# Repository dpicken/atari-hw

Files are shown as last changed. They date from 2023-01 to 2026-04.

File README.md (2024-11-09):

# atari-hw

Atari 8-bit hardware projects.

- [Small Form Factor (SFF) Atari 8-bit compatible system](/doc/sbc.md)
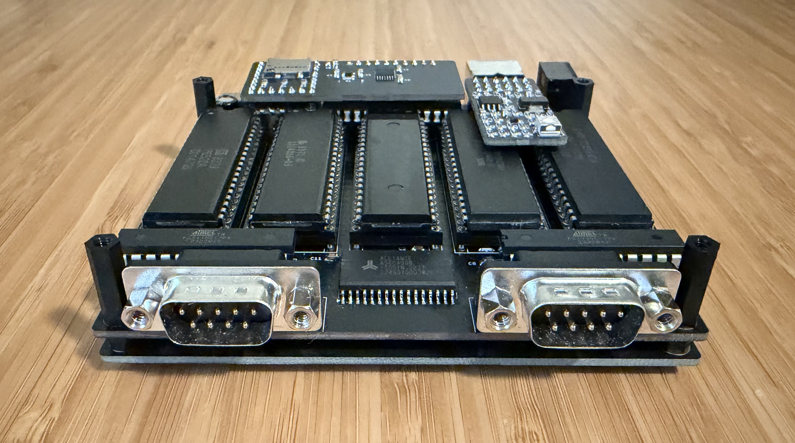
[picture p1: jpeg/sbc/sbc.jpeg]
  

- [USB Keyboard Controller for Atari XL/XE computers](/doc/keyboard-usb-qtpy.md)
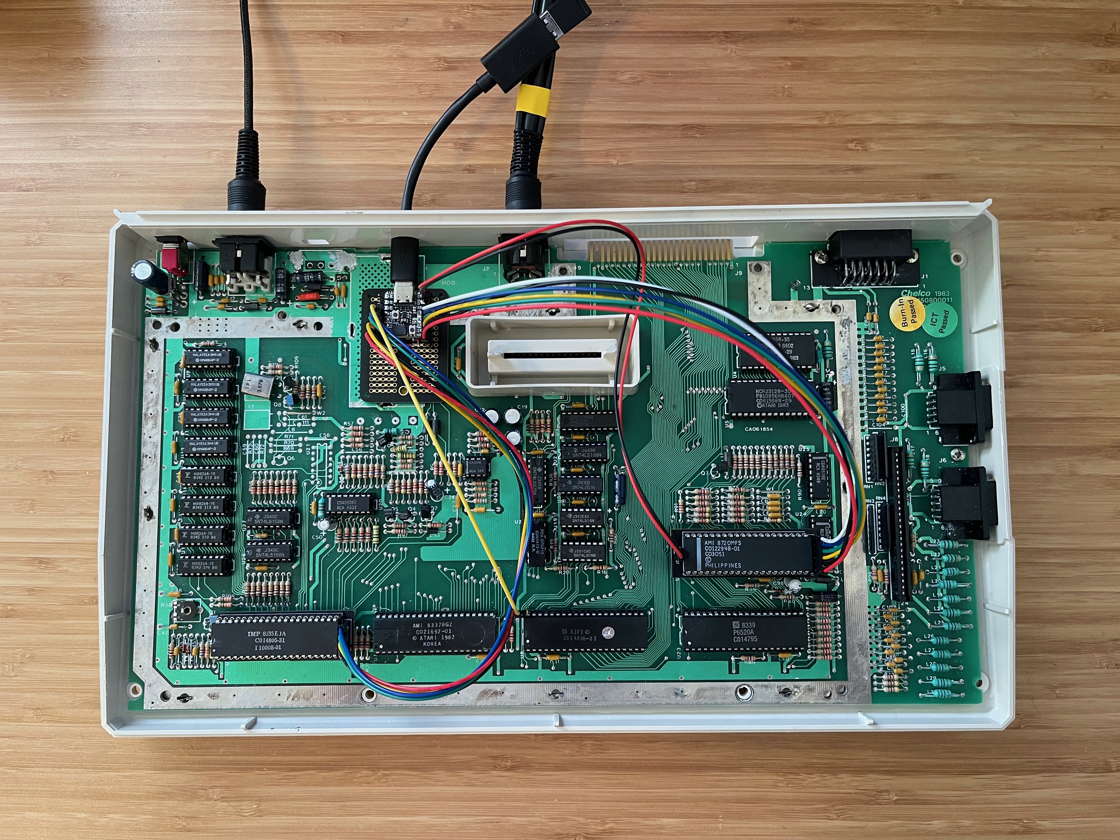
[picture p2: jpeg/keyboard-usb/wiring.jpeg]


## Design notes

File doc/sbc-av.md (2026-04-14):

# SFF Audio/Video adapter

Audio/video adapter for the [SFF system](https://github.com/dpicken/atari-hw/blob/master/doc/sbc.md).

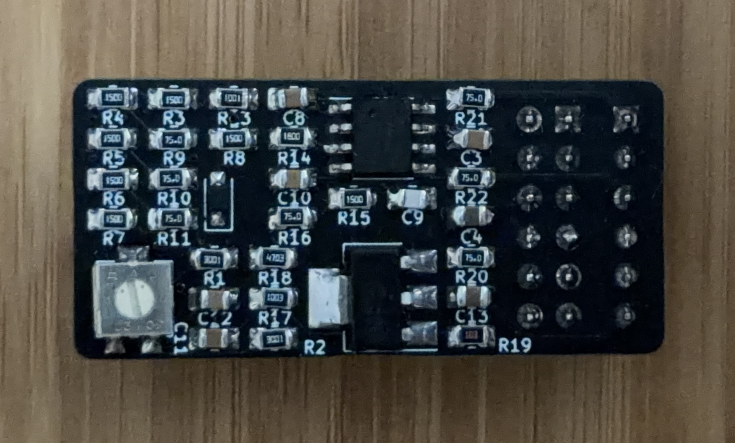
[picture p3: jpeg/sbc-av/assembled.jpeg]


- [Schematic](/pdf/sbc-av-schematic.pdf)
- [Layout](/pdf/sbc-av-layout.pdf)
- [Gerber](https://github.com/dpicken/atari-hw/raw/master/gerber/sbc-av.zip)
- [BOM](/pdf/sbc-av-bom.pdf)

# Assembly notes

Solder the FMS6400 first, then the remaining SMT components.  Ensure the pin headers are installed on the rear of the board.

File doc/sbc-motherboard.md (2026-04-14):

# SFF Motherboard

Motherboard for the [SFF system](https://github.com/dpicken/atari-hw/blob/master/doc/sbc.md).

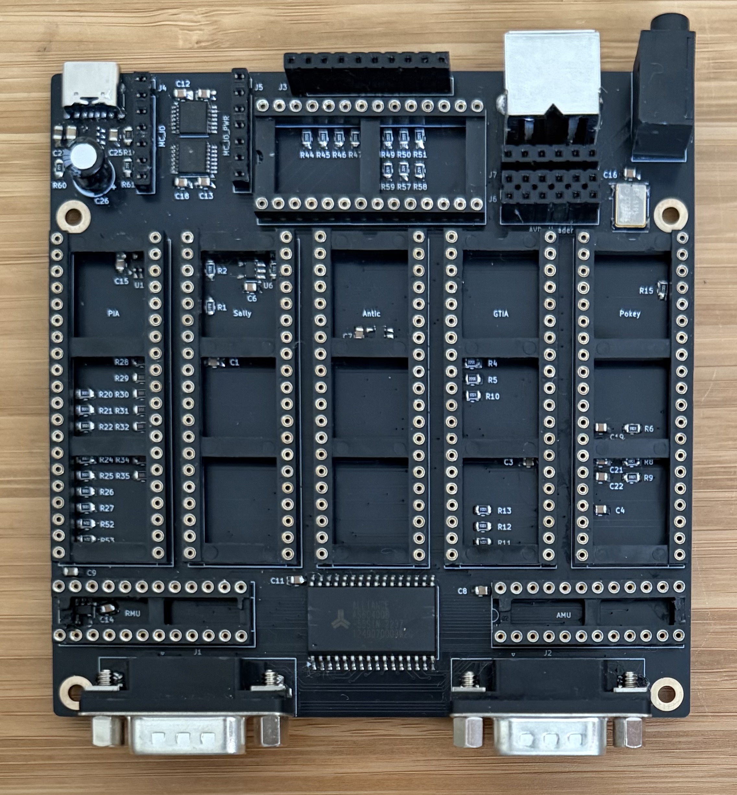
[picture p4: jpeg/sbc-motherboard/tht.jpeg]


- [Schematic](/pdf/sbc-schematic.pdf)
- [Layout](/pdf/sbc-layout.pdf)
- [Gerber](https://github.com/dpicken/atari-hw/raw/master/gerber/sbc.zip)
- [BOM](/pdf/sbc-bom.pdf)

# Assembly notes

Solder the SMT components first, starting with the power section, then the voltage level translators, then the oscillator and finally the remaining components:

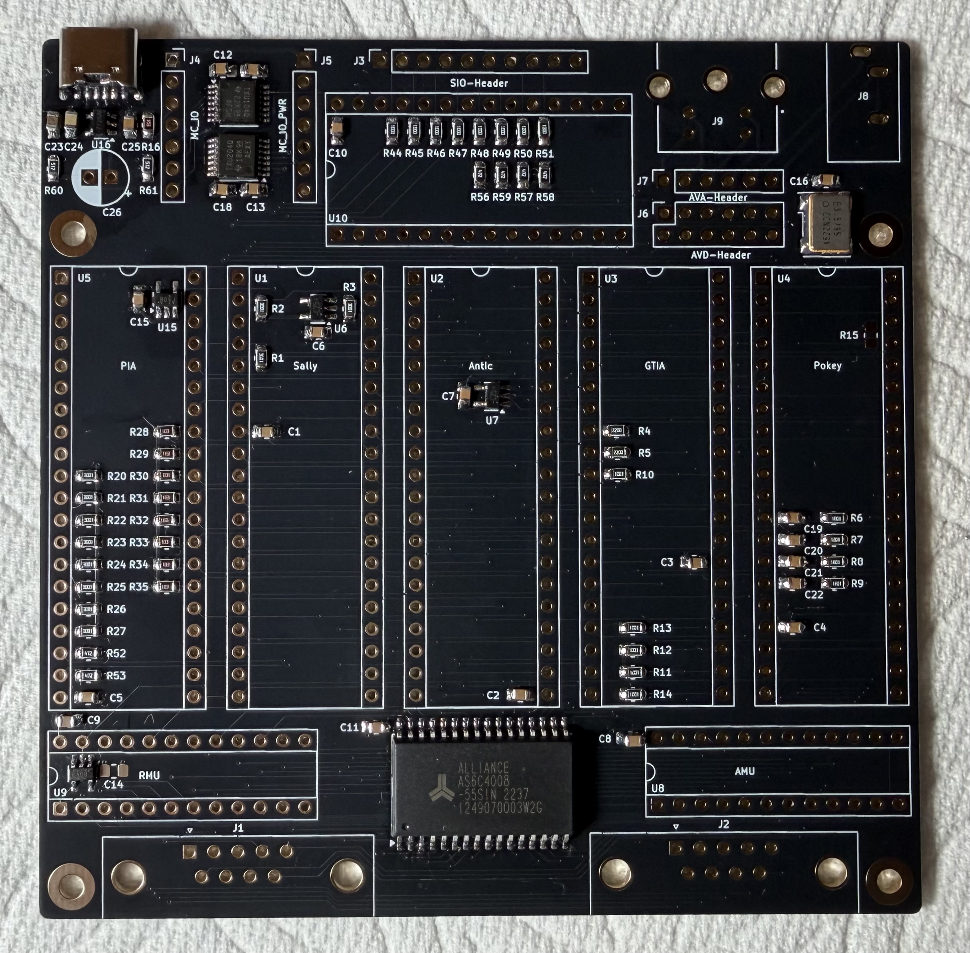
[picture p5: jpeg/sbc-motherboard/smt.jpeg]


Solder the THT components, then install the ICs (flash the ROM, AMU and RMU first):

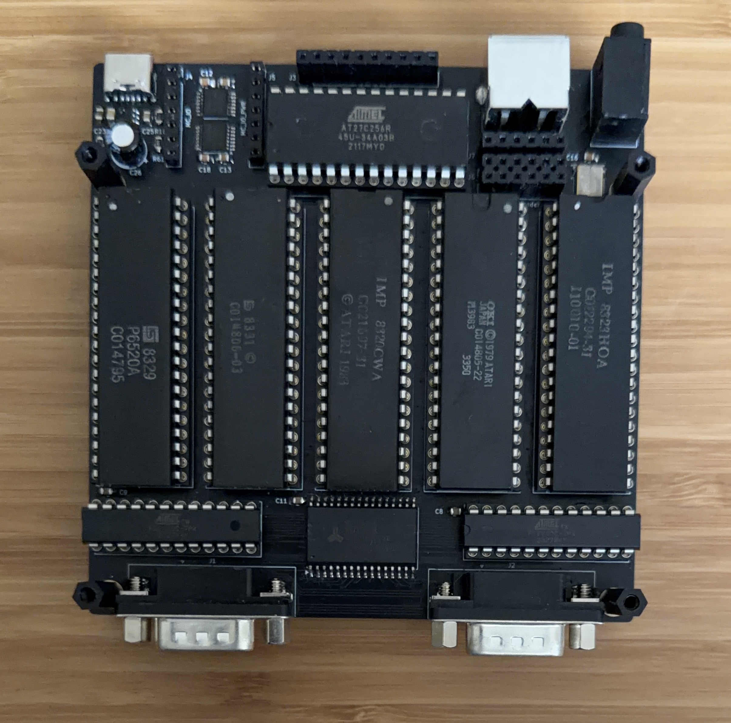
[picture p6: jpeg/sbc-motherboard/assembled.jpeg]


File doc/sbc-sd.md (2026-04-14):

# SFF SD card adapter

An SD card adapter / SIO peripheral emulator for the [SFF system](https://github.com/dpicken/atari-hw/blob/master/doc/sbc.md).

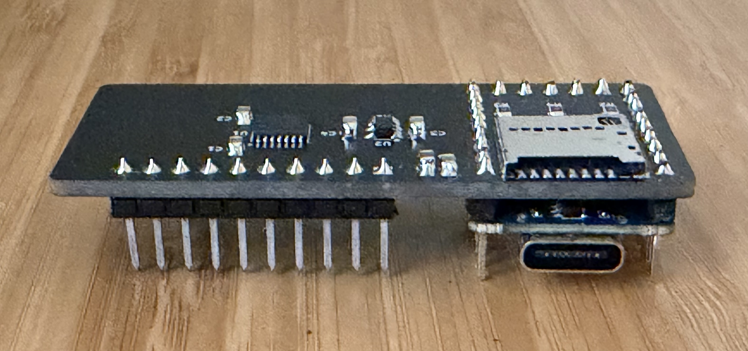
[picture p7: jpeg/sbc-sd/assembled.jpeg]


- [Schematic](/pdf/sbc-sd-schematic.pdf)
- [Layout](/pdf/sbc-sd-layout.pdf)
- [Gerber](https://github.com/dpicken/atari-hw/raw/master/gerber/sbc-sd.zip)
- [BOM](/pdf/sbc-sd-bom.pdf)

The firmware supports:

- Emulating an Atari disk drive (D1)
- Loading ATR and XEX images from the microcontroller's flash
- Loading ATR and XEX images from an exFat formatted SD card

# Assembly notes

Solder the SD card socket first, then the remaining SMT components:

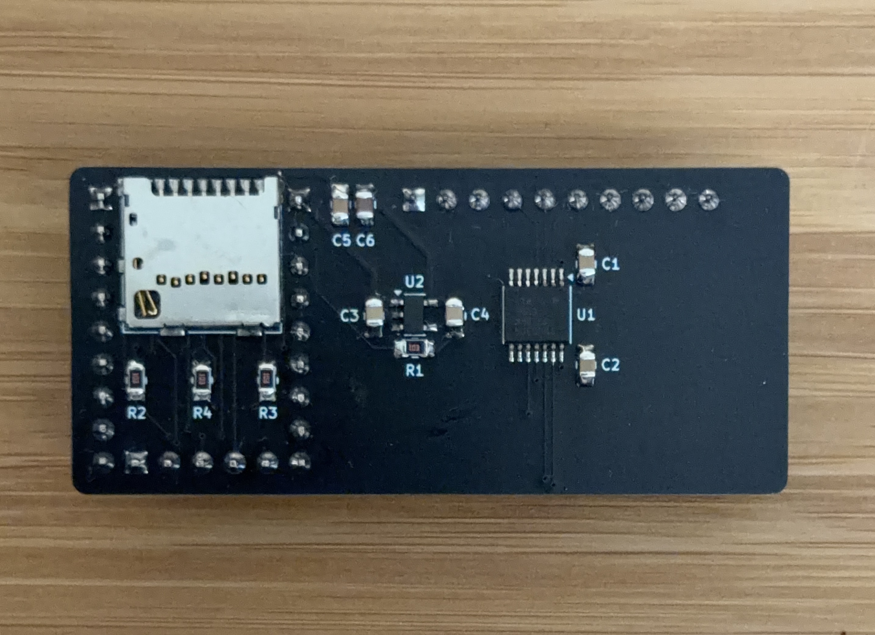
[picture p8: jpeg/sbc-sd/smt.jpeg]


Solder pin headers to the rear of the board and finally the waveshare RP2040:

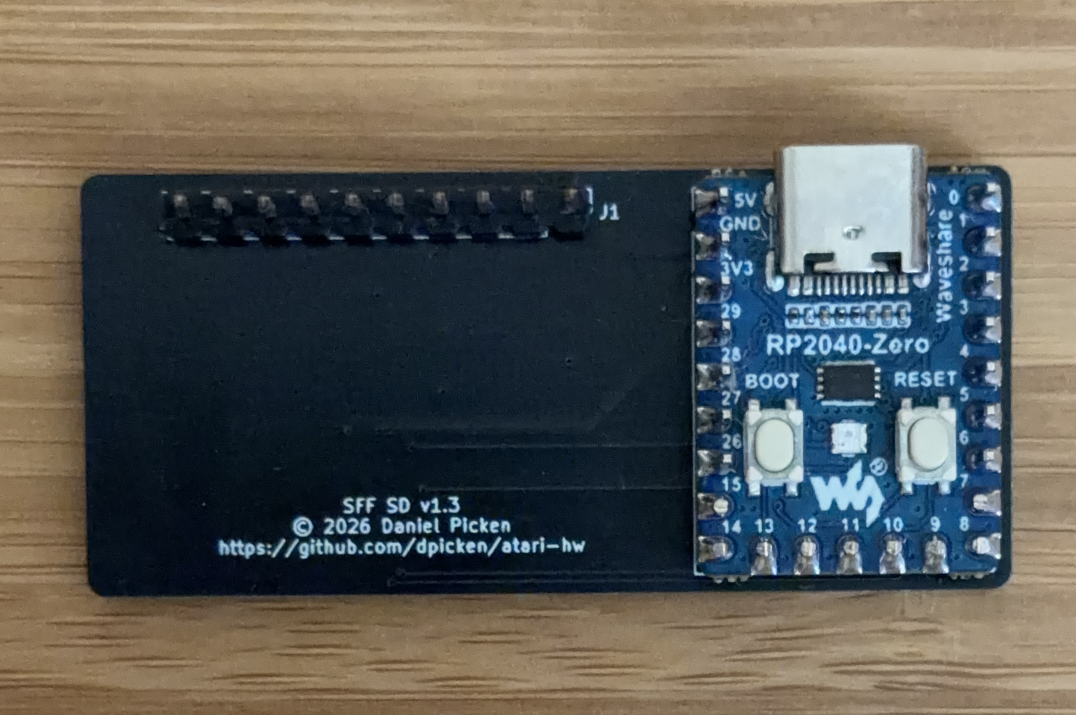
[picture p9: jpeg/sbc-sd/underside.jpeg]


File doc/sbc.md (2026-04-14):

# Small Form Factor (SFF) Atari 8-bit compatible system

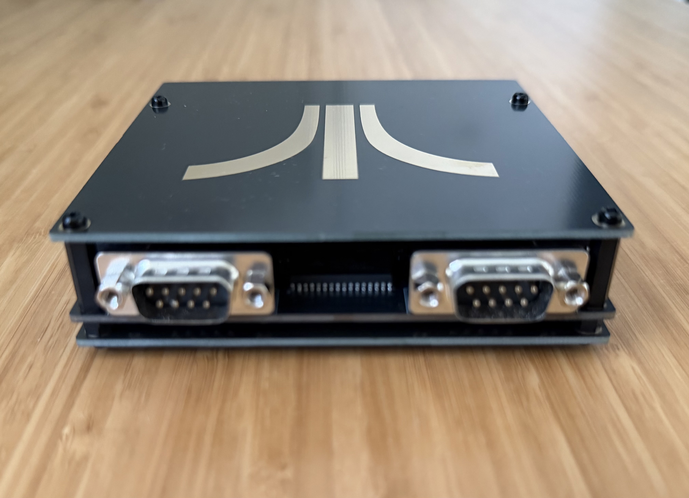
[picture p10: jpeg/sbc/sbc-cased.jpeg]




Specs:

- Original Atari chipset (Sally, Antic, GTIA, Pokey, PIA)
- Two simple programmable logic devices (ATF22V10C) implement address-space decoding and extended RAM:
  - AMU ("Address Management Unit") decodes the 16 bit address space
  - RMU ("Ram Management Unit") supports 320 KiB (compy or rambo) or 128 KiB (130XE) or 64 KiB (65XE) RAM
- 32 KiB ROM (OS, BASIC)
- Audio/Video header
- S-Video connector
- 3.5mm audio socket
- SIO header
- USB-C power socket
- Raspberry Pi RP-series microcontroller provides:
  - USB keyboard interface
  - SIO disk drive (D1)
  - SIO file system device (ATR and XEX image selection)
  - microSD card support (SD, SDHC, SDXC, exFAT)

Hardware:

- [SFF Motherboard](/doc/sbc-motherboard.md)
- [SFF Audio/Video adapter](/doc/sbc-av.md)
- [SFF SD card adapter](/doc/sbc-sd.md)
- [SFF Case](/doc/sbc-case.md)

Key map:

| USB Key  | Atari Key or Action |
|---|---|
| F1 | Help |
| F2 | Start |
| F3 | Select |
| F4 | Option |
| F10 | D1: insert !sbc-filer.xex (file system UI) |
| F11 | D1: eject |
| F12 | Reset |
| Ctrl-F12 | Toggle power on/off |

Atari self-test:

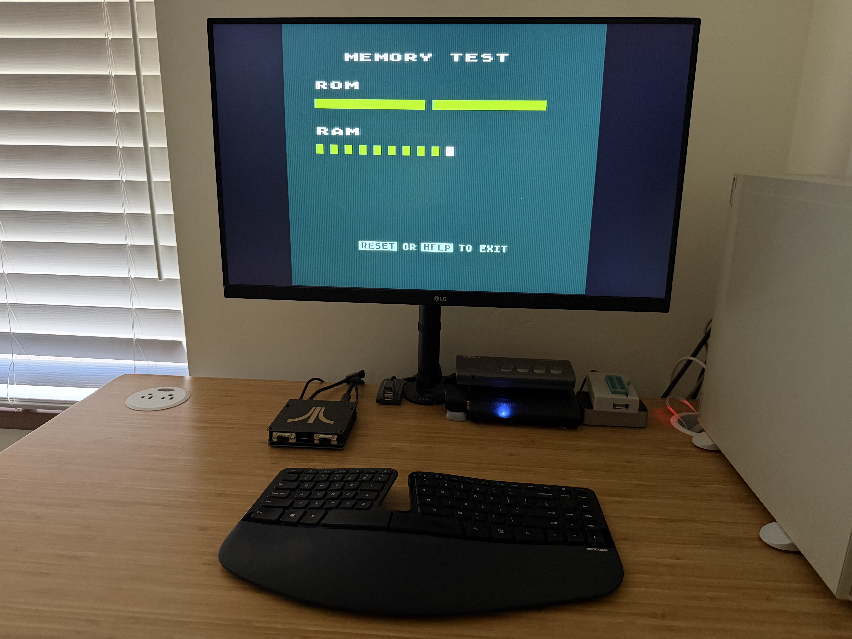
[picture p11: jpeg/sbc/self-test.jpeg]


File System UI:



Load a game:

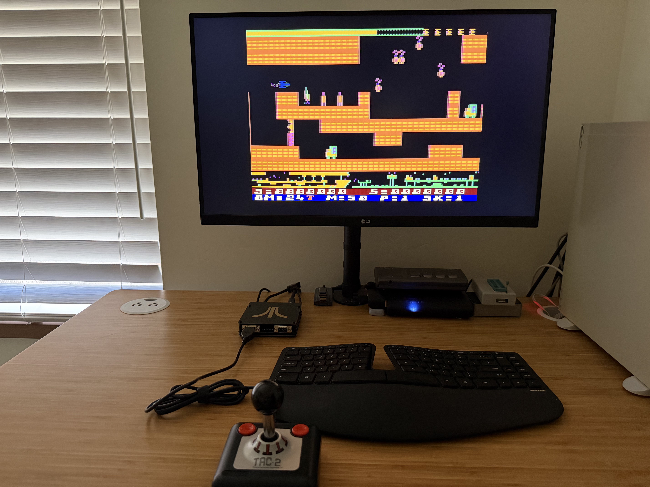
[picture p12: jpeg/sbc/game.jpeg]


## Build ROM, AMU, RMU and RP-series microcontroller images

Clone the following repos:

    git clone https://github.com/dpicken/atari-hw.git
    git clone https://github.com/dpicken/atari-fw.git
    git clone https://github.com/dpicken/fab.git

Acquire Atari's XL/XE OS and BASIC ROM images and copy them to `./atari-hw/third-party/rom`, e.g.

    cp ~/Downloads/OS_REV3_XE.rom ./atari-hw/third-party/rom/os.rom
    cp ~/Downloads/BASIC_C.rom    ./atari-hw/third-party/rom/basic.rom
    make -C ./atari-hw roms

Optional: To (re)build the (pre-built) AMU and RMU images, install [rust](https://www.rust-lang.org/tools/install), then install [galette](https://github.com/simon-frankau/galette), e.g.

    git clone https://github.com/simon-frankau/galette
    bash -c "cd galette; cargo build --release"
    cp galette/target/release/galette ~/bin/
    PATH=$PATH:~/bin
    make -C ./atari-hw distribute

Optional: To (re)build the (pre-built) RP-series microcontroller firmware:

    make -C ./atari-fw distribute

## Install images

The ROM, AMU and RMU can be programmed with a `TL866 II Plus` and the `minipro` software.  Install the minipro, e.g.

    brew install minipro

Change into the atari-hw repo:

    cd ./atari-hw

### AMU

To program the AMU with support for 320 KiB RAM (compy, separate Sally/Antic banking):

    make install-prebuilt-jed-amu320compy

To program the AMU for all other RAM configurations:

    make install-prebuilt-jed-amu

### RMU

To program the RMU with support for 320 KiB RAM (compy, separate Sally/Antic banking):

    make install-prebuilt-jed-rmu320compy

To program the RMU with support for 320 KiB RAM (rambo, combined Sally/Antic banking):

    make install-prebuilt-jed-rmu320rambo

To program the RMU with support for 128 KiB RAM (130XE, separate Sally/Antic banking):

    make install-prebuilt-jed-rmu130xe

To program the RMU with support for 64 KiB RAM (65XE / 800XL):

    make install-prebuilt-jed-rmu65xe

### ROM

A 27C256 compatible ROM/EPROM/EEPROM provides the OS and BASIC.

To program a AT27C256 OTP ROM:

    make install-sbc-rom-256

To program a W27C512 EEPROM:

    make install-sbc-rom-512

### RP-series microcontroller

The following RP2040/RP2350 boards are supported:

  - [waveshare rp2040 zero](https://www.waveshare.com/rp2040-zero.htm) (supports a USB keyboard, builtin ATR/XEX library and [SFF SD card adapter](https://github.com/dpicken/atari-hw/blob/master/doc/sbc-sd.md))
  - [pimoroni tiny2350](https://shop.pimoroni.com/products/tiny-2350?variant=42092638699603) (supports a USB keyboard and builtin ATR/XEX library)
  - [adafruit qtpy rp2040](https://www.adafruit.com/product/4900) (supports a USB keyboard and builtin ATR/XEX library)

Connect a supported board to the build host, then boot it into it's bootloader (hold the boot button then press and release the reset button).  Next, copy the appropriate firmware to the `RPI-RP2` drive/mount (adjust the `RP_MOUNT` option as necessary)...

To program a waveshare rp2040 zero:

    RP_MOUNT=/Volumes/RPI-RP2 make install-prebuilt-rp-fw-waveshare_rp2040_zero

To program a pimoroni tiny2350:

    RP_MOUNT=/Volumes/RP2350 make install-prebuilt-rp-fw-pimoroni_tiny2350

To program an adafruit qtpy rp2040:

    RP_MOUNT=/Volumes/RPI-RP2 make install-prebuilt-rp-fw-adafruit_qtpy_rp2040

(See [atari-fw](https://github.com/dpicken/atari-fw) for the firmware source and for instructions for building firmware with a custom builtin ATR/XEX library).

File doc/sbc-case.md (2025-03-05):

# SFF Case

A skeletal "case" - lid and base - for the [SFF system](https://github.com/dpicken/atari-hw/blob/master/doc/sbc.md).

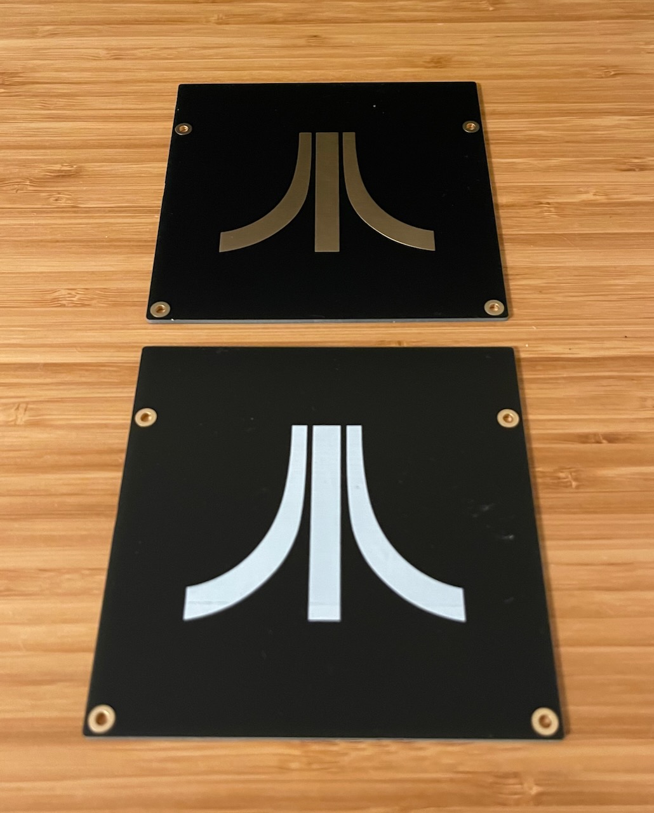
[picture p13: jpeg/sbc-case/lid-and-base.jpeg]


- [Layout](/pdf/sbc-case-layout.pdf)
- [Gerber (lid)](https://github.com/dpicken/atari-hw/raw/master/gerber/sbc-case-cu.zip)
- [Gerber (base)](https://github.com/dpicken/atari-hw/raw/master/gerber/sbc-case-silk.zip)
- M2.5 standoffs (e.g. [brass](https://www.amazon.com/dp/B075K3QBMX?_encoding=UTF8&psc=1&ref_=cm_sw_r_cp_ud_dp_07SERFYACEF07RKSJ5DF) or [nylon](https://www.amazon.com/dp/B07DCM1LGF?_encoding=UTF8&psc=1&ref_=cm_sw_r_cp_ud_dp_D1Y9YNHXQJMQRCN7T3VB))

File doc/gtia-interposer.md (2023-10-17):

# GTIA Interposer

Breaks out the start, select and option signals and performs 5V <-> 3.3V level conversion:

- [Schematic](/pdf/gtia-interposer-schematic.pdf)
- [Layout](/pdf/gtia-interposer-layout.pdf)
- [BOM](/pdf/gtia-interposer-bom.md)

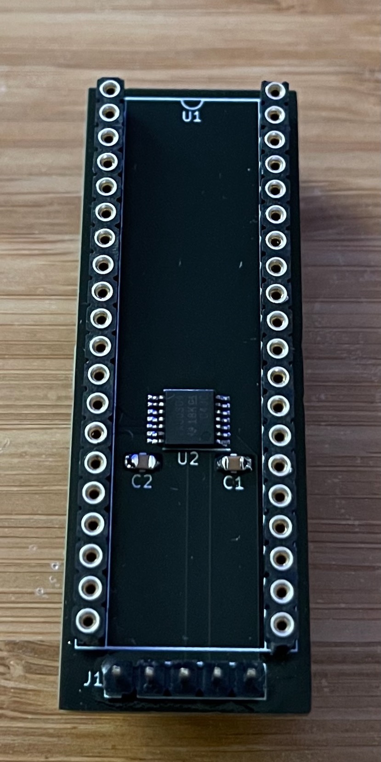
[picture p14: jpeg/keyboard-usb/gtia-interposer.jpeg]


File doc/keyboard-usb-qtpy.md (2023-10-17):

# USB Keyboard Controller

Proof-of-concept USB keyboard controller for 8-bit Atari systems.

Limitations:

- Atari keyboard is not usable whilst the controller is powered (the POKEY and GTIA level shifters are permanently enabled).
- The controller's /RESET signal is not level shifted (not a problem in practice)

## BOM

- [Adafruit QT Py RP2040](https://www.adafruit.com/product/4900)
- [POKEY Interposer](/doc/pokey-interposer.md)
- [GTIA Interposer](/doc/gtia-interposer.md)
- Breadboard
- 2.54 mm pin headers
- 6 pin, 5 pin and 2 pin 2.54mm female jumper leads

## Assembly

It's advisable to flash the QT Py prior to installation.

Connect the QT Py to the build host, then boot it into it's bootloader (hold the boot button then press and release the reset button).  Next, copy the firmware to the `RPI-RP2` drive/mount (adjust the `RP2040_MOUNT` option as necessary):

    RP2040_MOUNT=/Volumes/RPI-RP2 RP2040_BOARD=adafruit_qtpy_rp2040 make install-prebuilt-rp2040-fw

(See [atari-fw](https://github.com/dpicken/atari-fw) for the firmware source).

If necessary, desolder POKEY and GTIA from the Atari PCB and install DIP sockets in their place.

The interposers use SMD components.  It is possible to hand solder them.  Basic requirements are a temperature controlled soldering iron, magnification, fine tweezers, plenty of flux, leaded solder and steady hands:

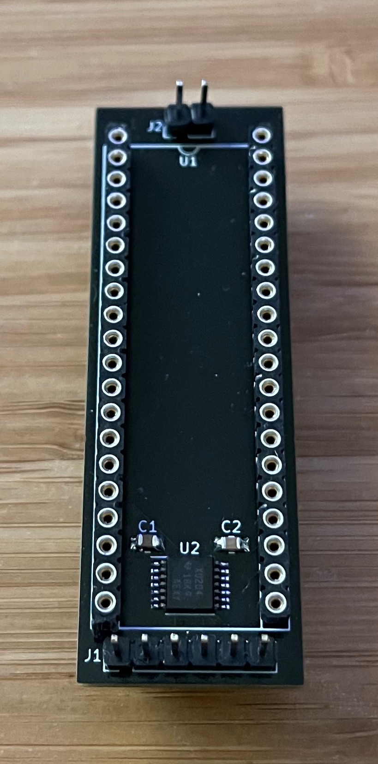
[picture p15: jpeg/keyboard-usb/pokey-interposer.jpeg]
 

The SIP socket strips are mounted on the top side of the interposers and soldered.  DIP sockets between an interposer and the Atari PCB socket may be necessary to establish good contact.  Insert GTIA and POKEY into their interposer:

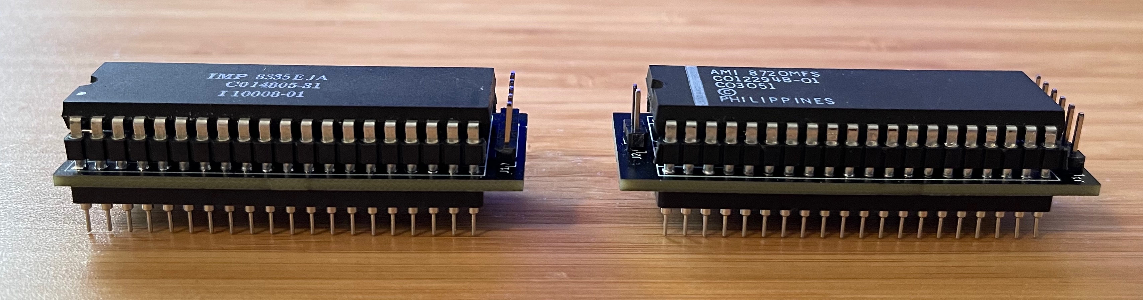
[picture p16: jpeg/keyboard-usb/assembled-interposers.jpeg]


Install the assembled interposers:

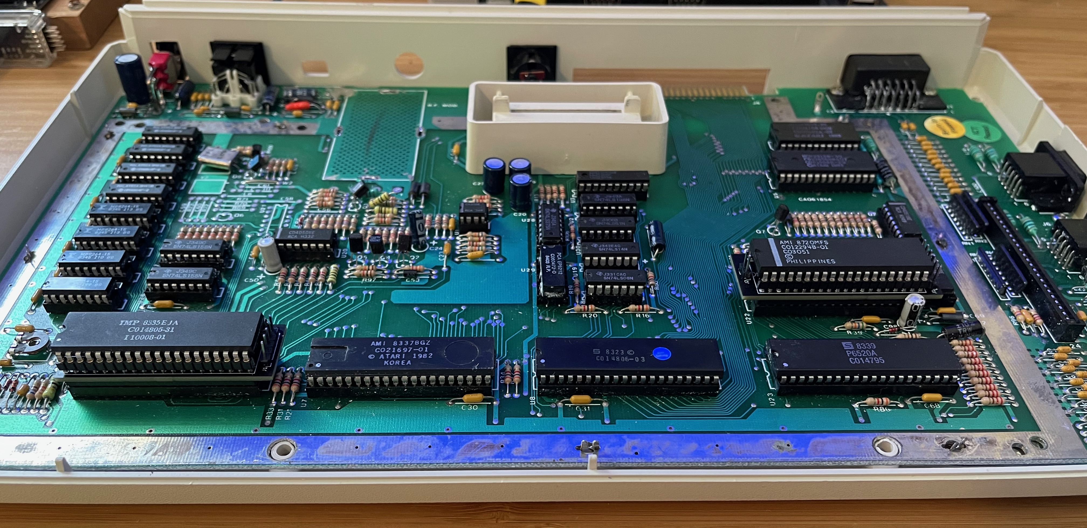
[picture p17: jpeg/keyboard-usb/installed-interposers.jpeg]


Bridge the 5V USB host jumper on the underside of the QT Py:

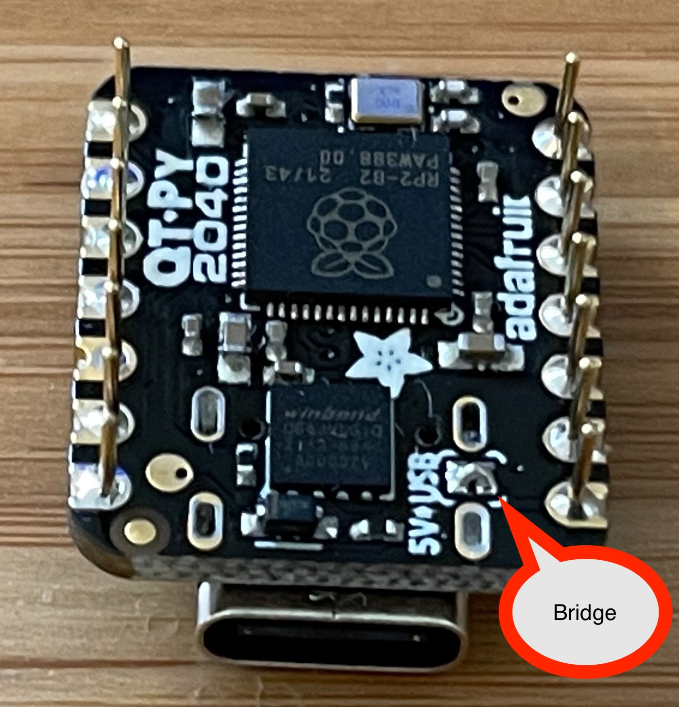
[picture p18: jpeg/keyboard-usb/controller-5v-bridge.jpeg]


Build a break-out board (on a soldered or solderless breadboard):

|QT Py|POKEY interposer J1|POKEY interposer J2|GTIA interposer J1 |65O2C  |
|-----|---|---|---|---|
|5V | |Pin 1 | | |
|3V |Pin 1 | |Pin 1 | |
|GND  |Pin 2 |Pin 2 |Pin 2 | |
|RX |Pin 3 | | | |
|SCK  |Pin 4 | | | |
|MI |Pin 5 | | | |
|MO |Pin 6 | | | |
|TX | | |Pin 3 | |
|SCL  | | |Pin 4 | |
|SDA  | | |Pin 5 | |
|A3 | | | |Pin 40 |

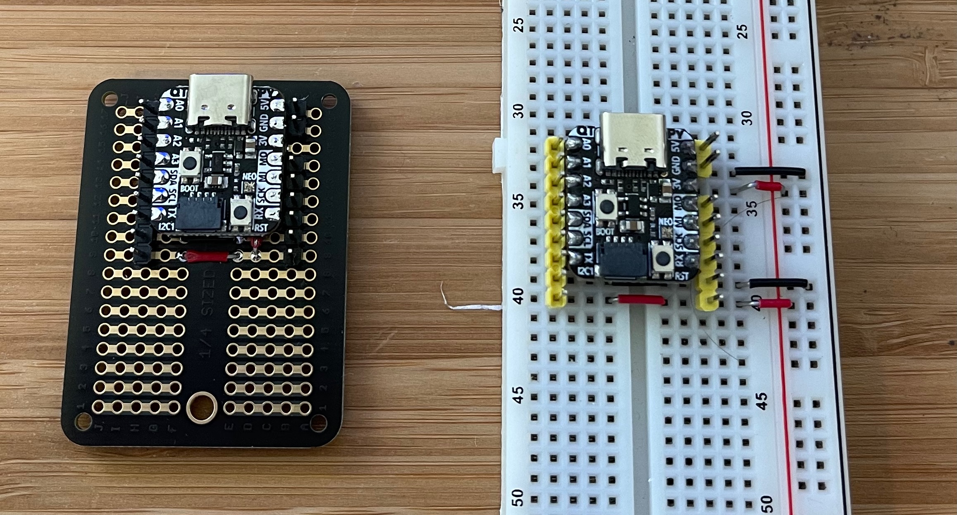
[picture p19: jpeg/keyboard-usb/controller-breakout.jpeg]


Connect the controller to the interposers with jumper cables:



Connect a USB keyboard:

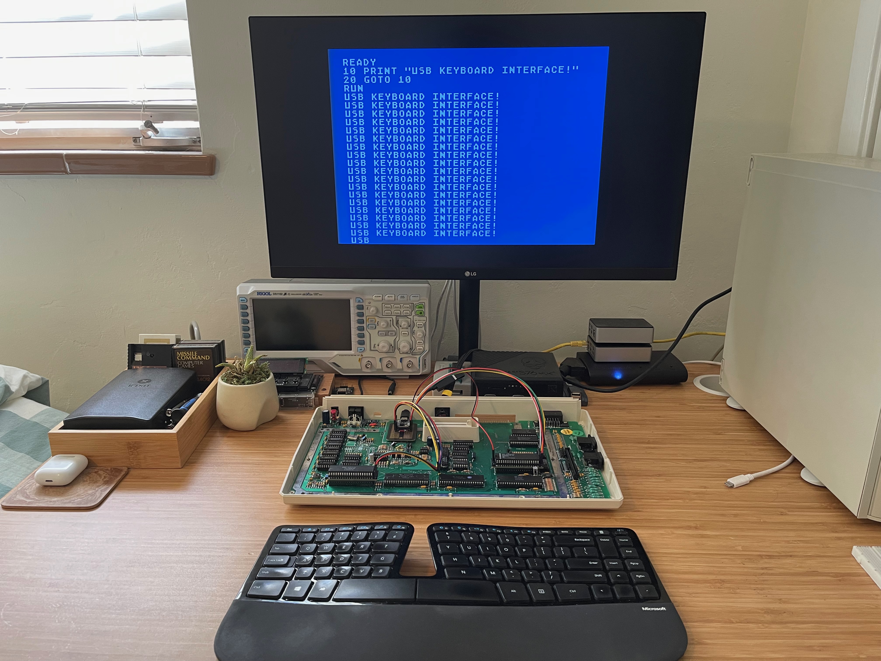
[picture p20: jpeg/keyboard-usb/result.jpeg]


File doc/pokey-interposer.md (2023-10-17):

# POKEY Interposer

Breaks out the K0, K5, KR1 and KR2 signals and performs 5V <-> 3.3V level conversion:

- [Schematic](/pdf/pokey-interposer-schematic.pdf)
- [Layout](/pdf/pokey-interposer-layout.pdf)
- [BOM](/pdf/pokey-interposer-bom.md)



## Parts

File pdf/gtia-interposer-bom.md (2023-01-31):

# GTIA Interposer BOM

|References|Quantity|Description|
|-|-|-|
|PCB|1|[Gerber](/gerber/gtia-interposer.zip), 0.8mm|
|C1, C2|2|[0.1uF MLCC capacitor, 0805](https://www.mouser.com/ProductDetail/80-C0805C104J1RECAUT)|
|J1|1|1x5 pin header, 2.54mm|
|U1|1|[SIP socket](https://www.newark.com/mill-max/311-93-164-41-001000/sip-socket-64-position-through/dp/17C4915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)|
|U2|1|[TXU0304PWR](https://www.mouser.com/ProductDetail/Texas-Instruments/TXU0304PWR?qs=QNEnbhJQKvZVYXIKZoXs0A%3D%3D)|

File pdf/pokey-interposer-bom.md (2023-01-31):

# Pokey Interposer BOM

|References|Quantity|Description|
|-|-|-|
|PCB|1|[Gerber](/gerber/pokey-interposer.zip), 0.8mm|
|C1, C2|2|[0.1uF MLCC capacitor, 0805](https://www.mouser.com/ProductDetail/80-C0805C104J1RECAUT)|
|J1|1|1x6 pin header, 2.54mm|
|J2|1|1x2 pin header, 2.54mm|
|U1|1|[SIP socket](https://www.newark.com/mill-max/311-93-164-41-001000/sip-socket-64-position-through/dp/17C4915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)|
|U2|1|[TXU0204PWR](https://www.mouser.com/ProductDetail/Texas-Instruments/TXU0204QPWRQ1?qs=QNEnbhJQKvbo%252BW7%2Fo1U3Qg%3D%3D)|

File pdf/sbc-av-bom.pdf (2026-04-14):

### sbc-av

Ref | Qnty | Value | Footprint | Vendor
C1, C2, C3, C7, C8, C10, C11, C12 | 8 | 0.1uF | Capacitor_SMD:C_0805_2012Metric_Pad1.18x1.45mm_HandSolder | https://www.mouser.com/ProductDetail/80-C0805C104J1RECAUT
C4, C13 | 2 | 10uF | Capacitor_SMD:C_0805_2012Metric_Pad1.18x1.45mm_HandSolder | https://www.mouser.com/ProductDetail/KEMET/C0805C106K8RACTU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
C5, C6 | 2 | 3.3uF | Capacitor_SMD:C_0805_2012Metric_Pad1.18x1.45mm_HandSolder | https://www.mouser.com/ProductDetail/KEMET/C0805C335K4PACTU?qs=p39qgscUv00TDoKitDBNnA==
C9 | 1 | 100pF | Capacitor_SMD:C_0805_2012Metric_Pad1.18x1.45mm_HandSolder | https://www.mouser.com/ProductDetail/KEMET/C0805C101J5RACTU?qs=1CrpdQ4AkN/JNeoQfmjuPQ==
D1 | 1 | BAT48JFILM | Diode_SMD:D_SOD-323_HandSoldering | https://www.mouser.com/ProductDetail/STMicroelectronics/BAT48JFILM?qs=jZi1jxfVU96ub22u%2BA2DtA==
J1 | 1 | AVD-Header | Connector_PinHeader_2.54mm:PinHeader_2x06_P2.54mm_Vertical | https://www.mouser.com/ProductDetail/Amphenol-Commercial-Products/G800W590018EU?qs=f9yNj16SXrJ2iQOlqHgQ/g==
J2 | 1 | AVA-Header | Connector_PinHeader_2.54mm:PinHeader_1x06_P2.54mm_Vertical | https://www.mouser.com/ProductDetail/Amphenol-Commercial-Products/G800W302018EU?qs=f9yNj16SXrLA3jMaFoRlOg==
Q1 | 1 | PZT2222A | Package_TO_SOT_SMD:SOT-223-3_TabPin2 | https://www.mouser.com/ProductDetail/onsemi/PZT2222AT1G?qs=xZq1yRCsb1df8552Y4NpWQ==
R1, R2 | 2 | 3K | Resistor_SMD:R_0805_2012Metric_Pad1.20x1.40mm_HandSolder | https://www.mouser.com/ProductDetail/Panasonic/ERJ-P06F3001V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
R3, R4, R5, R6, R7, R8, R15 | 7 | 150R | Resistor_SMD:R_0805_2012Metric_Pad1.20x1.40mm_HandSolder | https://www.mouser.com/ProductDetail/Panasonic/ERJ-P06D1500V?qs=18kBAoNi3c%2BFXxCt8eyIyw==
R9, R10, R11, R16, R20, R21, R22 | 7 | 75R | Resistor_SMD:R_0805_2012Metric_Pad1.20x1.40mm_HandSolder | https://www.mouser.com/ProductDetail/Panasonic/ERJ-P06D75R0V?qs=18kBAoNi3c%2B6dPCNnYzSiQ==
R13 | 1 | 1K | Resistor_SMD:R_0805_2012Metric_Pad1.20x1.40mm_HandSolder | https://www.mouser.com/ProductDetail/Panasonic/ERJ-P06F1001V?qs=ECfqV4X0oBP%2BH9YeKDUwsA==
R14 | 1 | 180R | Resistor_SMD:R_0805_2012Metric_Pad1.20x1.40mm_HandSolder | https://www.mouser.com/ProductDetail/Panasonic/ERJ-P06F1800V?qs=iIVTEDlrHA2EVhThhrzqlA==
R17 | 1 | 100K | Resistor_SMD:R_0805_2012Metric_Pad1.20x1.40mm_HandSolder | https://www.mouser.com/ProductDetail/Panasonic/ERJ-P06F1003V?qs=sWbhZyXmMVdmF1QzbbgLKA==
R18 | 1 | 470K | Resistor_SMD:R_0805_2012Metric_Pad1.20x1.40mm_HandSolder | https://www.mouser.com/ProductDetail/Panasonic/ERJ-P06F4703V?qs=iIVTEDlrHA0mppp24nmuLg==
R19 | 1 | 10K | Resistor_SMD:R_0805_2012Metric_Pad1.20x1.40mm_HandSolder | https://www.mouser.com/ProductDetail/Panasonic/ERJ-P06F1002V?qs=Zyl8A9hlmJpSDn8Y2yUh3g==
RV1 | 1 | 10K | Potentiometer_SMD:Potentiometer_Bourns_3314G_Vertical | https://www.mouser.com/ProductDetail/Bourns/3314G-1-103E?qs=5DXzRwmrLHHE6mxfh4g4uw==
U1 | 1 | MAX1683 | Package_TO_SOT_SMD:SOT-23-5 | https://www.mouser.com/ProductDetail/Analog-Devices-Maxim-Integrated/MAX1683EUK+T?qs=Mqkh4jHMT8y6s4KDA7LkCA==
U2 | 1 | CD74HCT367E | Package_SO:SOIC-16_3.9x9.9mm_P1.27mm | https://www.mouser.com/ProductDetail/Texas-Instruments/CD74HCT367M96?qs=xFfolx0DHx3dFn/ua36eJg==
U3 | 1 | FMS6400 | Package_SO:SOIC-8_3.9x4.9mm_P1.27mm | https://www.ebay.co.uk/itm/171512497884

1

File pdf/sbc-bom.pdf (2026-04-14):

### sbc

Reference | Qty | Value | Footprint | Vendor
C1,C2,C3,C4,C5,C6,C7,C10,C11,C12,C13,C14,C15,C16,C17,C18,C25 | 17 | 0.1uF | Capacitor_SMD:C_0805_2012Metric_Pad1.18x1.45mm_HandSolder | https://www.mouser.com/ProductDetail/80-C0805C104J1RECAUT
C8,C9 | 2 | 0.22uF | Capacitor_SMD:C_0805_2012Metric_Pad1.18x1.45mm_HandSolder | https://www.mouser.com/ProductDetail/KEMET/C0805C224J1RECAUTO?qs=MLItCLRbWswHU/2BqeGewQ==
C19,C20,C21,C22 | 4 | 47nF | Capacitor_SMD:C_0805_2012Metric_Pad1.18x1.45mm_HandSolder | https://www.mouser.com/ProductDetail/KEMET/C0805C473J1RACTU?qs=qyvGPs6PiyAoDuZ13uE02Q==
C23 | 1 | 10uF | Capacitor_SMD:C_0805_2012Metric_Pad1.18x1.45mm_HandSolder | https://www.mouser.com/ProductDetail/KEMET/C0805C106K8RACTU?qs=iP0bYSAMAFqUyr6Ql6ZwXw==
C24 | 1 | 1uF | Capacitor_SMD:C_0805_2012Metric_Pad1.18x1.45mm_HandSolder | https://www.mouser.com/ProductDetail/KEMET/C0805C105K5RACTU?qs=iP0bYSAMAFrBrUflcErrLQ==
C26 | 1 | 220uF | Capacitor_THT:CP_Radial_D6.3mm_P2.50mm | https://www.mouser.com/ProductDetail/Panasonic/ECE-A0JKA221?qs=oTewU%2BGizQbeu7AvPjLzZw==
J1,J2 | 2 | DE9_Pins_MountingHoles | Connector_Dsub:DSUB-9_Pins_Horizontal_P2.77x2.84mm EdgePinOffset4.94mm_Housed_MountingHolesOffset4.94mm | https://www.questcomp.com/part/4/pdi-09s-5-rg30/433024203
J3 | 1 | SIO-Header | Connector_PinSocket_2.54mm:PinSocket_1x10_P2.54mm_Vertical | https://www.mouser.com/ProductDetail/3M-Electronic-Solutions-Division/929850-01-10-RB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
J4, J5 | 2 | MC_IO MC_IO_PWR | Connector_PinSocket_2.54mm:PinSocket_1x07_P2.54mm_Vertical | https://www.mouser.com/ProductDetail/3M-Electronic-Solutions-Division/929850-01-07-RA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
J6 | 1 | AVD-Header | Connector_PinSocket_2.54mm:PinSocket_2x06_P2.54mm_Vertical | https://www.mouser.com/ProductDetail/3M-Electronic-Solutions-Division/929852-01-06-RA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
J7 | 1 | AVA-Header | Connector_PinSocket_2.54mm:PinSocket_1x06_P2.54mm_Vertical | https://www.mouser.com/ProductDetail/3M-Electronic-Solutions-Division/929850-01-06-RA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
J8 | 1 | AudioOut-Connector | Connector_Audio:Jack_3.5mm_CUI_SJ1-3533NG_Horizontal | https://www.mouser.com/ProductDetail/CUI-Devices/SJ1-3533NG?qs=WyjlAZoYn53GjNky%2BNFGCA==
J9 | 1 | VideoOut-Connector | Connector_MiniDIN:57492631 | https://www.questcomp.com/part/4/5749263-1/63422316
J10 | 1 | USB_C_Receptacle_PowerOnly_6P | Connector_USB:USB_C_Receptacle_GCT_USB4125-xx-x_6P_TopMnt_Horizontal | https://www.mouser.com/ProductDetail/GCT/USB4125-GF-A-0190?qs=QNEnbhJQKvbCz4hEJBS24w==
R1,R2,R3,R20,R21,R22,R23,R24,R25,R26,R27 | 11 | 3K | Resistor_SMD:R_0805_2012Metric_Pad1.20x1.40mm_HandSolder | https://www.mouser.com/ProductDetail/Panasonic/ERJ-P06F3001V?qs=iIVTEDlrHA23rU%2BVL8oFPQ==
R4,R5,R36,R37,R38,R39,R40,R41,R42,R43 | 10 | 220R | Resistor_SMD:R_0805_2012Metric_Pad1.20x1.40mm_HandSolder | https://www.mouser.com/ProductDetail/Panasonic/ERJ-P06F2200V?qs=iIVTEDlrHA386ZSEyaXM2A==
R6,R7,R8,R9 | 4 | 1.8K | Resistor_SMD:R_0805_2012Metric_Pad1.20x1.40mm_HandSolder | https://www.mouser.com/ProductDetail/Panasonic/ERJ-P06F1801V?qs=iIVTEDlrHA3BtudUSidCGw==
R10,R11,R12,R13,R14,R15 | 6 | 1K | Resistor_SMD:R_0805_2012Metric_Pad1.20x1.40mm_HandSolder | https://www.mouser.com/ProductDetail/Panasonic/ERJ-P06F1001V?qs=ECfqV4X0oBP%2BH9YeKDUwsA==
R16,R28,R29,R30,R31,R32,R33,R34,R35 | 9 | 10K | Resistor_SMD:R_0805_2012Metric_Pad1.20x1.40mm_HandSolder | https://www.mouser.com/ProductDetail/Panasonic/ERJ-P06F1002V?qs=Zyl8A9hlmJpSDn8Y2yUh3g==
R17,R18,R19 | 3 | 33R | Resistor_SMD:R_0805_2012Metric_Pad1.20x1.40mm_HandSolder | https://www.mouser.com/ProductDetail/Panasonic/ERJ-P06F33R0V?qs=iIVTEDlrHA1ovBs1DfSIuA==
R44,R45,R46,R47,R48,R49,R50,R51 | 8 | 100R | Resistor_SMD:R_0805_2012Metric_Pad1.20x1.40mm_HandSolder | https://www.mouser.com/ProductDetail/Panasonic/ERJ-P06F1000V?qs=JsD2jqDDQCykkNCawV2LnA==
R52,R53,R54,R55,R56,R57,R58,R59 | 8 | 4.7K | Resistor_SMD:R_0805_2012Metric_Pad1.20x1.40mm_HandSolder | https://www.mouser.com/ProductDetail/Panasonic/ERJ-P06J472V?qs=1VWA5LkbEapBfNZYlo8Dpw==
R60,R61 | 2 | 5.1K | Resistor_SMD:R_0805_2012Metric_Pad1.20x1.40mm_HandSolder | https://www.mouser.com/ProductDetail/Panasonic/ERJ-P06J512V?qs=Zyl8A9hlmJpKp56GwTQkVA==
U1 | 1 | Sally | Package_DIP:DIP-40_W15.24mm_Socket | Atari Sally https://www.mouser.com/ProductDetail/Mill-Max/110-99-640-41-001000?qs=WZeyYeqMOWfGzlTYkXtFyQ==
U2 | 1 | Antic | Package_DIP:DIP-40_W15.24mm_Socket | Atari Antic https://www.mouser.com/ProductDetail/Mill-Max/110-99-640-41-001000?qs=WZeyYeqMOWfGzlTYkXtFyQ==
U3 | 1 | GTIA | Package_DIP:DIP-40_W15.24mm_Socket | Atari GTIA https://www.mouser.com/ProductDetail/Mill-Max/110-99-640-41-001000?qs=WZeyYeqMOWfGzlTYkXtFyQ==
U4 | 1 | Pokey | Package_DIP:DIP-40_W15.24mm_Socket | Atari Pokey https://www.mouser.com/ProductDetail/Mill-Max/110-99-640-41-001000?qs=WZeyYeqMOWfGzlTYkXtFyQ==
U5 | 1 | PIA | Package_DIP:DIP-40_W15.24mm_Socket | PIA https://www.mouser.com/ProductDetail/Mill-Max/110-99-640-41-001000?qs=WZeyYeqMOWfGzlTYkXtFyQ==
U6,U7 | 2 | 74AHCT1G125GV,125 | Package_TO_SOT_SMD:SOT-23-5_HandSoldering | https://www.mouser.com/ProductDetail/Nexperia/74AHCT1G125GV125?qs=P62ublwmbi/M9whJE2OaNw==
U8 | 2 | AMU RMU | Package_DIP:DIP-24_W7.62mm_Socket | https://www.mouser.com/ProductDetail/556-AF22V10C7PXhttps://www.mouser.com/ProductDetail/Mill-Max/110-99-324-41-001000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
U10 | 1 | AT27C256R | Package_DIP:DIP-28_W15.24mm_Socket | https://www.mouser.com/ProductDetail/Microchip-Technology-Atmel/AT27C256R-45PU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
U11 | 1 | AS6C4008-55SIN | Package_SO:SOP-32_11.305x20.495mm_P1.27mm | https://www.mouser.com/ProductDetail/Alliance-Memory/AS6C4008-55SIN?qs=E5c5%2Bmu3i38FNE2gqJ2qMg==
U12 | 1 | TXU0104 | Package_SO:TSSOP-14_4.4x5mm_P0.65mm | https://www.mouser.com/ProductDetail/Texas-Instruments/TXU0104QPWRQ1?qs=QNEnbhJQKvavOsVTxSnghg==
U13 | 1 | TXU0204 | Package_SO:TSSOP-14_4.4x5mm_P0.65mm | https://www.mouser.com/ProductDetail/Texas-Instruments/TXU0204QPWRQ1?qs=QNEnbhJQKvbo%2BW7/o1U3Qg==
U14,U15 | 2 | 74AHCT1G04 | Package_TO_SOT_SMD:SOT-23-5_HandSoldering | https://www.mouser.com/ProductDetail/Texas-Instruments/SN74AHCT1G04DBVR?qs=6aLkNDRfRUaZW7hFxpAYUg==
U16 | 1 | AP22814AW5 | Package_TO_SOT_SMD:SOT-23-5 | https://www.mouser.com/ProductDetail/Diodes-Incorporated/AP22814AW5-7?qs=lqAf/iVYw9i7Wkgkb62RxQ==
X1 | 1 | 3.579545 MHz | Oscillator:Oscillator_SMD_SeikoEpson_SG8002CA-4Pin_7.0x5.0mm | https://www.mouser.com/ProductDetail/Epson-Timing/SG7050CCN-3.579545M-HJGA0?qs=4ASt3YYao0WCSUxLeXC5nA==

1

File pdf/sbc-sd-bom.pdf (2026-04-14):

sbc-sd

Reference | Qty | Value | Footprint | Vendor
C1,C2,C5 | 3 | 0.1uF | Capacitor_SMD:C_0805_2012Metric_Pad1.18x1.45mm_HandSolder | https://www.mouser.com/ProductDetail/80-C0805C104J1RECAUT
C3,C4 | 2 | 1uF | Capacitor_SMD:C_0805_2012Metric_Pad1.18x1.45mm_HandSolder | https://www.mouser.com/ProductDetail/KEMET/C0805C105K5RACTU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
C6 | 1 | 4.7uF | Capacitor_SMD:C_0805_2012Metric_Pad1.18x1.45mm_HandSolder | https://www.mouser.com/ProductDetail/KEMET/C0805C475K3RACAUTO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
J1 | 1 | SIO-Header | Connector_PinHeader_2.54mm:PinHeader_1x10_P2.54mm_Vertical | https://www.mouser.com/ProductDetail/3M-Electronic-Solutions-Division/929834-01-10?qs=VCIs6OJqWMnxxO0gLRAYjA==
J2 | 1 | MC_IO-lhs | Connector_PinHeader_2.54mm:PinHeader_1x09_P2.54mm_Vertical
J3 | 1 | MC_IO_PWR-rhs | Connector_PinHeader_2.54mm:PinHeader_1x09_P2.54mm_Vertical
J4 | 1 | MC_IO-bottom | Connector_PinHeader_2.54mm:PinHeader_1x05_P2.54mm_Vertical
J5 | 1 | 104031-0811 | Connector_Card:microSD_HC_Molex_104031-0811 | https://www.mouser.com/ProductDetail/Molex/104031-0811?qs=udsGRKD4nA3Tvy7wqky%2BuA==
R1,R2,R3,R4 | 4 | 10K | Resistor_SMD:R_0805_2012Metric_Pad1.20x1.40mm_HandSolder | https://www.mouser.com/ProductDetail/Panasonic/ERJ-P06F1002V?qs=Zyl8A9hlmJpSDn8Y2yUh3g==
U1 | 1 | TXU0304 | Package_SO:TSSOP-14_4.4x5mm_P0.65mm | https://www.mouser.com/ProductDetail/Texas-Instruments/TXU0304PWR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
U2 | 1 | LD39015M33R | Package_TO_SOT_SMD:SOT-23-5 | https://www.mouser.com/ProductDetail/STMicroelectronics/LD39015M33R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
| 1 | Waveshare RP2040-Zero | | https://www.amazon.com/RP2040-Zero-High-Performance-Microcontroller-Castellated-Applications/dp/B09KZPCNPL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

1

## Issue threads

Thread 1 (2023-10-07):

Question on a build

jfceklosky, 2023-10-07:
I am looking to build one of these.
I have the gerbers uploaded to jlcpcb, but I am looking for the BOMs
I see the bom directory, but I am not familiar with the .numbers files, which looks like an apple file.

Can you please export these into excel or something that I can use on linux?

jfceklosky, 2023-10-07:
I found an online tool to convert .numbers to .xls

jfceklosky, 2023-10-07:
Did you hand solder the SMT parts or did you have the pcb builder do this?

dpicken, 2023-10-07:
Hey

There are pdfs of the boms in the pdf/ directory.  The readme file for each board links to its pdf bom, e.g.

    https://github.com/dpicken/atari-hw ->
    https://github.com/dpicken/atari-hw/blob/main/doc/sbc.md ->
    https://github.com/dpicken/atari-hw/blob/main/doc/sbc-motherboard.md ->
    https://github.com/dpicken/atari-hw/blob/main/pdf/sbc-bom.pdf

dpicken, 2023-10-07:
I've hand soldered everything. The most difficult components are the voltage translators (TSSOP-14) and oscillator (in that order).  Everything else has at least 1.27mm pin spacing and aren't too tricky. I've built 4 boards now and can "easily" do the voltage translators but they were difficult the first couple of times.

If you decide to go the hand solder route, then you'll probably need at least the following: temperature controlled iron, flux, leaded solder, 7.5X magnification, fine tweezers and copper braid.   Probably worth ordering at least 5 boards and practicing on a couple of boards.

I found these channels helpful to get beyond "rank amateur" soldering:

- basic soldering: https://youtube.com/playlist?list=PL926EC0F1F93C1837&feature=shared
- https://youtube.com/@NorthridgeFix?feature=shared

Closed 2023-10-13.

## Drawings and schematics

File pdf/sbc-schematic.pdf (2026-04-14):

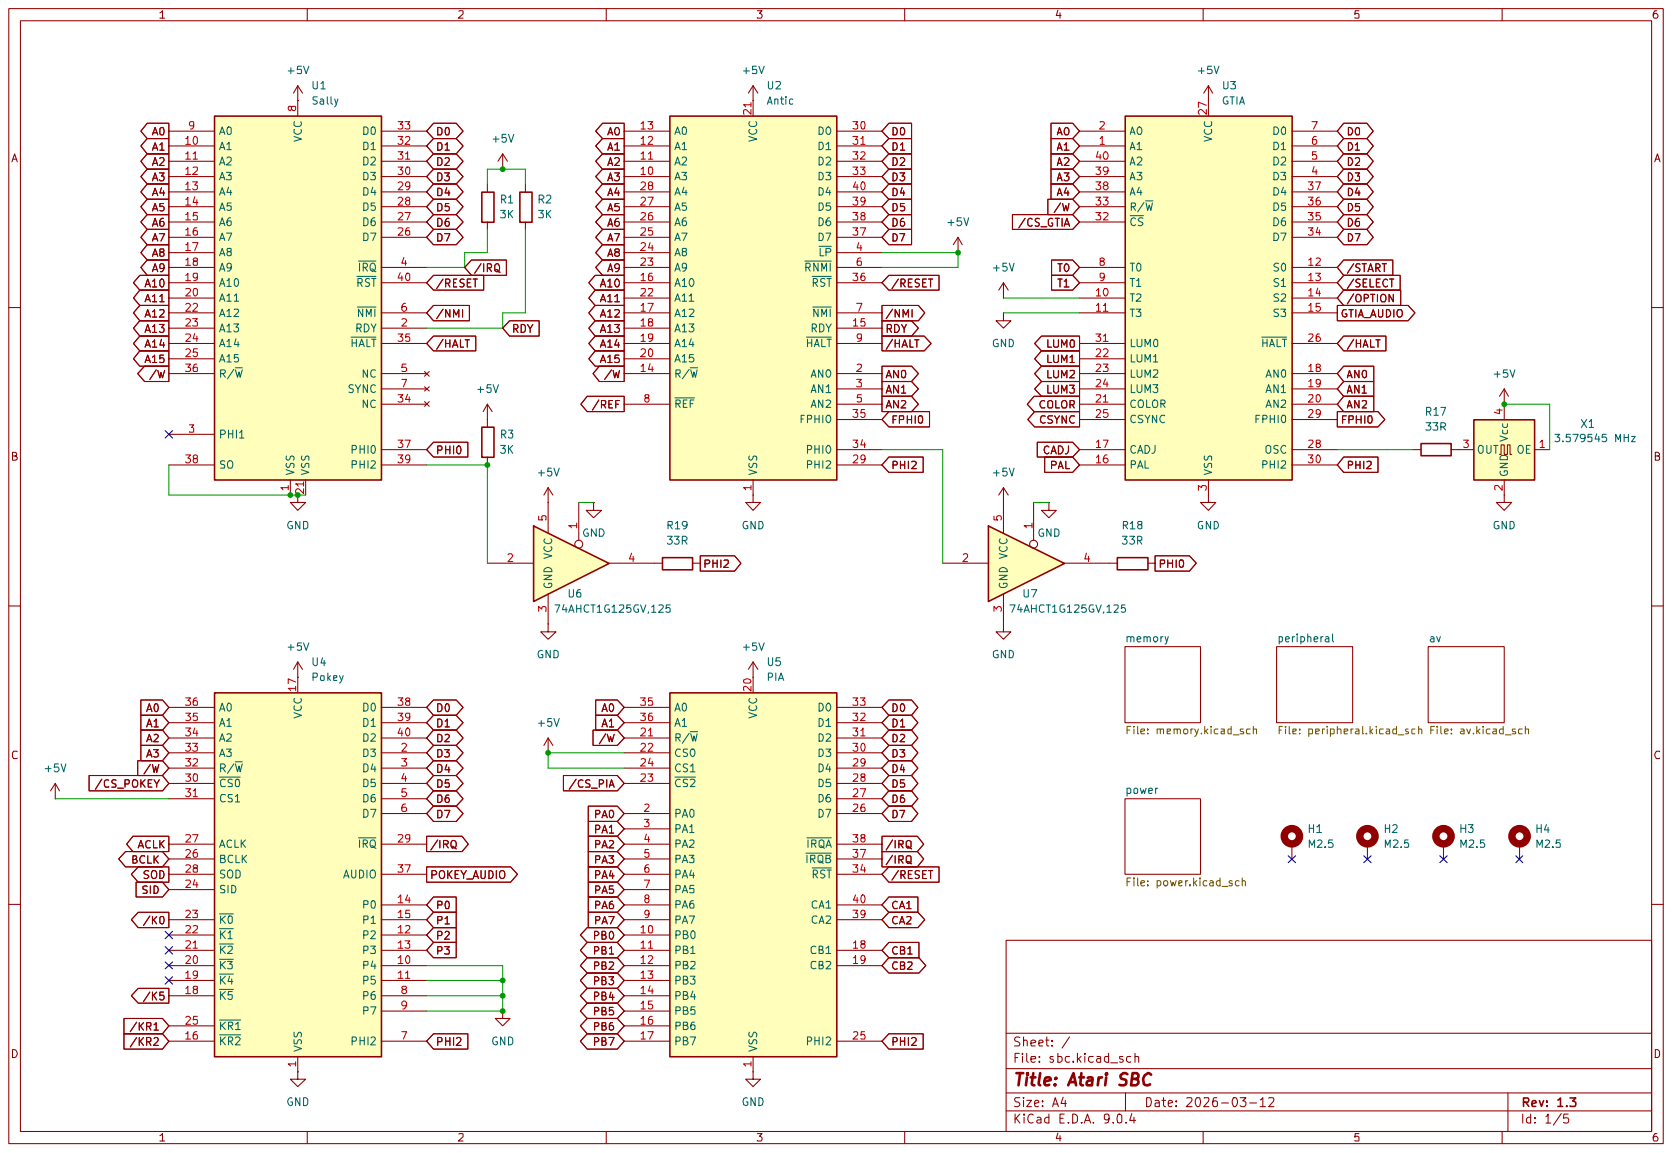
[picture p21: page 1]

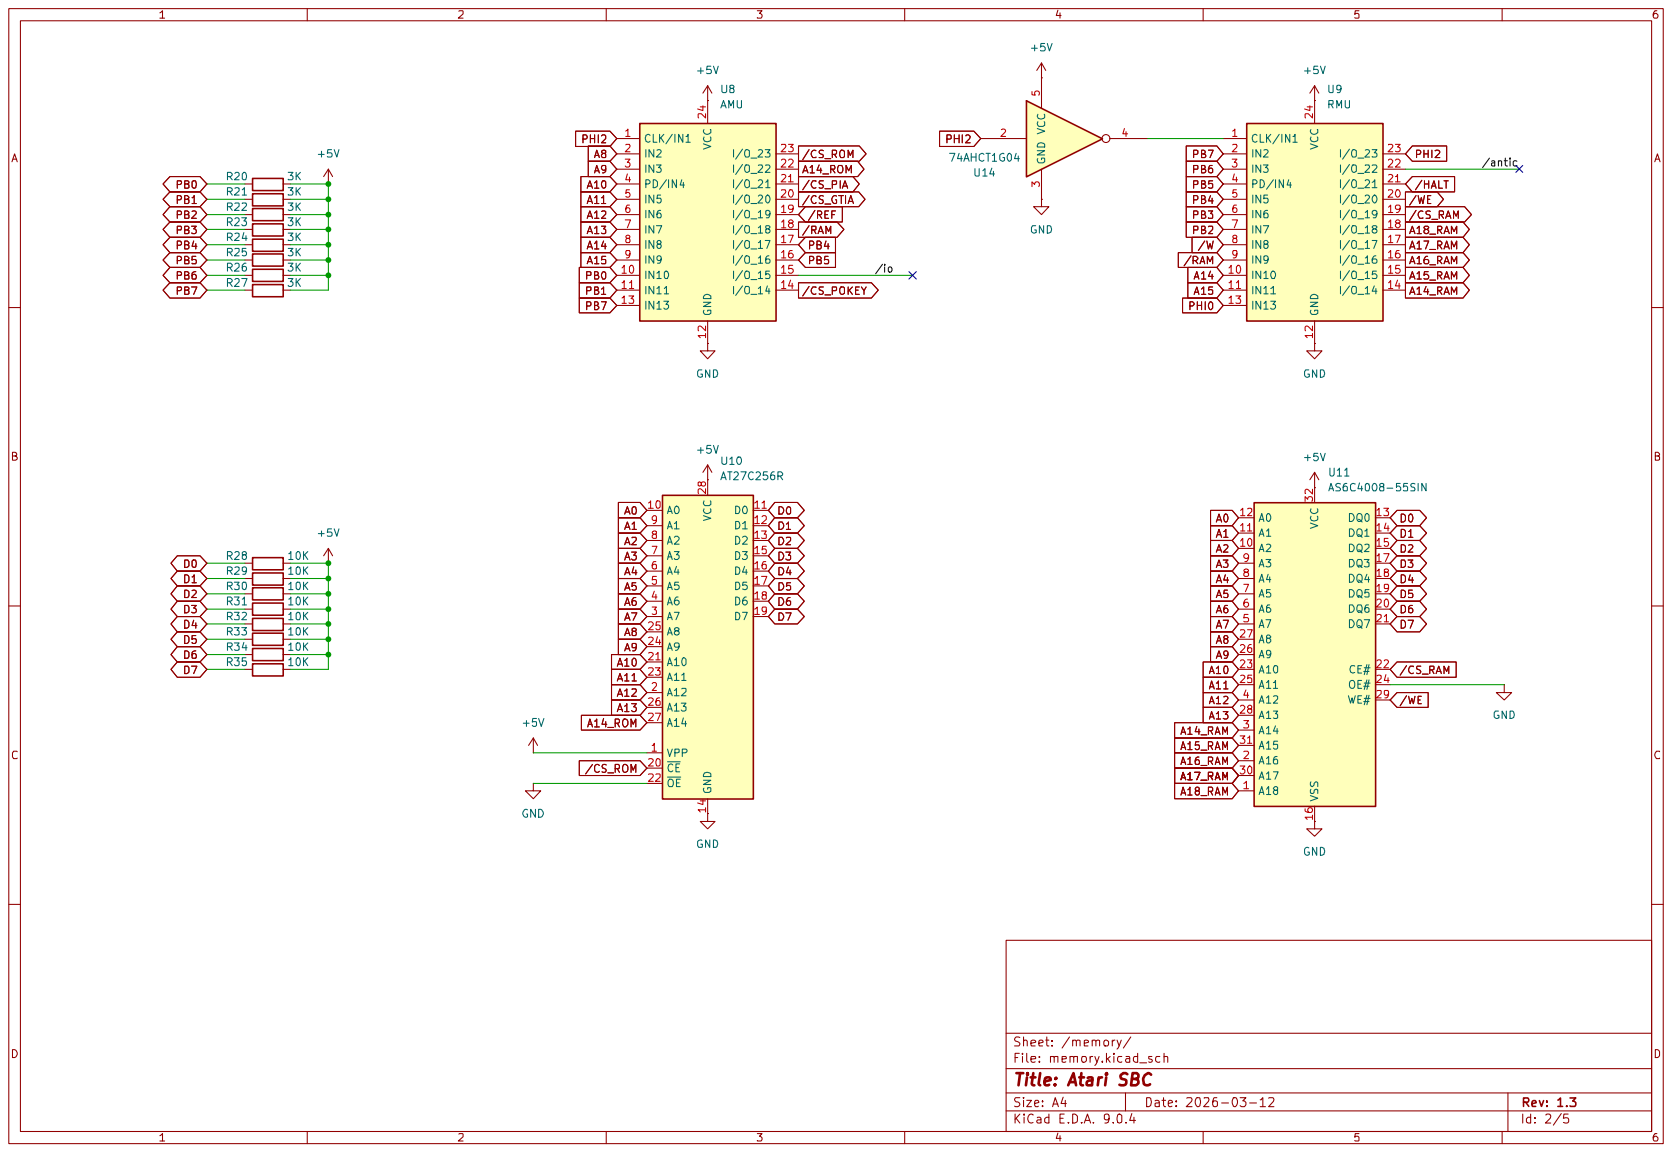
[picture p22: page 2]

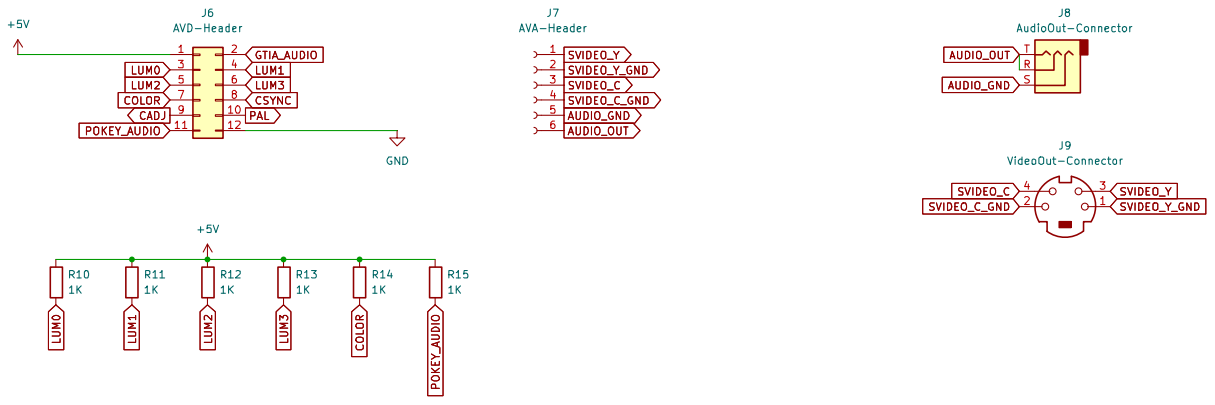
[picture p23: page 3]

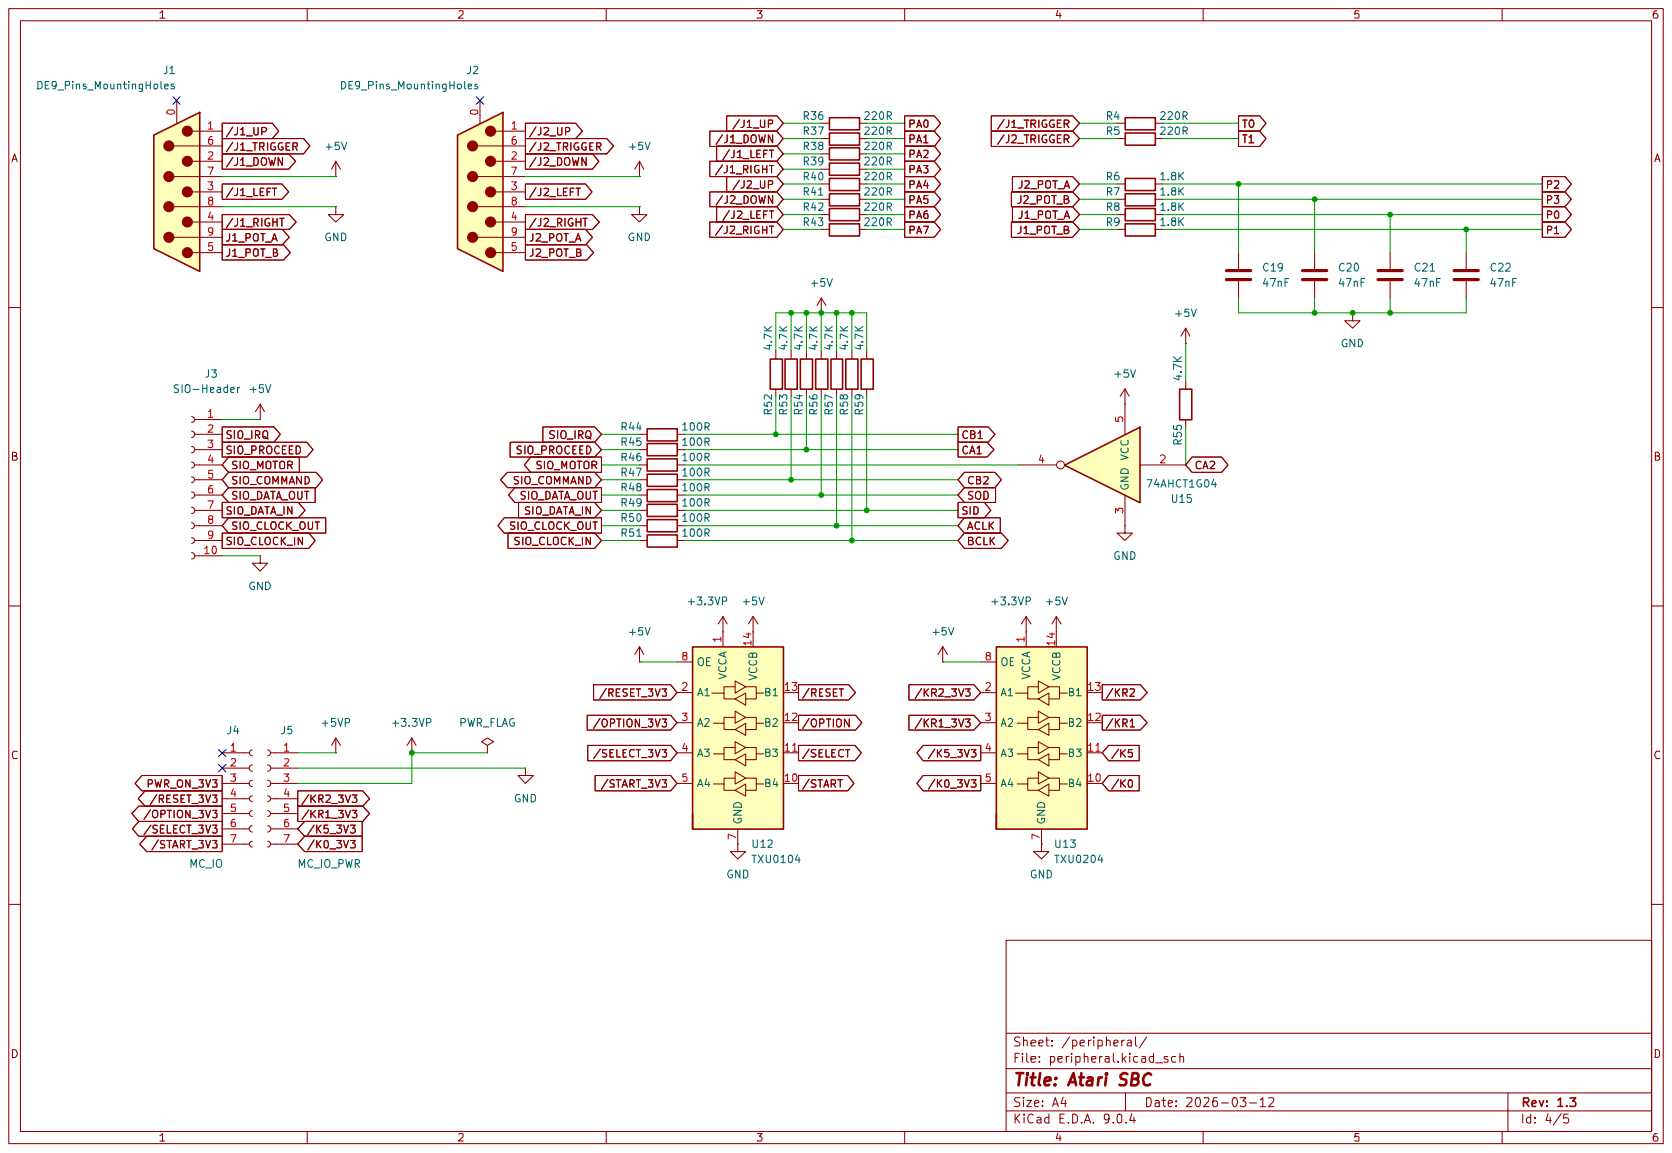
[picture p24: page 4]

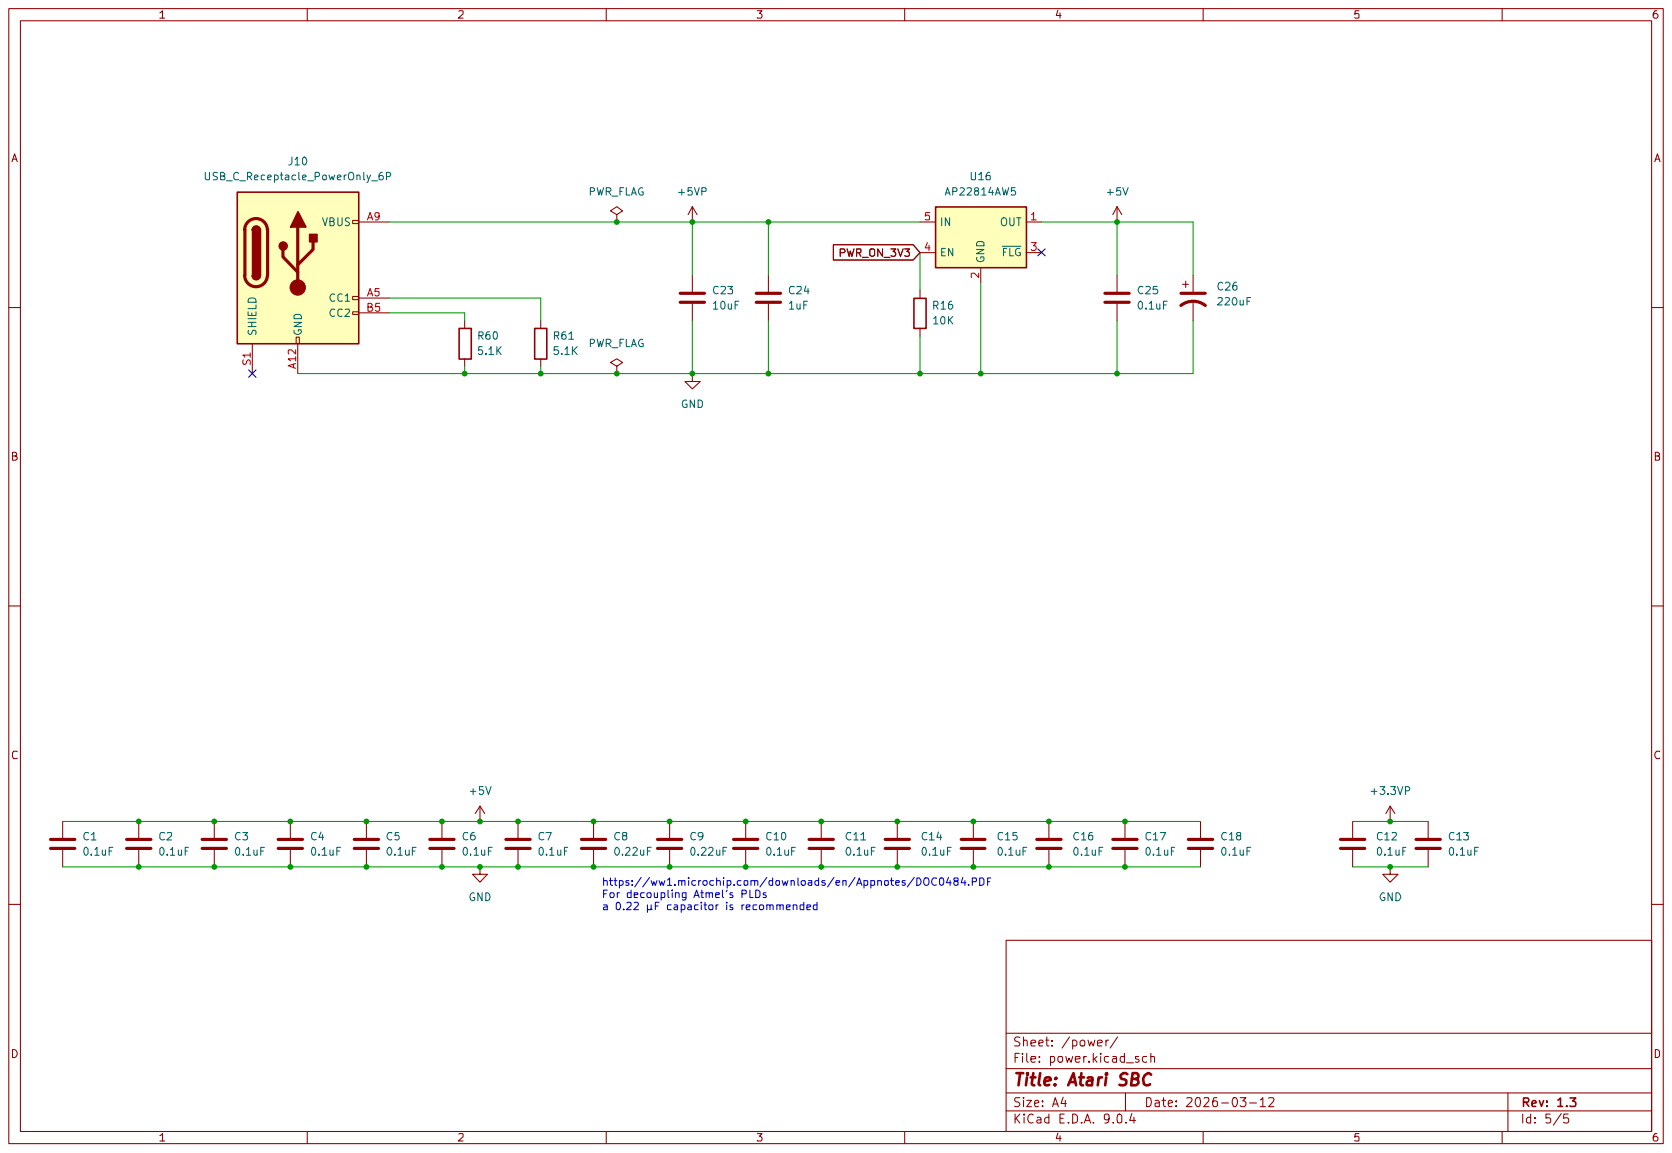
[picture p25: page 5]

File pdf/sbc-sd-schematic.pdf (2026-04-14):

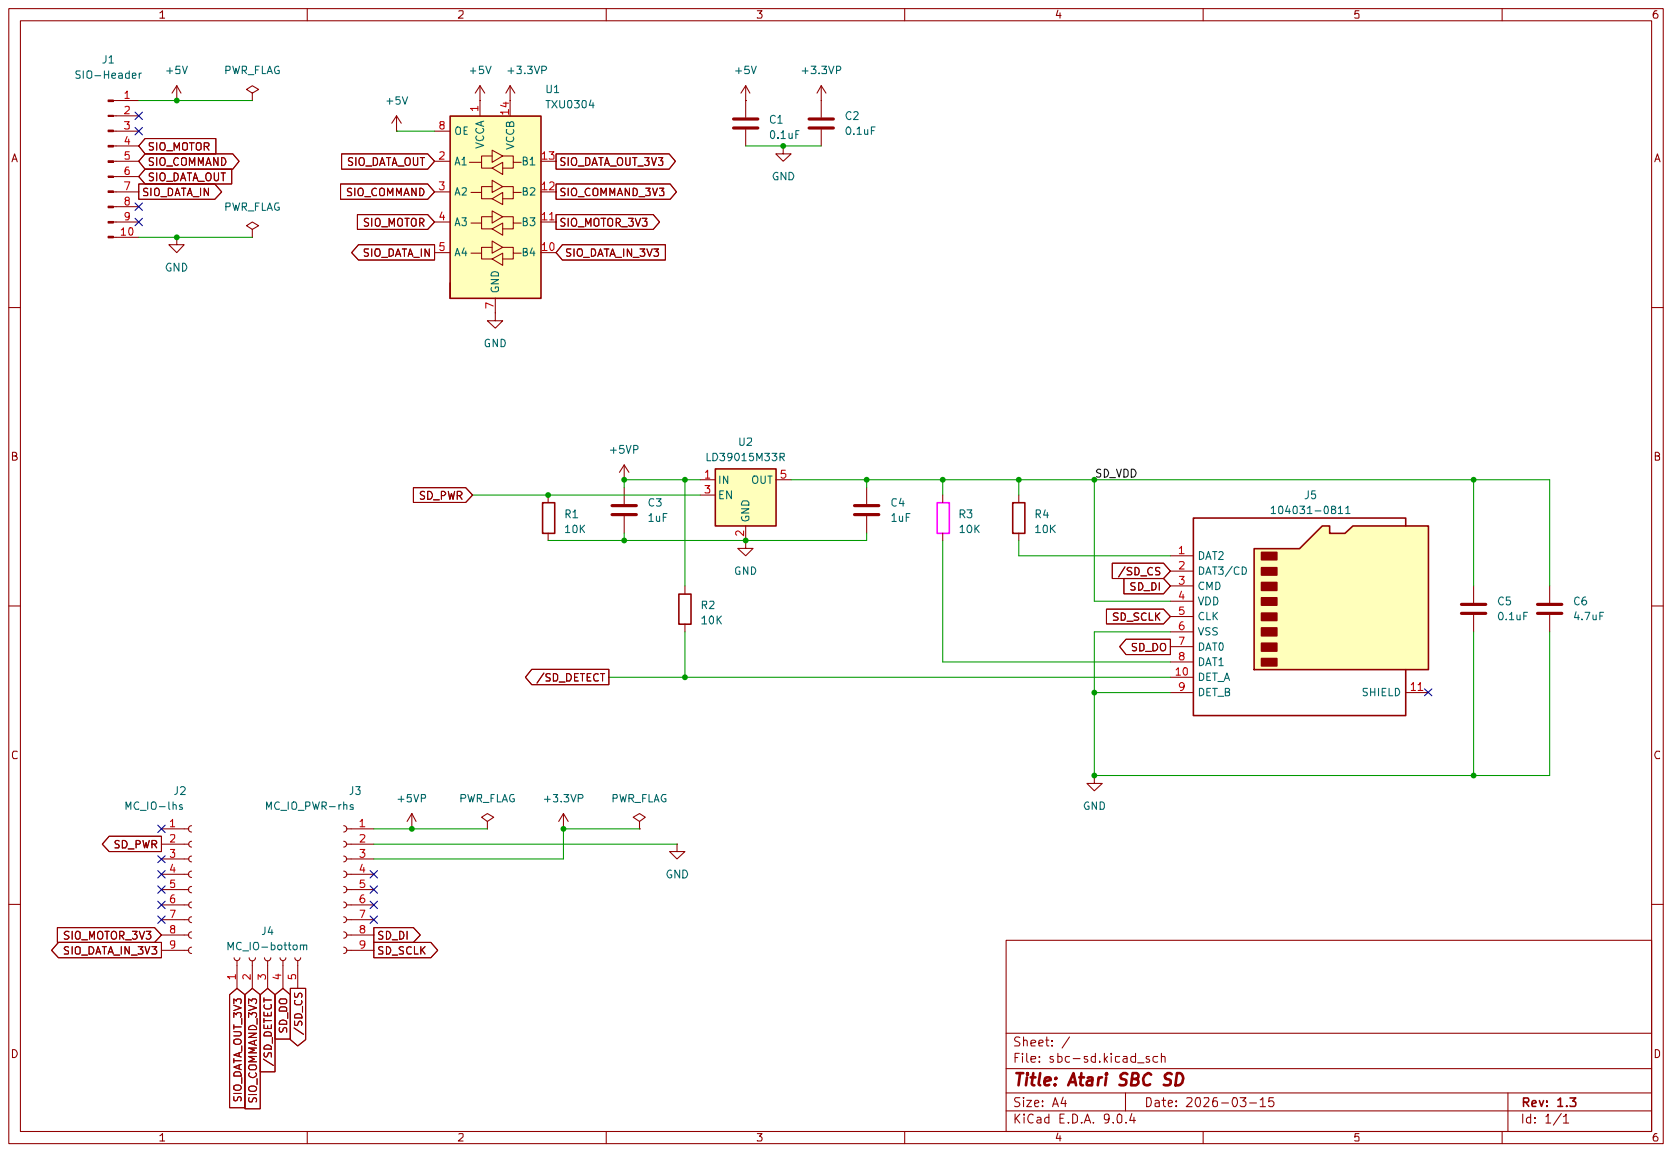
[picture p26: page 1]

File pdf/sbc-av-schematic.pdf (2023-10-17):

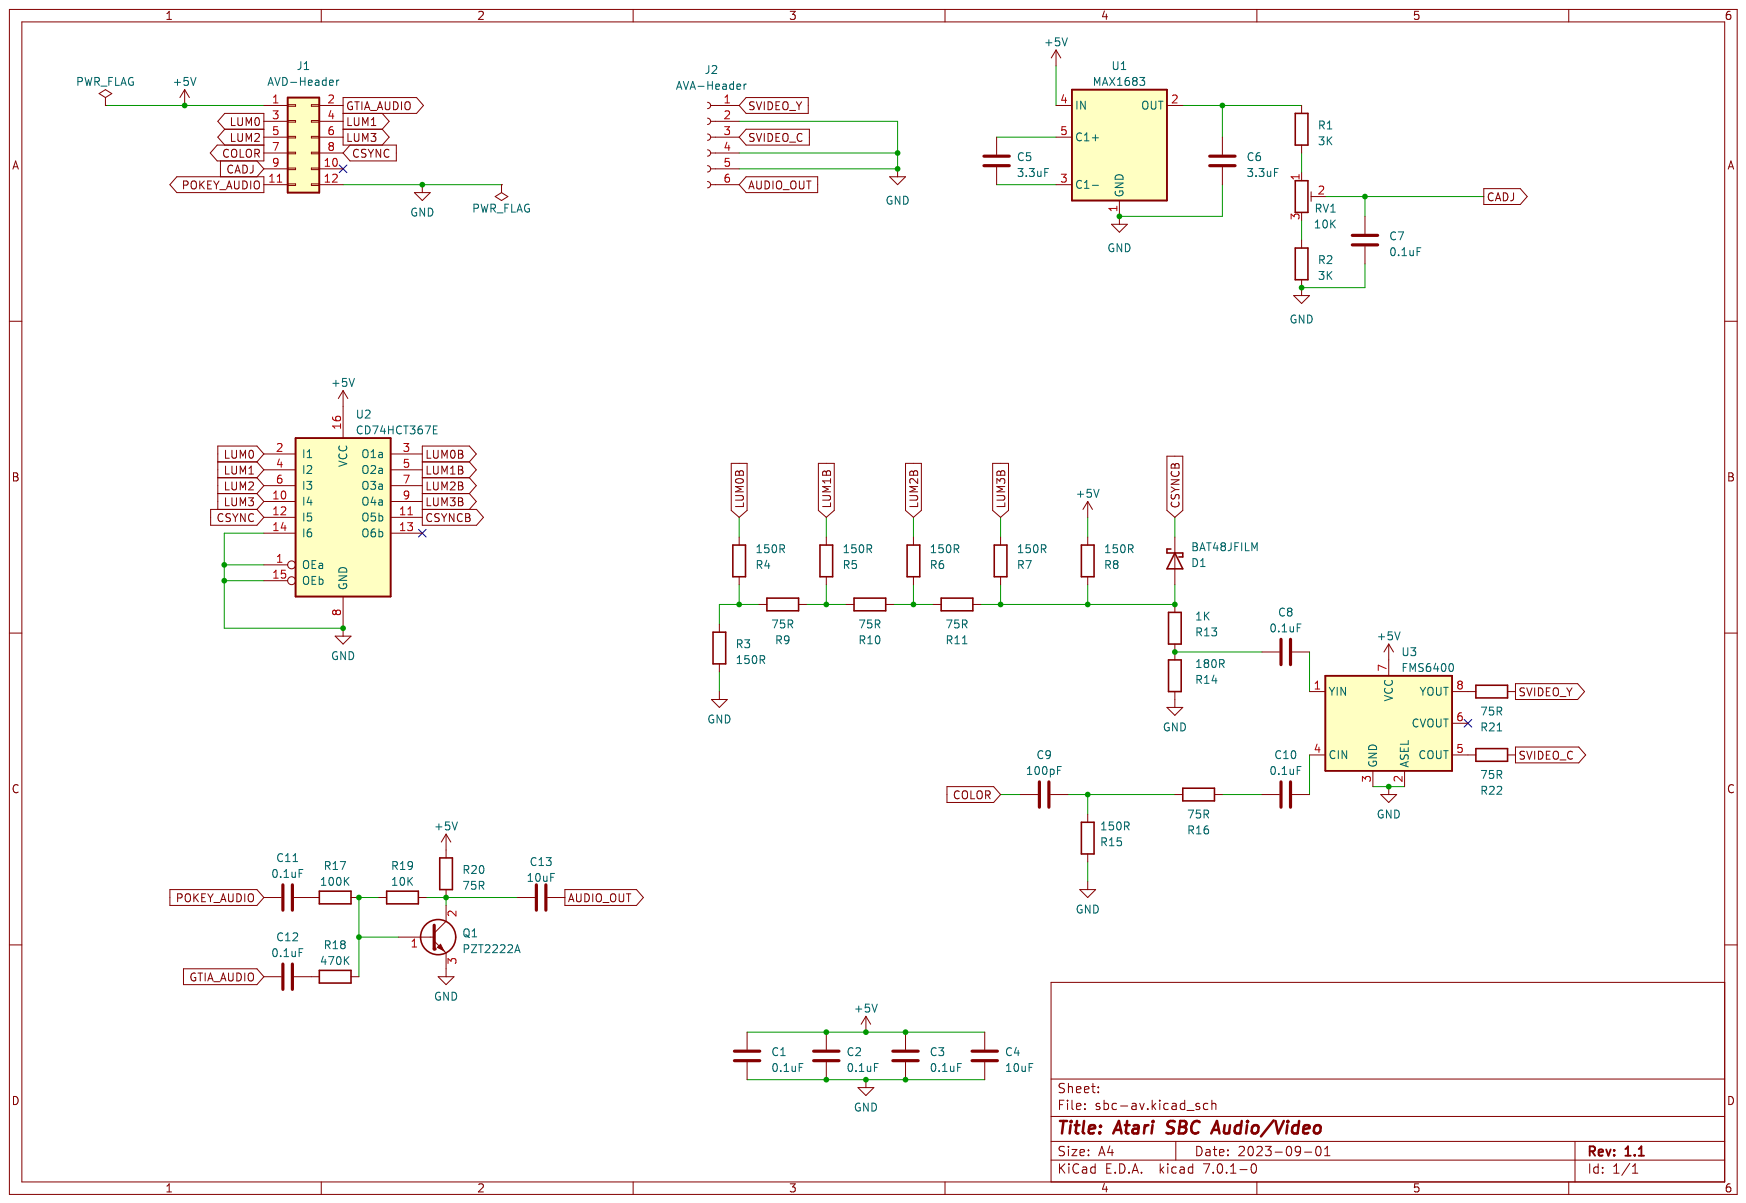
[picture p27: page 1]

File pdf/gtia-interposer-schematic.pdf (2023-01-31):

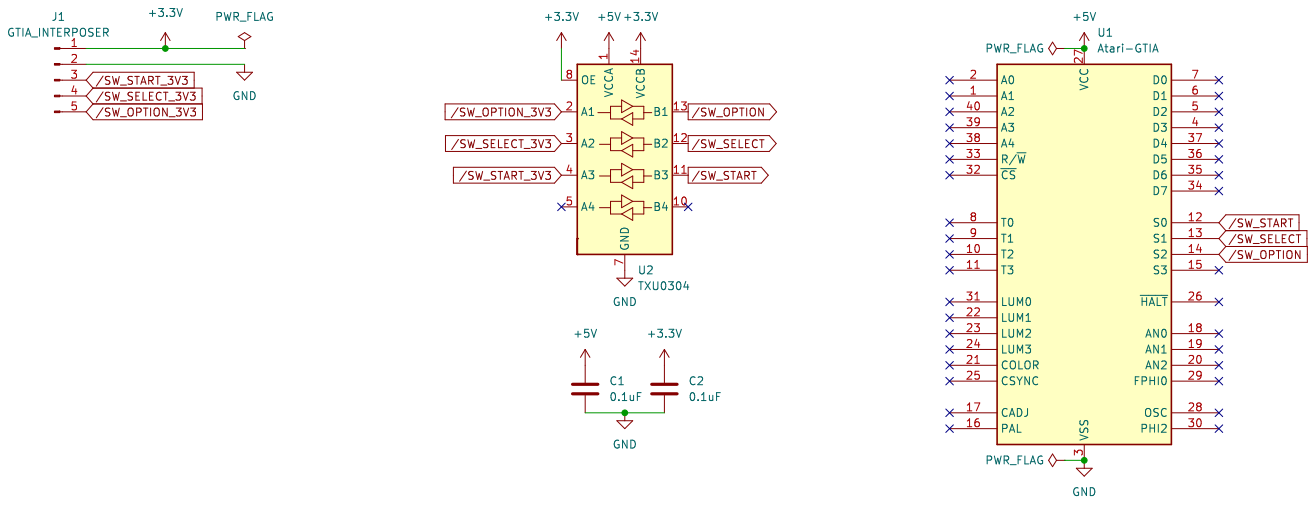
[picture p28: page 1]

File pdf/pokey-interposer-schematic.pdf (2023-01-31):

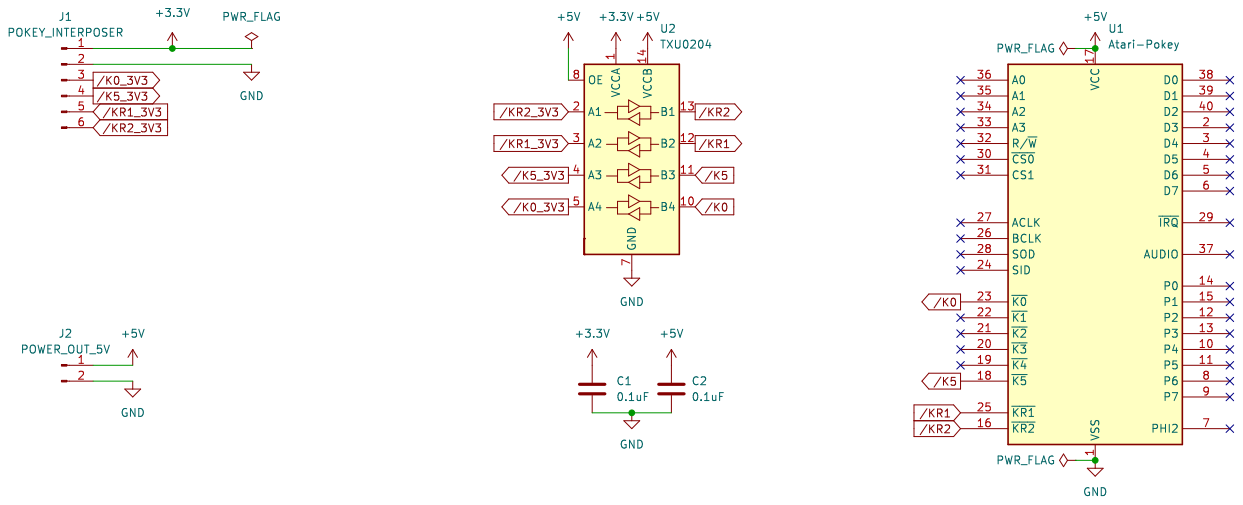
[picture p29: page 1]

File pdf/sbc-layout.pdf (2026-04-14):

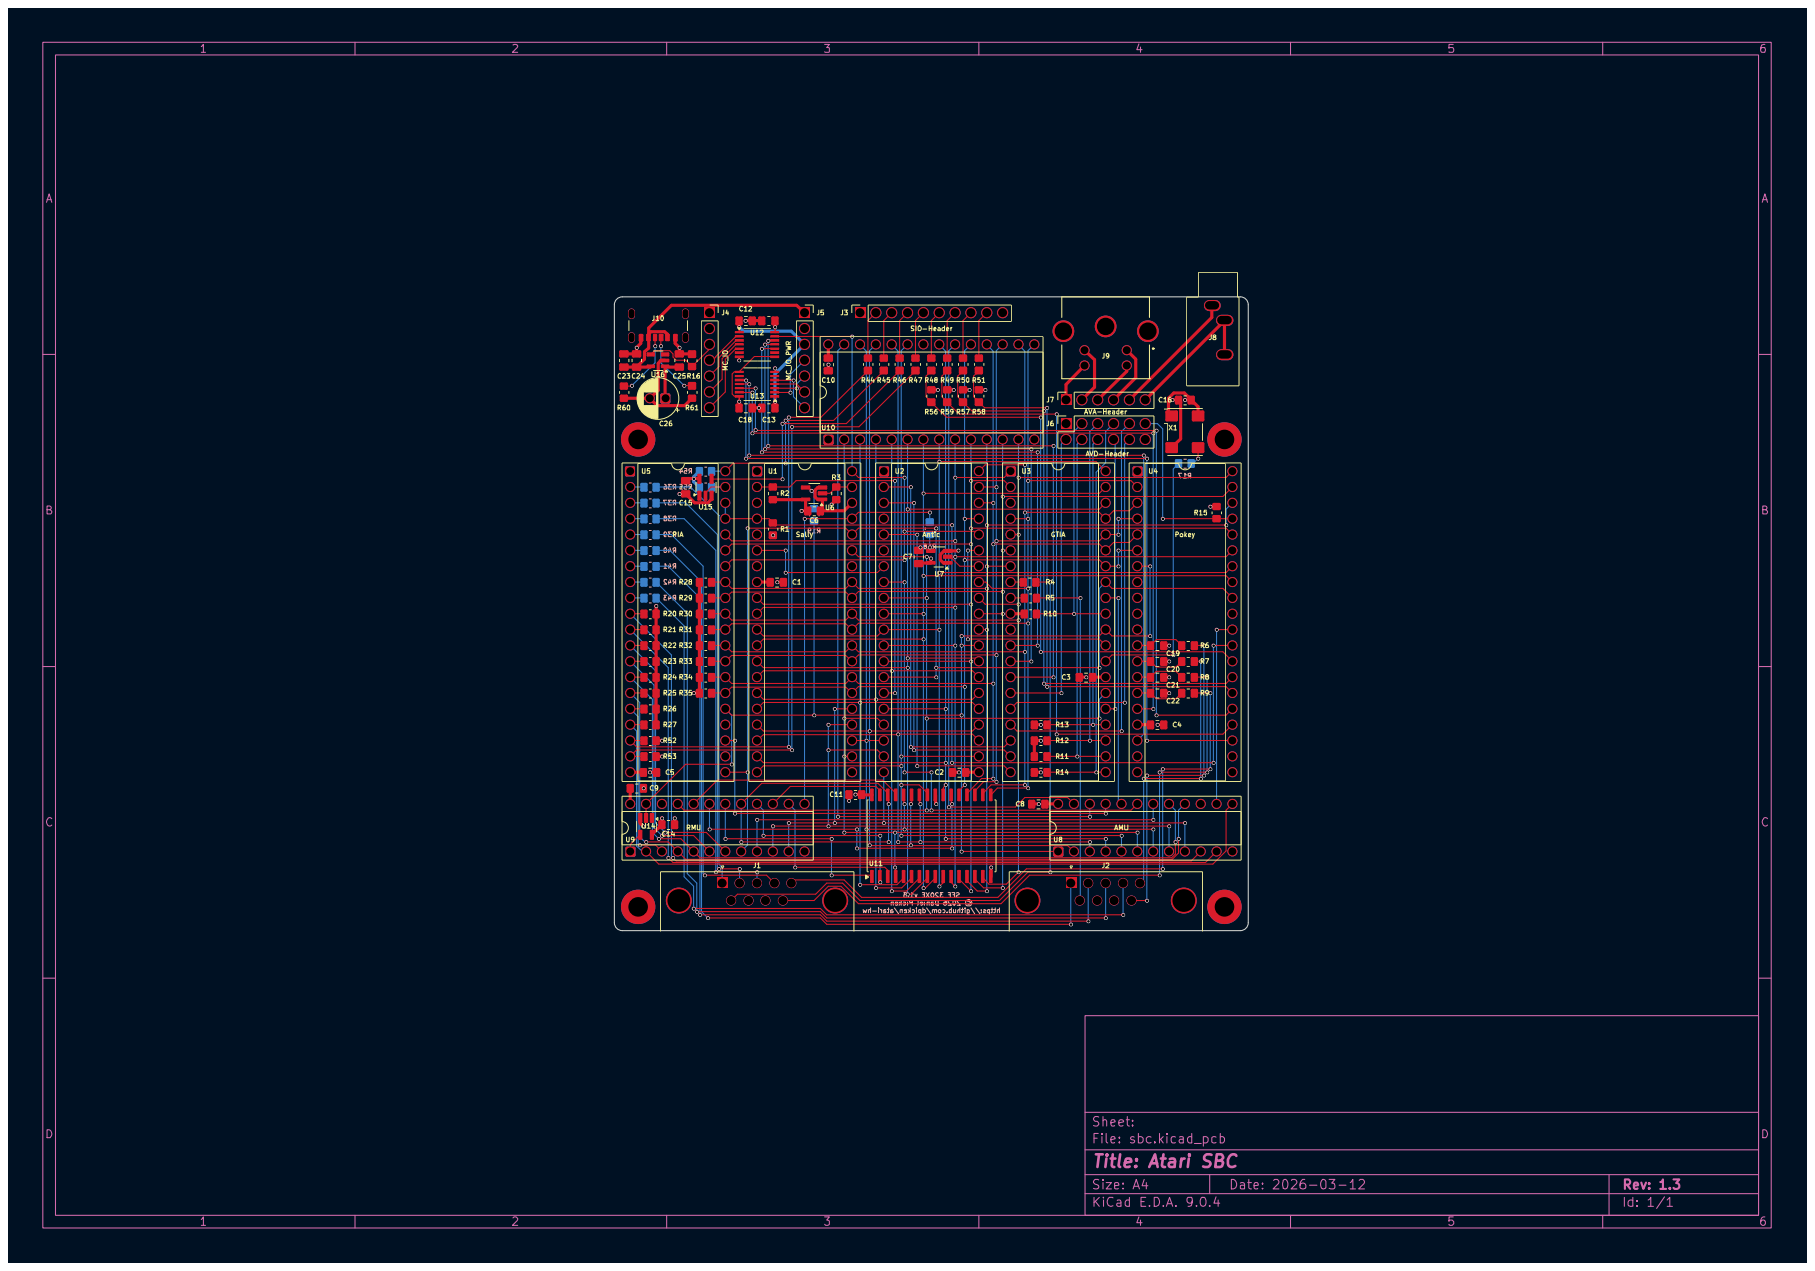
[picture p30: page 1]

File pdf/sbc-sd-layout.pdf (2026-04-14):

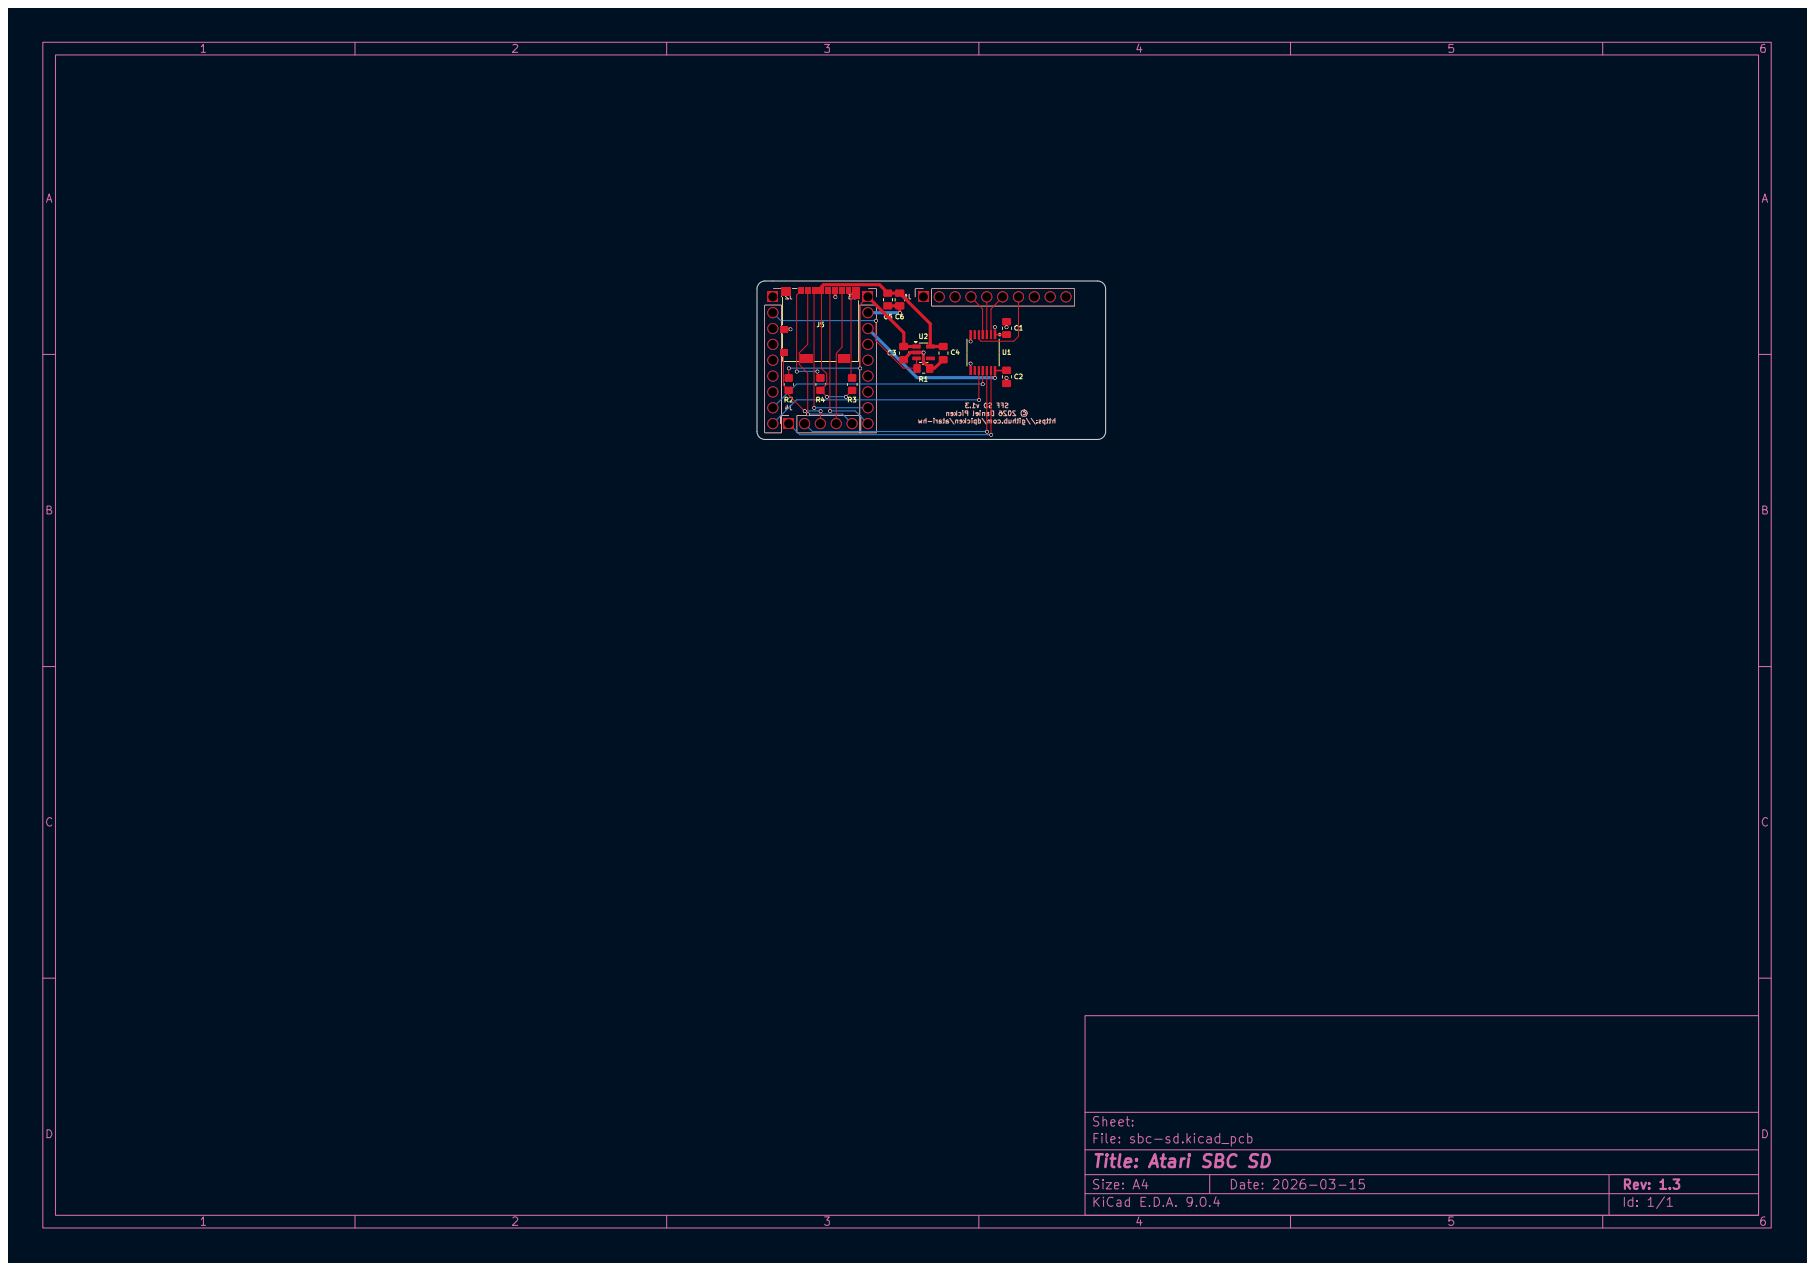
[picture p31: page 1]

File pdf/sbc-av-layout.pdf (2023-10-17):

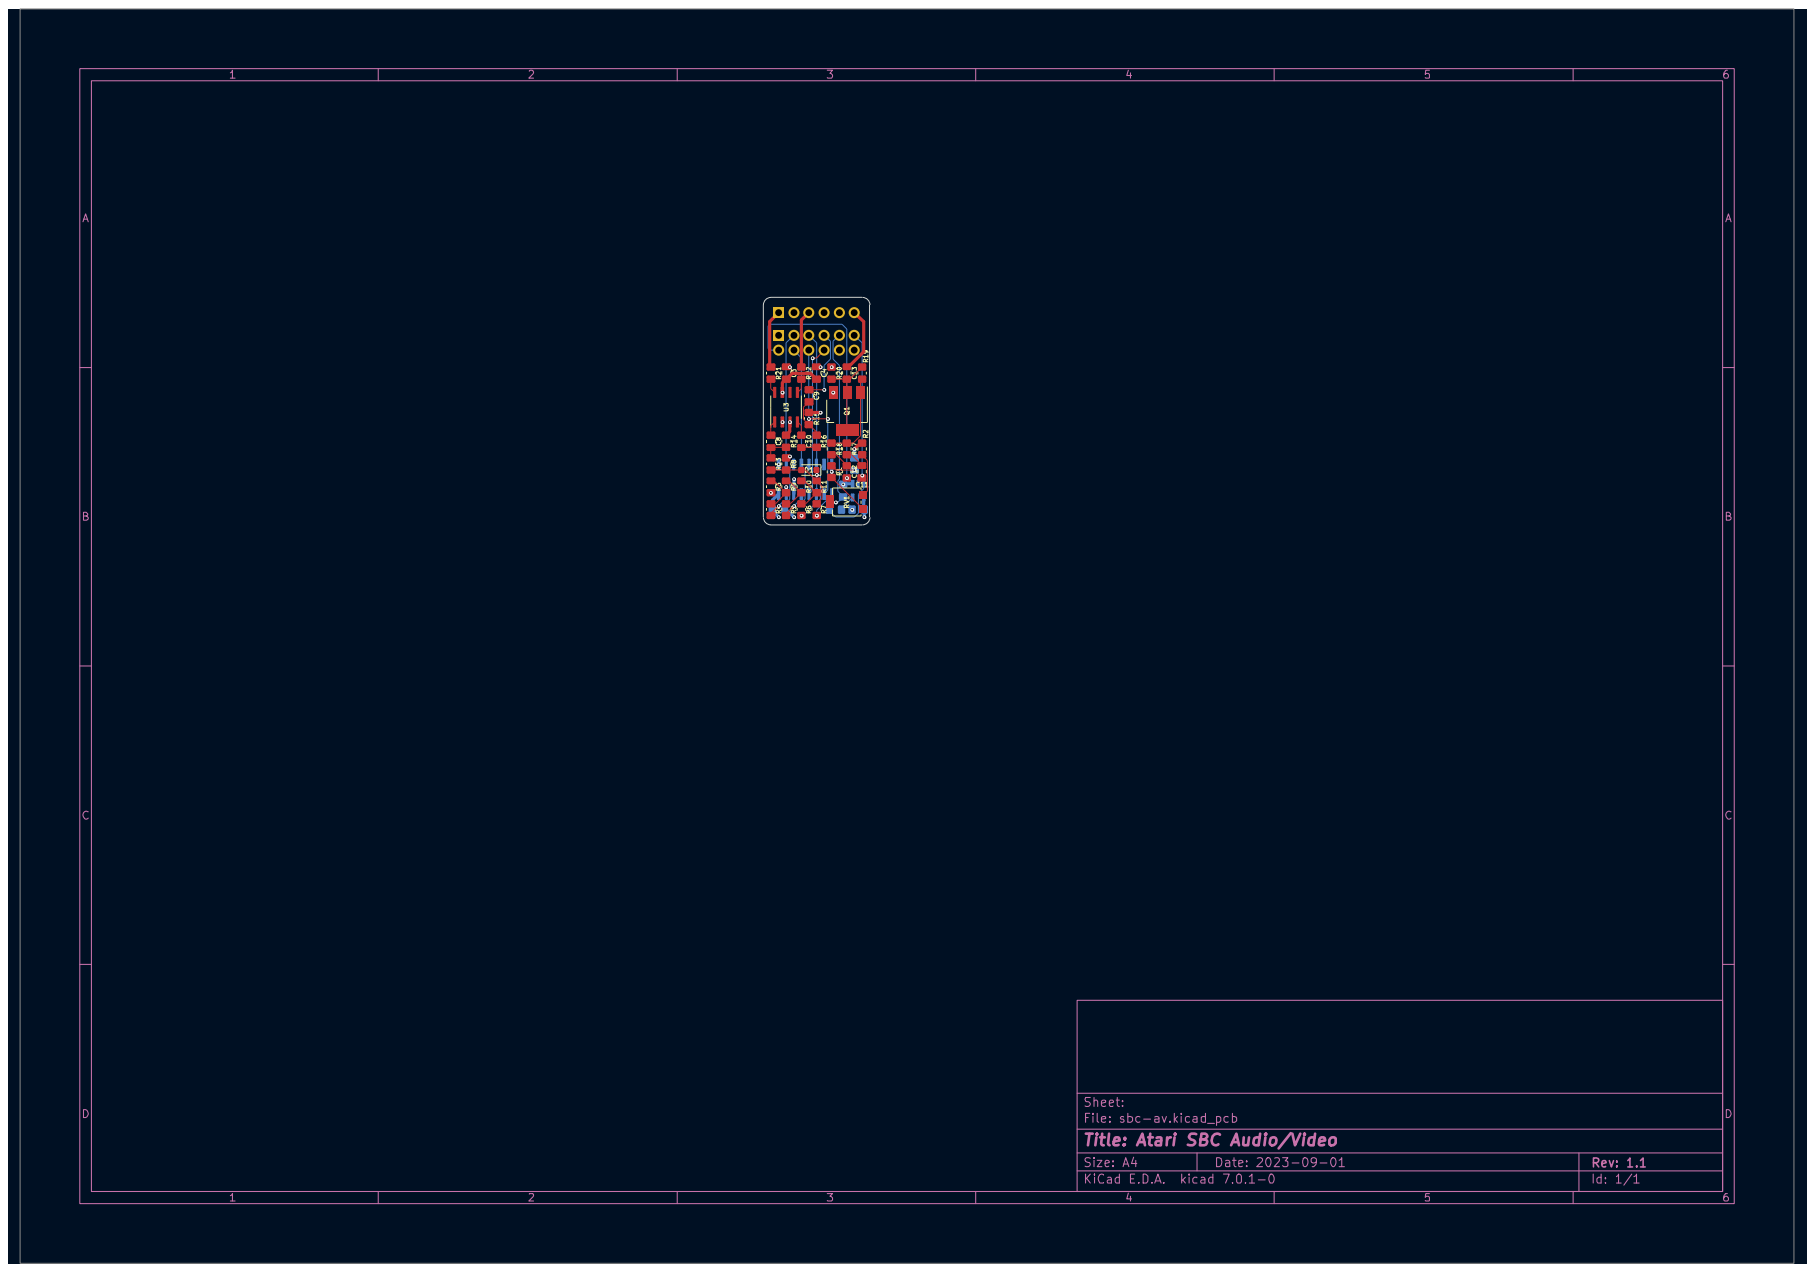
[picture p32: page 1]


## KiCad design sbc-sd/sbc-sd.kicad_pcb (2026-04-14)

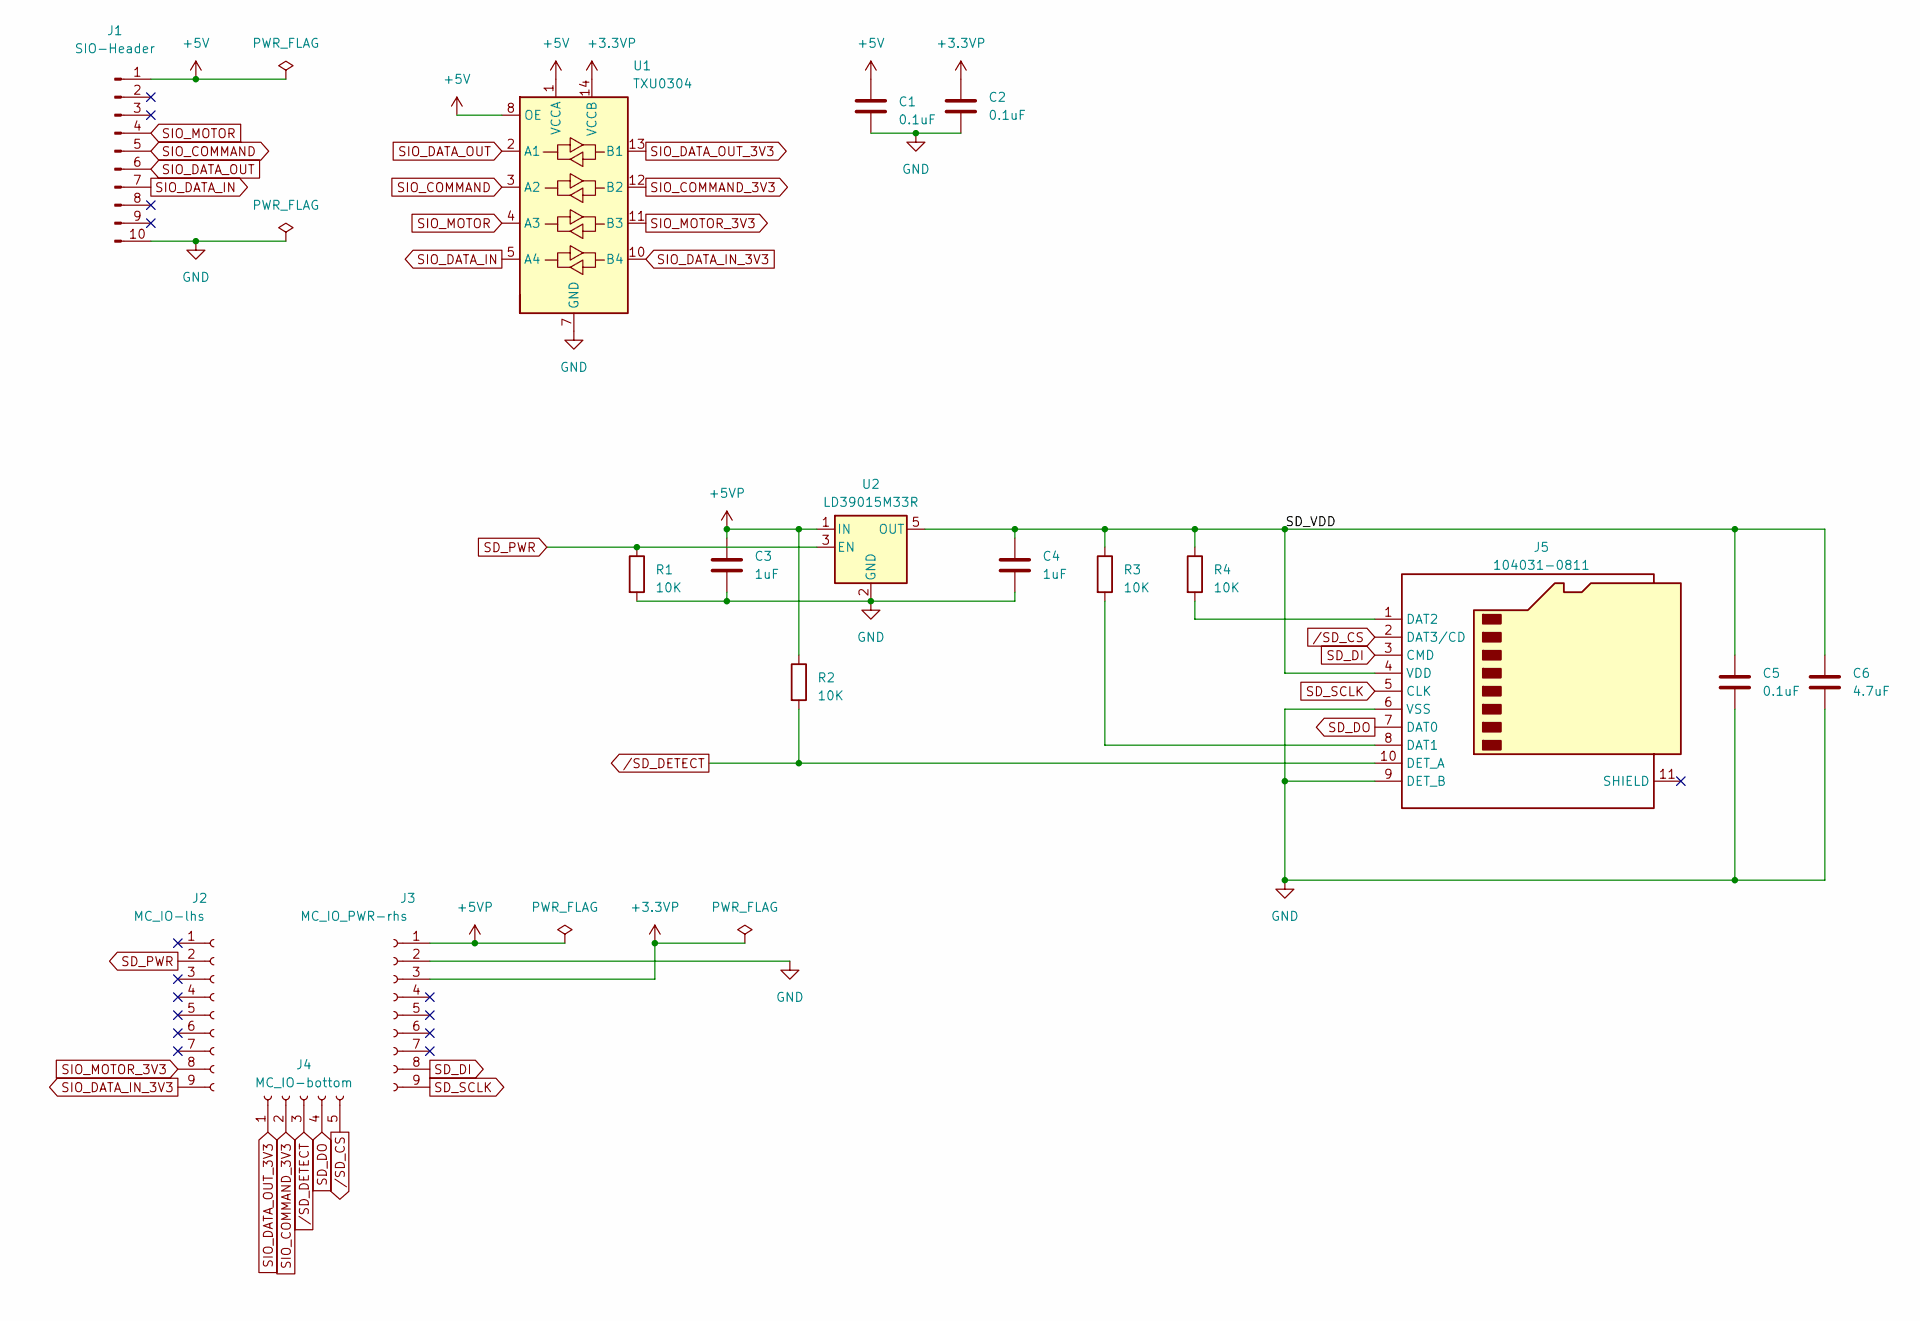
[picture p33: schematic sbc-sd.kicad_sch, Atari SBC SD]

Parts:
C1, C2, C5: 0.1uF; C_0805_2012Metric_Pad1.18x1.45mm_HandSolder
C3, C4: 1uF; C_0805_2012Metric_Pad1.18x1.45mm_HandSolder
C6: 4.7uF; C_0805_2012Metric_Pad1.18x1.45mm_HandSolder
J1: SIO-Header; PinHeader_1x10_P2.54mm_Vertical
J2: MC_IO-lhs; PinHeader_1x09_P2.54mm_Vertical
J3: MC_IO_PWR-rhs; PinHeader_1x09_P2.54mm_Vertical
J4: MC_IO-bottom; PinHeader_1x05_P2.54mm_Vertical
J5: 104031-0811; microSD_HC_Molex_104031-0811
R1, R2, R3, R4: 10K; R_0805_2012Metric_Pad1.20x1.40mm_HandSolder
U1: TXU0304; TSSOP-14_4.4x5mm_P0.65mm
U2: LD39015M33R; SOT-23-5

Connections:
+3.3VP: C2.1, J3.3, U1.14 (VCCB)
+5V: C1.1, J1.1, U1.1 (VCCA), U1.8 (OE)
+5VP: C3.1, J3.1, R2.1, U2.1 (IN)
/SD_VDD: C4.1, C5.1, C6.1, J5.4 (VDD), R3.1, R4.1, U2.5 (OUT)
GND: C1.2, C2.2, C3.2, C4.2, C5.2, C6.2, J1.10, J3.2, J5.6 (VSS), J5.9 (DET_B), R1.2, U1.7 (GND), U2.2 (GND)
unnamed: J5.8 (DAT1), R3.2
unnamed: J5.1 (DAT2), R4.2
SD_DI: J3.8, J5.3 (CMD)
SD_DO: J4.4, J5.7 (DAT0)
SD_PWR: J2.2, R1.1, U2.3 (EN)
SD_SCLK: J3.9, J5.5 (CLK)
SIO_COMMAND: J1.5, U1.3 (A2)
SIO_COMMAND_3V3: J4.2, U1.12 (B2)
SIO_DATA_IN: J1.7, U1.5 (A4)
SIO_DATA_IN_3V3: J2.9, U1.10 (B4)
SIO_DATA_OUT: J1.6, U1.2 (A1)
SIO_DATA_OUT_3V3: J4.1, U1.13 (B1)
SIO_MOTOR: J1.4, U1.4 (A3)
SIO_MOTOR_3V3: J2.8, U1.11 (B3)
/SD_CS: J4.5, J5.2 (DAT3/CD)
/SD_DETECT: J4.3, J5.10 (DET_A), R2.2

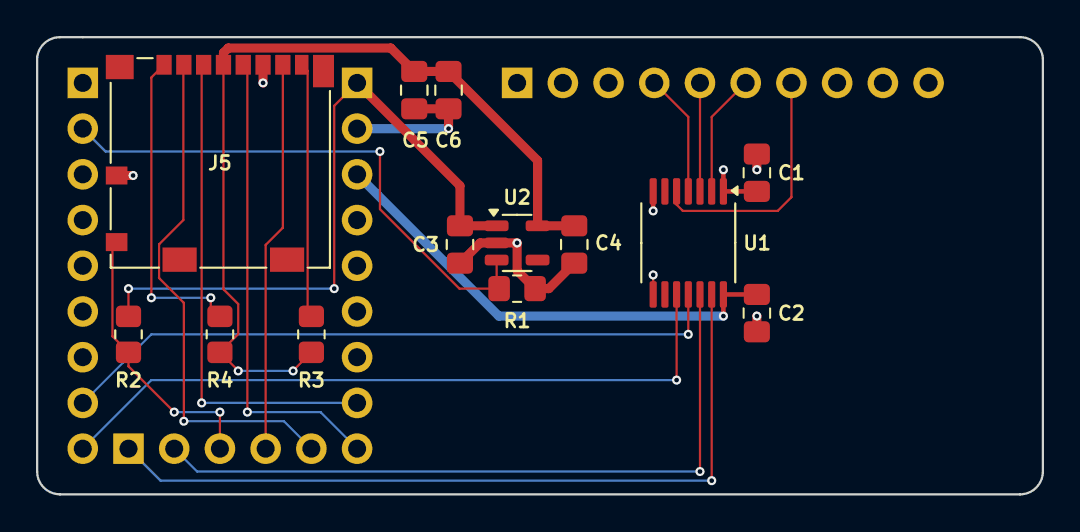
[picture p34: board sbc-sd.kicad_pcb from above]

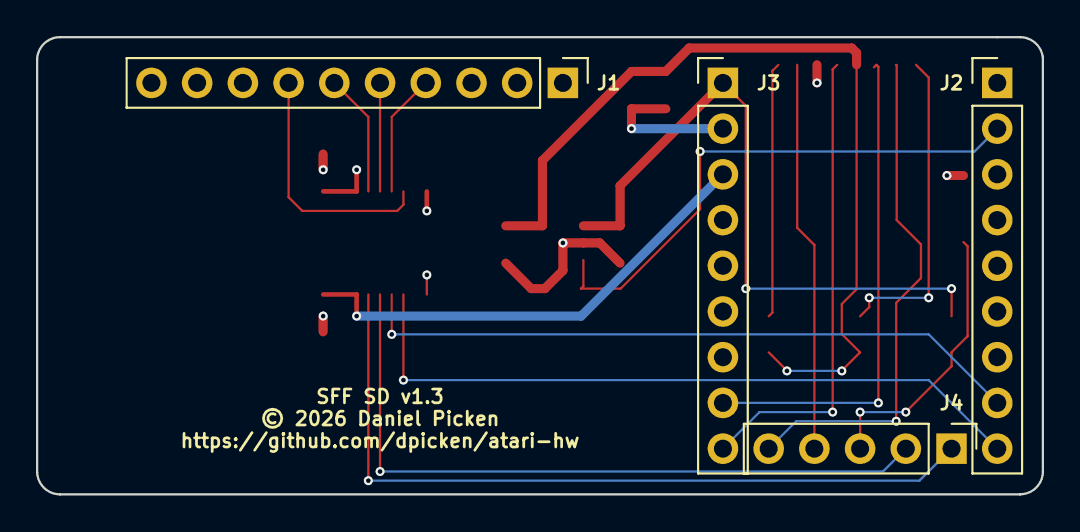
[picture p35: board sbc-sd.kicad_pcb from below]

Board: 4 copper layers, 55.9 x 25.4 mm, 17 parts (4 on the bottom side), 21 nets.

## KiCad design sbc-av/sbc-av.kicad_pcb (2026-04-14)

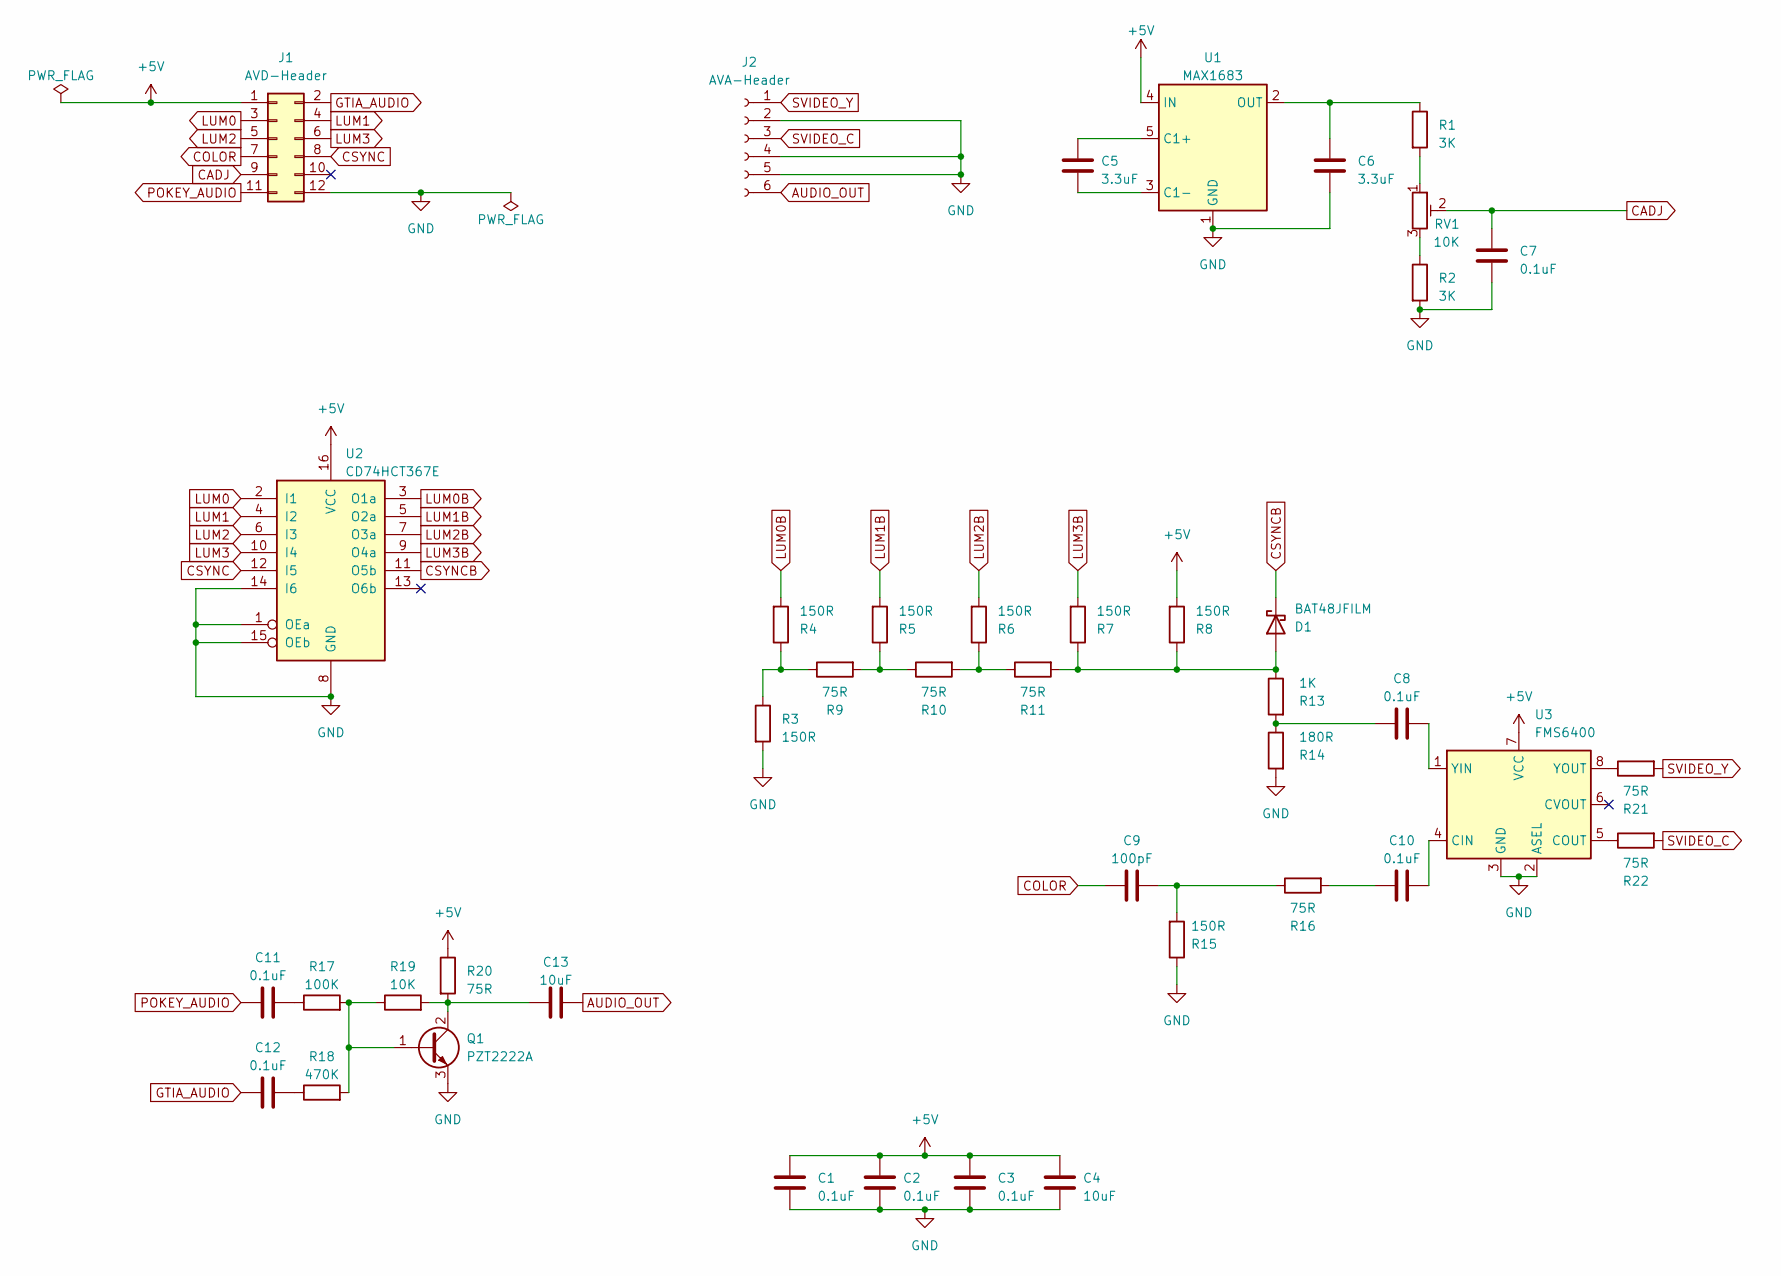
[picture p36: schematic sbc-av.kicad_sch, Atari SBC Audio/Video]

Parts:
C1, C2, C3, C7, C8, C10, C11, C12: 0.1uF; C_0805_2012Metric_Pad1.18x1.45mm_HandSolder
C4, C13: 10uF; C_0805_2012Metric_Pad1.18x1.45mm_HandSolder
C5, C6: 3.3uF; C_0805_2012Metric_Pad1.18x1.45mm_HandSolder
C9: 100pF; C_0805_2012Metric_Pad1.18x1.45mm_HandSolder
D1: BAT48JFILM; D_SOD-323_HandSoldering
J1: AVD-Header; PinHeader_2x06_P2.54mm_Vertical
J2: AVA-Header; PinHeader_1x06_P2.54mm_Vertical
Q1: PZT2222A; SOT-223-3_TabPin2
R1, R2: 3K; R_0805_2012Metric_Pad1.20x1.40mm_HandSolder
R3, R4, R5, R6, R7, R8, R15: 150R; R_0805_2012Metric_Pad1.20x1.40mm_HandSolder
R9, R10, R11, R16, R20, R21, R22: 75R; R_0805_2012Metric_Pad1.20x1.40mm_HandSolder
R13: 1K; R_0805_2012Metric_Pad1.20x1.40mm_HandSolder
R14: 180R; R_0805_2012Metric_Pad1.20x1.40mm_HandSolder
R17: 100K; R_0805_2012Metric_Pad1.20x1.40mm_HandSolder
R18: 470K; R_0805_2012Metric_Pad1.20x1.40mm_HandSolder
R19: 10K; R_0805_2012Metric_Pad1.20x1.40mm_HandSolder
RV1: 10K; Potentiometer_Bourns_3314G_Vertical
U1: MAX1683; SOT-23-5
U2: CD74HCT367E; SOIC-16_3.9x9.9mm_P1.27mm
U3: FMS6400; SOIC-8_3.9x4.9mm_P1.27mm

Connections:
+5V: C1.1, C2.1, C3.1, C4.1, J1.1, R8.2, R20.1, U1.4 (IN), U2.16 (VCC), U3.7 (VCC)
AUDIO_OUT: C13.2, J2.6
CADJ: C7.1, J1.9, RV1.2
COLOR: C9.1, J1.7
CSYNC: J1.8, U2.12 (I5)
CSYNCB: D1.1 (K), U2.11 (O5b)
GND: C1.2, C2.2, C3.2, C4.2, C6.2, C7.2, J1.12, J2.2, J2.4, J2.5, Q1.3 (E), R2.2, R3.2, R14.2, R15.1, U1.1 (GND), U2.1 (OEa), U2.8 (GND), U2.14 (I6), U2.15 (OEb), U3.2 (ASEL), U3.3 (GND)
GTIA_AUDIO: C12.1, J1.2
LUM0: J1.3, U2.2 (I1)
LUM0B: R4.2, U2.3 (O1a)
LUM1: J1.4, U2.4 (I2)
LUM1B: R5.2, U2.5 (O2a)
LUM2: J1.5, U2.6 (I3)
LUM2B: R6.2, U2.7 (O3a)
LUM3: J1.6, U2.10 (I4)
LUM3B: R7.2, U2.9 (O4a)
unnamed: C8.1, R13.2, R14.1
unnamed: C9.2, R15.2, R16.1
unnamed: C10.1, R16.2
unnamed: C11.2, R17.1
unnamed: C12.2, R18.1
unnamed: D1.2 (A), R7.1, R8.1, R11.2, R13.1
unnamed: Q1.1 (B), R17.2, R18.2, R19.1
unnamed: C13.1, Q1.2 (C), R19.2, R20.2
unnamed: R1.2, RV1.1
unnamed: R2.1, RV1.3
unnamed: R3.1, R4.1, R9.1
unnamed: R5.1, R9.2, R10.1
unnamed: R6.1, R10.2, R11.1
unnamed: C5.1, U1.5 (C1+)
unnamed: C5.2, U1.3 (C1-)
unnamed: C6.1, R1.1, U1.2 (OUT)
unnamed: C10.2, U3.4 (CIN)
unnamed: R22.1, U3.5 (COUT)
unnamed: C8.2, U3.1 (YIN)
unnamed: R21.1, U3.8 (YOUT)
POKEY_AUDIO: C11.1, J1.11
SVIDEO_C: J2.3, R22.2
SVIDEO_Y: J2.1, R21.2

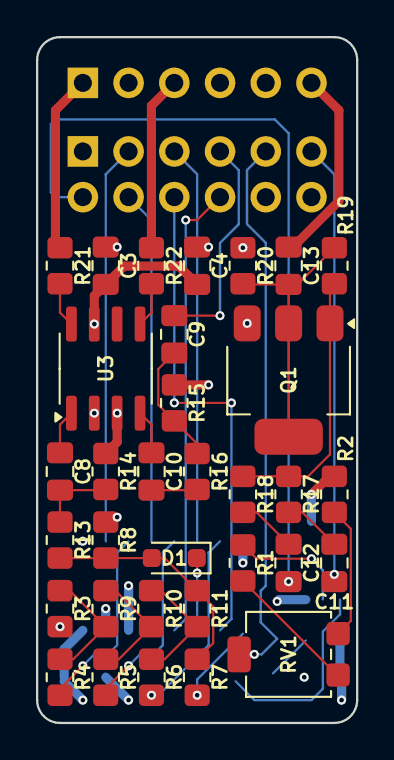
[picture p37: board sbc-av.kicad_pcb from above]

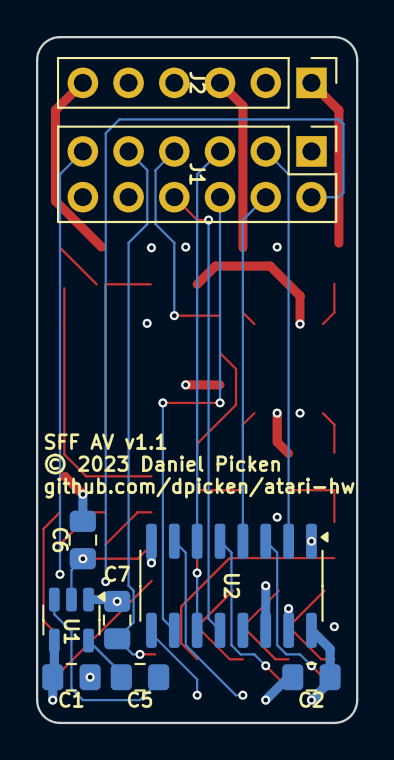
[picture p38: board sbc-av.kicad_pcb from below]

Board: 4 copper layers, 17.8 x 38.1 mm, 42 parts (9 on the bottom side), 39 nets.

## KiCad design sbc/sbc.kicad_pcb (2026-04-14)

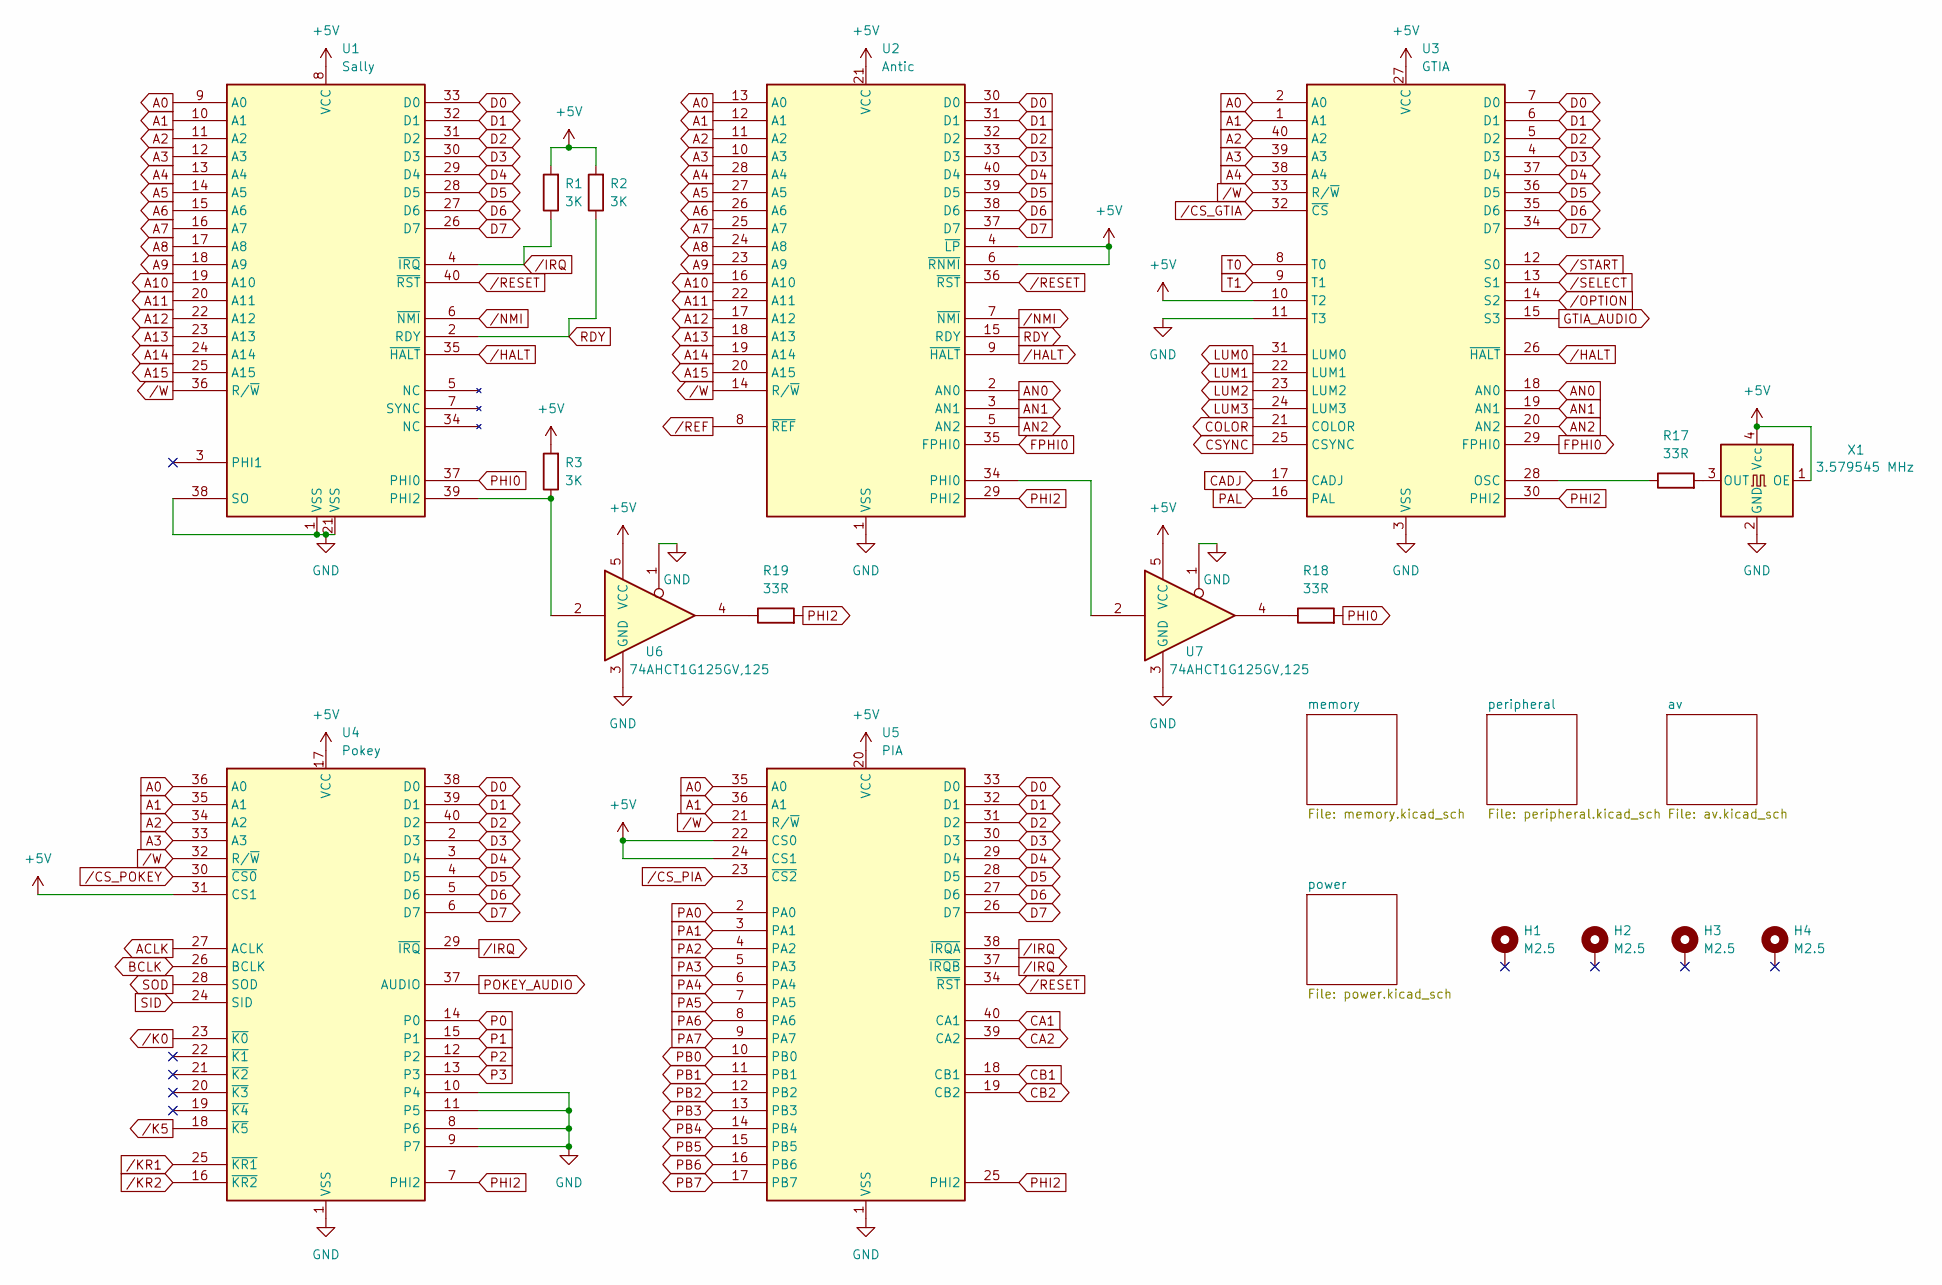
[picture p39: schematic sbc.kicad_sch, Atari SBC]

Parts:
H1, H2, H3, H4: M2.5; MountingHole_2.7mm_M2.5_Pad
R1, R2, R3: 3K; R_0805_2012Metric_Pad1.20x1.40mm_HandSolder
R17, R18, R19: 33R; R_0805_2012Metric_Pad1.20x1.40mm_HandSolder
U1: Sally; DIP-40_W15.24mm_Socket
U2: Antic; DIP-40_W15.24mm_Socket
U3: GTIA; DIP-40_W15.24mm_Socket
U4: Pokey; DIP-40_W15.24mm_Socket
U5: PIA; DIP-40_W15.24mm_Socket
U6, U7: 74AHCT1G125GV,125; SOT-23-5_HandSoldering
X1: 3.579545 MHz; Oscillator_SMD_SeikoEpson_SG8002CA-4Pin_7.0x5.0mm

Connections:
+5V: R1.2, R2.2, R3.2, U1.8 (VCC), U2.4 (~LP), U2.6 (~RNMI), U2.21 (VCC), U3.10 (T2), U3.27 (VCC), U4.17 (VCC), U4.31 (CS1), U5.20 (VCC), U5.22 (CS0), U5.24 (CS1), U6.5 (VCC), U7.5 (VCC), X1.1 (OE), X1.4 (Vcc); also elsewhere on the board
A0: U1.9 (A0), U2.13 (A0), U3.2 (A0), U4.36 (A0), U5.35 (A0); also elsewhere on the board
A1: U1.10 (A1), U2.12 (A1), U3.1 (A1), U4.35 (A1), U5.36 (A1); also elsewhere on the board
A2: U1.11 (A2), U2.11 (A2), U3.40 (A2), U4.34 (A2); also elsewhere on the board
A3: U1.12 (A3), U2.10 (A3), U3.39 (A3), U4.33 (A3); also elsewhere on the board
A4: U1.13 (A4), U2.28 (A4), U3.38 (A4); also elsewhere on the board
A5: U1.14 (A5), U2.27 (A5); also elsewhere on the board
A6: U1.15 (A6), U2.26 (A6); also elsewhere on the board
A7: U1.16 (A7), U2.25 (A7); also elsewhere on the board
A8: U1.17 (A8), U2.24 (A8); also elsewhere on the board
A9: U1.18 (A9), U2.23 (A9); also elsewhere on the board
A10: U1.19 (A10), U2.16 (A10); also elsewhere on the board
A11: U1.20 (A11), U2.22 (A11); also elsewhere on the board
A12: U1.22 (A12), U2.17 (A12); also elsewhere on the board
A13: U1.23 (A13), U2.18 (A13); also elsewhere on the board
A14: U1.24 (A14), U2.19 (A14); also elsewhere on the board
A15: U1.25 (A15), U2.20 (A15); also elsewhere on the board
ACLK: U4.27 (ACLK); also elsewhere on the board
AN0: U2.2 (AN0), U3.18 (AN0)
AN1: U2.3 (AN1), U3.19 (AN1)
AN2: U2.5 (AN2), U3.20 (AN2)
BCLK: U4.26 (BCLK); also elsewhere on the board
CA1: U5.40 (CA1); also elsewhere on the board
CA2: U5.39 (CA2); also elsewhere on the board
CADJ: U3.17 (CADJ); also elsewhere on the board
CB1: U5.18 (CB1); also elsewhere on the board
CB2: U5.19 (CB2); also elsewhere on the board
COLOR: U3.21 (COLOR); also elsewhere on the board
CSYNC: U3.25 (CSYNC); also elsewhere on the board
D0: U1.33 (D0), U2.30 (D0), U3.7 (D0), U4.38 (D0), U5.33 (D0); also elsewhere on the board
D1: U1.32 (D1), U2.31 (D1), U3.6 (D1), U4.39 (D1), U5.32 (D1); also elsewhere on the board
D2: U1.31 (D2), U2.32 (D2), U3.5 (D2), U4.40 (D2), U5.31 (D2); also elsewhere on the board
D3: U1.30 (D3), U2.33 (D3), U3.4 (D3), U4.2 (D3), U5.30 (D3); also elsewhere on the board
D4: U1.29 (D4), U2.40 (D4), U3.37 (D4), U4.3 (D4), U5.29 (D4); also elsewhere on the board
D5: U1.28 (D5), U2.39 (D5), U3.36 (D5), U4.4 (D5), U5.28 (D5); also elsewhere on the board
D6: U1.27 (D6), U2.38 (D6), U3.35 (D6), U4.5 (D6), U5.27 (D6); also elsewhere on the board
D7: U1.26 (D7), U2.37 (D7), U3.34 (D7), U4.6 (D7), U5.26 (D7); also elsewhere on the board
FPHI0: U2.35 (FPHI0), U3.29 (FPHI0)
GND: U1.1 (VSS), U1.21 (VSS), U1.38 (SO), U2.1 (VSS), U3.3 (VSS), U3.11 (T3), U4.1 (VSS), U4.8 (P6), U4.9 (P7), U4.10 (P4), U4.11 (P5), U5.1 (VSS), U6.1, U6.3 (GND), U7.1, U7.3 (GND), X1.2 (GND); also elsewhere on the board
GTIA_AUDIO: U3.15 (S3); also elsewhere on the board
LUM0: U3.31 (LUM0); also elsewhere on the board
LUM1: U3.22 (LUM1); also elsewhere on the board
LUM2: U3.23 (LUM2); also elsewhere on the board
LUM3: U3.24 (LUM3); also elsewhere on the board
unnamed: R18.1, U7.4
unnamed: R19.1, U6.4
unnamed: R3.1, U1.39 (PHI2), U6.2
unnamed: U2.34 (PHI0), U7.2
unnamed: R17.1, U3.28 (OSC)
unnamed: R17.2, X1.3 (OUT)
P0: U4.14 (P0); also elsewhere on the board
P1: U4.15 (P1); also elsewhere on the board
P2: U4.12 (P2); also elsewhere on the board
P3: U4.13 (P3); also elsewhere on the board
PA0: U5.2 (PA0); also elsewhere on the board
PA1: U5.3 (PA1); also elsewhere on the board
PA2: U5.4 (PA2); also elsewhere on the board
PA3: U5.5 (PA3); also elsewhere on the board
PA4: U5.6 (PA4); also elsewhere on the board
PA5: U5.7 (PA5); also elsewhere on the board
PA6: U5.8 (PA6); also elsewhere on the board
PA7: U5.9 (PA7); also elsewhere on the board
PAL: U3.16 (PAL); also elsewhere on the board
PB0: U5.10 (PB0); also elsewhere on the board
PB1: U5.11 (PB1); also elsewhere on the board
PB2: U5.12 (PB2); also elsewhere on the board
PB3: U5.13 (PB3); also elsewhere on the board
PB4: U5.14 (PB4); also elsewhere on the board
PB5: U5.15 (PB5); also elsewhere on the board
PB6: U5.16 (PB6); also elsewhere on the board
PB7: U5.17 (PB7); also elsewhere on the board
PHI0: R18.2, U1.37 (PHI0); also elsewhere on the board
PHI2: R19.2, U2.29 (PHI2), U3.30 (PHI2), U4.7 (PHI2), U5.25 (PHI2); also elsewhere on the board
POKEY_AUDIO: U4.37 (AUDIO); also elsewhere on the board
RDY: R2.1, U1.2 (RDY), U2.15 (RDY)
SID: U4.24 (SID); also elsewhere on the board
SOD: U4.28 (SOD); also elsewhere on the board
T0: U3.8 (T0); also elsewhere on the board
T1: U3.9 (T1); also elsewhere on the board
/CS_GTIA: U3.32 (~CS); also elsewhere on the board
/CS_PIA: U5.23 (~CS2); also elsewhere on the board
/CS_POKEY: U4.30 (~CS0); also elsewhere on the board
/HALT: U1.35 (~HALT), U2.9 (~HALT), U3.26 (~HALT); also elsewhere on the board
/IRQ: R1.1, U1.4 (~IRQ), U4.29 (~IRQ), U5.37 (~IRQB), U5.38 (~IRQA)
/K0: U4.23 (~K0); also elsewhere on the board
/K5: U4.18 (~K5); also elsewhere on the board
/KR1: U4.25 (~KR1); also elsewhere on the board
/KR2: U4.16 (~KR2); also elsewhere on the board
/NMI: U1.6 (~NMI), U2.7 (~NMI)
/OPTION: U3.14 (S2); also elsewhere on the board
/REF: U2.8 (~REF); also elsewhere on the board
/RESET: U1.40 (~RST), U2.36 (~RST), U5.34 (~RST); also elsewhere on the board
/SELECT: U3.13 (S1); also elsewhere on the board
/START: U3.12 (S0); also elsewhere on the board
/W: U1.36 (R/~W), U2.14 (R/~W), U3.33 (R/~W), U4.32 (R/~W), U5.21 (R/~W); also elsewhere on the board

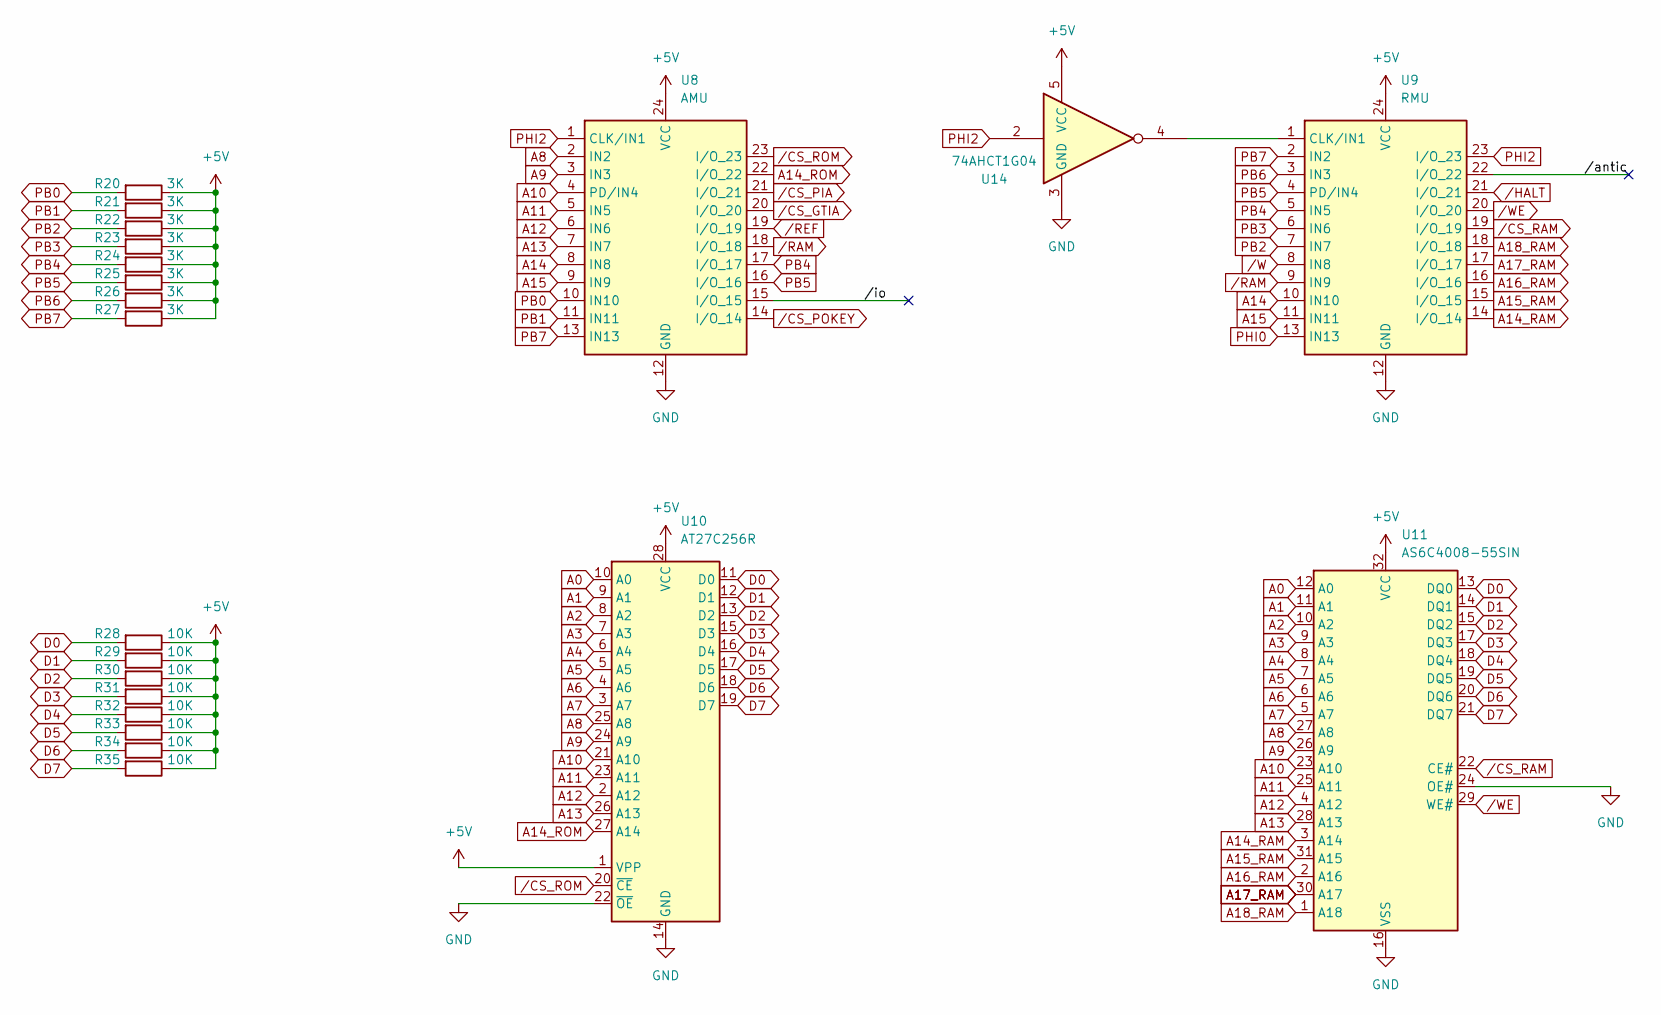
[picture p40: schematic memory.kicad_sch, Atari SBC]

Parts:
R20, R21, R22, R23, R24, R25, R26, R27: 3K; R_0805_2012Metric_Pad1.20x1.40mm_HandSolder
R28, R29, R30, R31, R32, R33, R34, R35: 10K; R_0805_2012Metric_Pad1.20x1.40mm_HandSolder
U8: AMU; DIP-24_W7.62mm_Socket
U9: RMU; DIP-24_W7.62mm_Socket
U10: AT27C256R; DIP-28_W15.24mm_Socket
U11: AS6C4008-55SIN; SOP-32_11.305x20.495mm_P1.27mm
U14: 74AHCT1G04; SOT-23-5_HandSoldering

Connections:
+5V: R20.1, R21.1, R22.1, R23.1, R24.1, R25.1, R26.1, R27.1, R28.1, R29.1, R30.1, R31.1, R32.1, R33.1, R34.1, R35.1, U8.24 (VCC), U9.24 (VCC), U10.1 (VPP), U10.28 (VCC), U11.32 (VCC), U14.5 (VCC); also elsewhere on the board
/memory//antic: U9.22 (I/O_22)
/memory//io: U8.15 (I/O_15)
A0: U10.10 (A0), U11.12 (A0); also elsewhere on the board
A1: U10.9 (A1), U11.11 (A1); also elsewhere on the board
A2: U10.8 (A2), U11.10 (A2); also elsewhere on the board
A3: U10.7 (A3), U11.9 (A3); also elsewhere on the board
A4: U10.6 (A4), U11.8 (A4); also elsewhere on the board
A5: U10.5 (A5), U11.7 (A5); also elsewhere on the board
A6: U10.4 (A6), U11.6 (A6); also elsewhere on the board
A7: U10.3 (A7), U11.5 (A7); also elsewhere on the board
A8: U8.2 (IN2), U10.25 (A8), U11.27 (A8); also elsewhere on the board
A9: U8.3 (IN3), U10.24 (A9), U11.26 (A9); also elsewhere on the board
A10: U8.4 (PD/IN4), U10.21 (A10), U11.23 (A10); also elsewhere on the board
A11: U8.5 (IN5), U10.23 (A11), U11.25 (A11); also elsewhere on the board
A12: U8.6 (IN6), U10.2 (A12), U11.4 (A12); also elsewhere on the board
A13: U8.7 (IN7), U10.26 (A13), U11.28 (A13); also elsewhere on the board
A14: U8.8 (IN8), U9.10 (IN10); also elsewhere on the board
A14_RAM: U9.14 (I/O_14), U11.3 (A14)
A14_ROM: U8.22 (I/O_22), U10.27 (A14)
A15: U8.9 (IN9), U9.11 (IN11); also elsewhere on the board
A15_RAM: U9.15 (I/O_15), U11.31 (A15)
A16_RAM: U9.16 (I/O_16), U11.2 (A16)
A17_RAM: U9.17 (I/O_17), U11.30 (A17)
A18_RAM: U9.18 (I/O_18), U11.1 (A18)
D0: R28.2, U10.11 (D0), U11.13 (DQ0); also elsewhere on the board
D1: R29.2, U10.12 (D1), U11.14 (DQ1); also elsewhere on the board
D2: R30.2, U10.13 (D2), U11.15 (DQ2); also elsewhere on the board
D3: R31.2, U10.15 (D3), U11.17 (DQ3); also elsewhere on the board
D4: R32.2, U10.16 (D4), U11.18 (DQ4); also elsewhere on the board
D5: R33.2, U10.17 (D5), U11.19 (DQ5); also elsewhere on the board
D6: R34.2, U10.18 (D6), U11.20 (DQ6); also elsewhere on the board
D7: R35.2, U10.19 (D7), U11.21 (DQ7); also elsewhere on the board
GND: U8.12 (GND), U9.12 (GND), U10.14 (GND), U10.22 (~OE), U11.16 (VSS), U11.24 (OE#), U14.3 (GND); also elsewhere on the board
unnamed: U9.1 (CLK/IN1), U14.4
PB0: R20.2, U8.10 (IN10); also elsewhere on the board
PB1: R21.2, U8.11 (IN11); also elsewhere on the board
PB2: R22.2, U9.7 (IN7); also elsewhere on the board
PB3: R23.2, U9.6 (IN6); also elsewhere on the board
PB4: R24.2, U8.17 (I/O_17), U9.5 (IN5); also elsewhere on the board
PB5: R25.2, U8.16 (I/O_16), U9.4 (PD/IN4); also elsewhere on the board
PB6: R26.2, U9.3 (IN3); also elsewhere on the board
PB7: R27.2, U8.13 (IN13), U9.2 (IN2); also elsewhere on the board
PHI0: U9.13 (IN13); also elsewhere on the board
PHI2: U8.1 (CLK/IN1), U9.23 (I/O_23), U14.2; also elsewhere on the board
/CS_GTIA: U8.20 (I/O_20); also elsewhere on the board
/CS_PIA: U8.21 (I/O_21); also elsewhere on the board
/CS_POKEY: U8.14 (I/O_14); also elsewhere on the board
/CS_RAM: U9.19 (I/O_19), U11.22 (CE#)
/CS_ROM: U8.23 (I/O_23), U10.20 (~CE)
/HALT: U9.21 (I/O_21); also elsewhere on the board
/RAM: U8.18 (I/O_18), U9.9 (IN9)
/REF: U8.19 (I/O_19); also elsewhere on the board
/W: U9.8 (IN8); also elsewhere on the board
/WE: U9.20 (I/O_20), U11.29 (WE#)

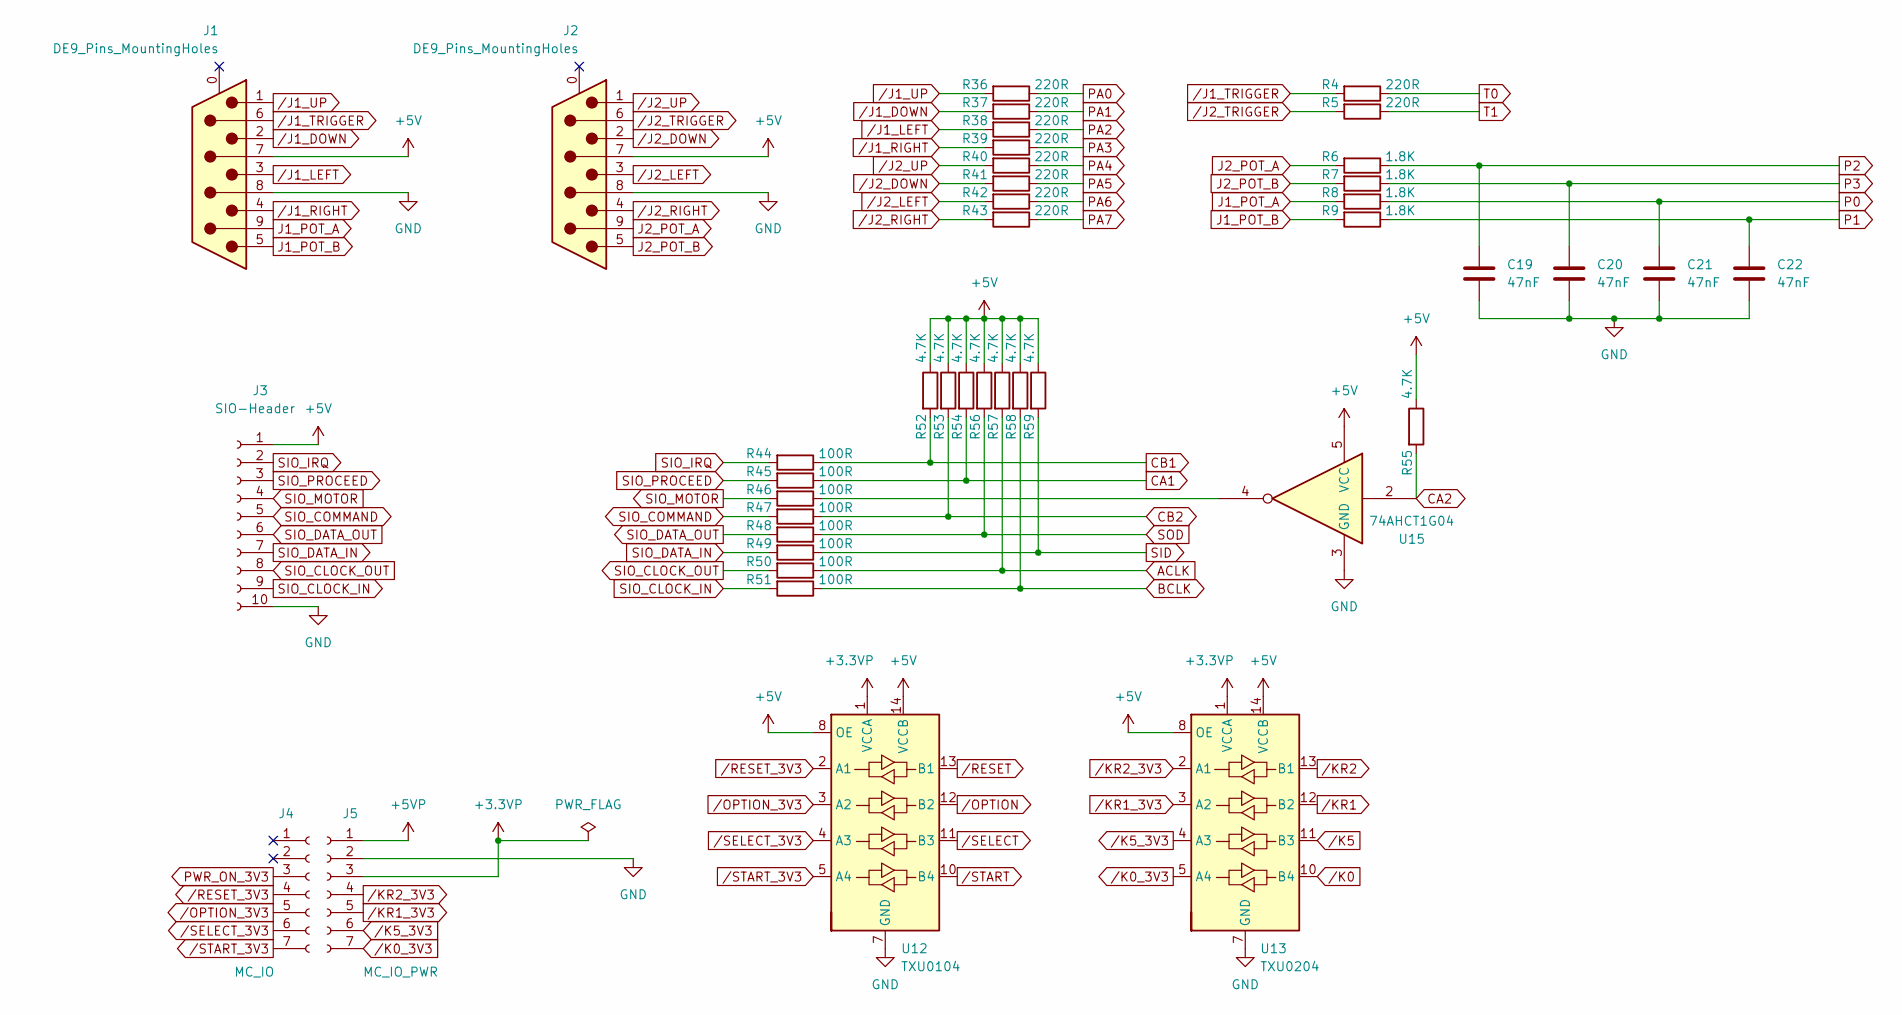
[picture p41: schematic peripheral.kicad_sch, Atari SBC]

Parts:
C19, C20, C21, C22: 47nF; C_0805_2012Metric_Pad1.18x1.45mm_HandSolder
J1, J2: DE9_Pins_MountingHoles; DSUB-9_Pins_Horizontal_P2.77x2.84mm_EdgePinOffset4.94mm_Hou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
J3: SIO-Header; PinSocket_1x10_P2.54mm_Vertical
J4: MC_IO; PinSocket_1x07_P2.54mm_Vertical
J5: MC_IO_PWR; PinSocket_1x07_P2.54mm_Vertical
R4, R5, R36, R37, R38, R39, R40, R41, R42, R43: 220R; R_0805_2012Metric_Pad1.20x1.40mm_HandSolder
R6, R7, R8, R9: 1.8K; R_0805_2012Metric_Pad1.20x1.40mm_HandSolder
R44, R45, R46, R47, R48, R49, R50, R51: 100R; R_0805_2012Metric_Pad1.20x1.40mm_HandSolder
R52, R53, R54, R55, R56, R57, R58, R59: 4.7K; R_0805_2012Metric_Pad1.20x1.40mm_HandSolder
U12: TXU0104; TSSOP-14_4.4x5mm_P0.65mm
U13: TXU0204; TSSOP-14_4.4x5mm_P0.65mm
U15: 74AHCT1G04; SOT-23-5_HandSoldering

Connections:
+3.3VP: J5.3, U12.1 (VCCA), U13.1 (VCCA); also elsewhere on the board
+5V: J1.7, J2.7, J3.1, R52.1, R53.1, R54.1, R55.1, R56.1, R57.1, R58.1, R59.1, U12.8 (OE), U12.14 (VCCB), U13.8 (OE), U13.14 (VCCB), U15.5 (VCC); also elsewhere on the board
+5VP: J5.1; also elsewhere on the board
ACLK: R50.1, R57.2; also elsewhere on the board
BCLK: R51.1, R58.2; also elsewhere on the board
CA1: R45.1, R54.2; also elsewhere on the board
CA2: R55.2, U15.2; also elsewhere on the board
CB1: R44.1, R52.2; also elsewhere on the board
CB2: R47.1, R53.2; also elsewhere on the board
GND: C19.2, C20.2, C21.2, C22.2, J1.8, J2.8, J3.10, J5.2, U12.7 (GND), U13.7 (GND), U15.3 (GND); also elsewhere on the board
J1_POT_A: J1.9, R8.2
J1_POT_B: J1.5, R9.2
J2_POT_A: J2.9, R6.2
J2_POT_B: J2.5, R7.2
unnamed: R46.1, U15.4
P0: C21.1, R8.1; also elsewhere on the board
P1: C22.1, R9.1; also elsewhere on the board
P2: C19.1, R6.1; also elsewhere on the board
P3: C20.1, R7.1; also elsewhere on the board
PA0: R36.1; also elsewhere on the board
PA1: R37.1; also elsewhere on the board
PA2: R38.1; also elsewhere on the board
PA3: R39.1; also elsewhere on the board
PA4: R40.1; also elsewhere on the board
PA5: R41.1; also elsewhere on the board
PA6: R42.1; also elsewhere on the board
PA7: R43.1; also elsewhere on the board
PWR_ON_3V3: J4.3; also elsewhere on the board
SID: R49.1, R59.2; also elsewhere on the board
SIO_CLOCK_IN: J3.9, R51.2
SIO_CLOCK_OUT: J3.8, R50.2
SIO_COMMAND: J3.5, R47.2
SIO_DATA_IN: J3.7, R49.2
SIO_DATA_OUT: J3.6, R48.2
SIO_IRQ: J3.2, R44.2
SIO_MOTOR: J3.4, R46.2
SIO_PROCEED: J3.3, R45.2
SOD: R48.1, R56.2; also elsewhere on the board
T0: R4.1; also elsewhere on the board
T1: R5.1; also elsewhere on the board
/J1_DOWN: J1.2, R37.2
/J1_LEFT: J1.3, R38.2
/J1_RIGHT: J1.4, R39.2
/J1_TRIGGER: J1.6, R4.2
/J1_UP: J1.1, R36.2
/J2_DOWN: J2.2, R41.2
/J2_LEFT: J2.3, R42.2
/J2_RIGHT: J2.4, R43.2
/J2_TRIGGER: J2.6, R5.2
/J2_UP: J2.1, R40.2
/K0: U13.10 (B4); also elsewhere on the board
/K0_3V3: J5.7, U13.5 (A4)
/K5: U13.11 (B3); also elsewhere on the board
/K5_3V3: J5.6, U13.4 (A3)
/KR1: U13.12 (B2); also elsewhere on the board
/KR1_3V3: J5.5, U13.3 (A2)
/KR2: U13.13 (B1); also elsewhere on the board
/KR2_3V3: J5.4, U13.2 (A1)
/OPTION: U12.12 (B2); also elsewhere on the board
/OPTION_3V3: J4.5, U12.3 (A2)
/RESET: U12.13 (B1); also elsewhere on the board
/RESET_3V3: J4.4, U12.2 (A1)
/SELECT: U12.11 (B3); also elsewhere on the board
/SELECT_3V3: J4.6, U12.4 (A3)
/START: U12.10 (B4); also elsewhere on the board
/START_3V3: J4.7, U12.5 (A4)

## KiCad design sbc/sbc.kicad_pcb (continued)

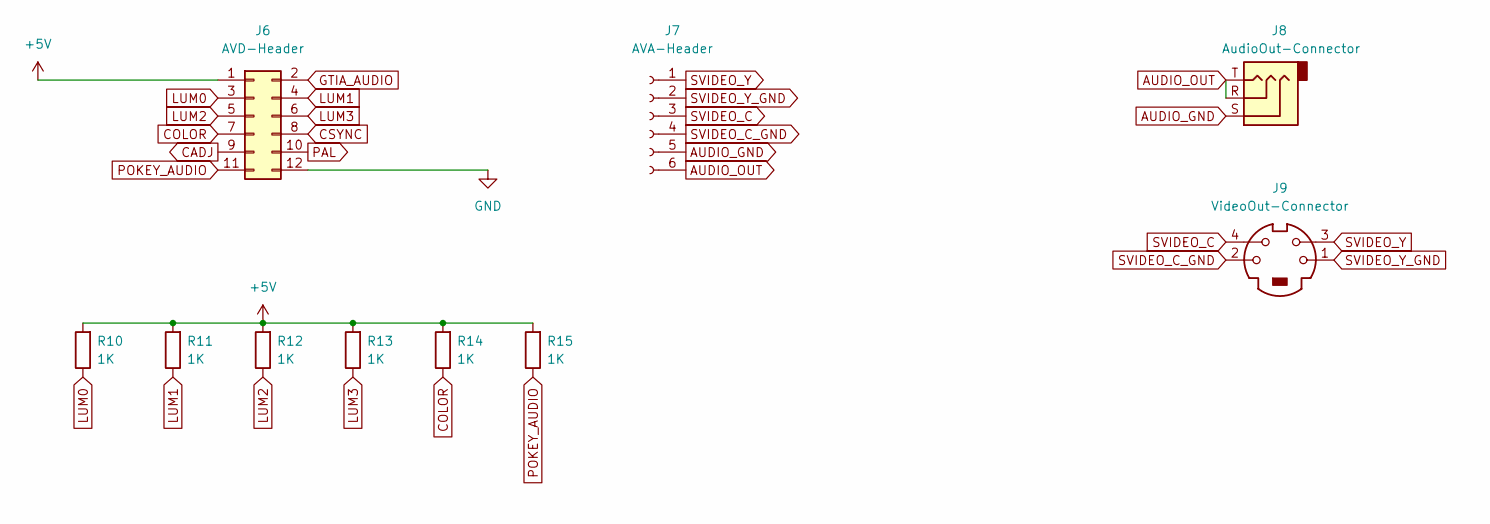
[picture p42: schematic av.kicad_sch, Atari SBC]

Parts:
J6: AVD-Header; PinSocket_2x06_P2.54mm_Vertical
J7: AVA-Header; PinSocket_1x06_P2.54mm_Vertical
J8: AudioOut-Connector; Jack_3.5mm_CUI_SJ1-3533NG_Horizontal
J9: VideoOut-Connector; 57492631
R10, R11, R12, R13, R14, R15: 1K; R_0805_2012Metric_Pad1.20x1.40mm_HandSolder

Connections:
+5V: J6.1, R10.2, R11.2, R12.2, R13.2, R14.2, R15.2; also elsewhere on the board
AUDIO_GND: J7.5, J8.S
AUDIO_OUT: J7.6, J8.R, J8.T
CADJ: J6.9; also elsewhere on the board
COLOR: J6.7, R14.1; also elsewhere on the board
CSYNC: J6.8; also elsewhere on the board
GND: J6.12; also elsewhere on the board
GTIA_AUDIO: J6.2; also elsewhere on the board
LUM0: J6.3, R10.1; also elsewhere on the board
LUM1: J6.4, R11.1; also elsewhere on the board
LUM2: J6.5, R12.1; also elsewhere on the board
LUM3: J6.6, R13.1; also elsewhere on the board
PAL: J6.10; also elsewhere on the board
POKEY_AUDIO: J6.11, R15.1; also elsewhere on the board
SVIDEO_C: J7.3, J9.4
SVIDEO_C_GND: J7.4, J9.2
SVIDEO_Y: J7.1, J9.3
SVIDEO_Y_GND: J7.2, J9.1

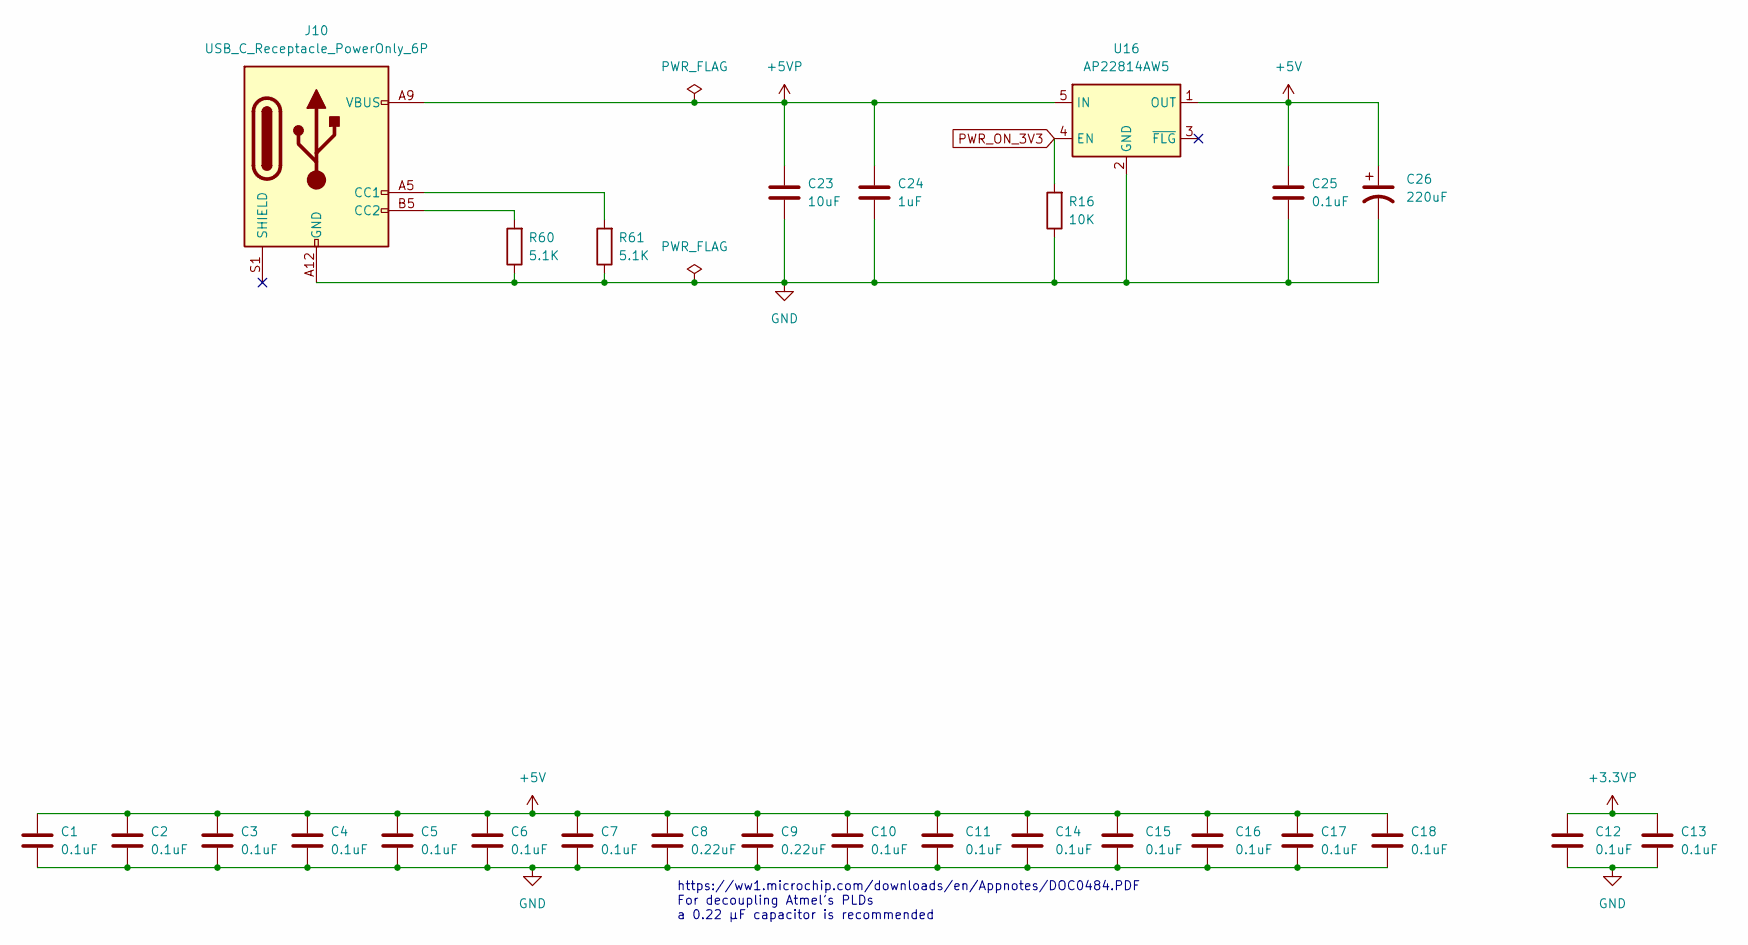
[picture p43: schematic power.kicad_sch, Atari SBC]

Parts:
C1, C2, C3, C4, C5, C6, C7, C10, C11, C12, C13, C14, C15, C16, C17, C18, C25: 0.1uF; C_0805_2012Metric_Pad1.18x1.45mm_HandSolder
C8, C9: 0.22uF; C_0805_2012Metric_Pad1.18x1.45mm_HandSolder
C23: 10uF; C_0805_2012Metric_Pad1.18x1.45mm_HandSolder
C24: 1uF; C_0805_2012Metric_Pad1.18x1.45mm_HandSolder
C26: 220uF; CP_Radial_D6.3mm_P2.50mm
J10: USB_C_Receptacle_PowerOnly_6P; USB_C_Receptacle_GCT_USB4125-xx-x_6P_TopMnt_Horizontal
R16: 10K; R_0805_2012Metric_Pad1.20x1.40mm_HandSolder
R60, R61: 5.1K; R_0805_2012Metric_Pad1.20x1.40mm_HandSolder
U16: AP22814AW5; SOT-23-5

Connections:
+3.3VP: C12.1, C13.1; also elsewhere on the board
+5V: C1.1, C2.1, C3.1, C4.1, C5.1, C6.1, C7.1, C8.1, C9.1, C10.1, C11.1, C14.1, C15.1, C16.1, C17.1, C18.1, C25.1, C26.1, U16.1 (OUT); also elsewhere on the board
+5VP: C23.1, C24.1, J10.A9 (VBUS), J10.B9 (VBUS), U16.5 (IN); also elsewhere on the board
GND: C1.2, C2.2, C3.2, C4.2, C5.2, C6.2, C7.2, C8.2, C9.2, C10.2, C11.2, C12.2, C13.2, C14.2, C15.2, C16.2, C17.2, C18.2, C23.2, C24.2, C25.2, C26.2, J10.A12 (GND), J10.B12 (GND), R16.1, R60.1, R61.1, U16.2 (GND); also elsewhere on the board
unnamed: J10.A5 (CC1), R61.2
unnamed: J10.B5 (CC2), R60.2
PWR_ON_3V3: R16.2, U16.4 (EN); also elsewhere on the board

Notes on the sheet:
https://ww1.microchip.com/downloads/en/Appnotes/DOC0484.PDF For decoupling Atmel's PLDs a 0.22 μF capacitor is recommended

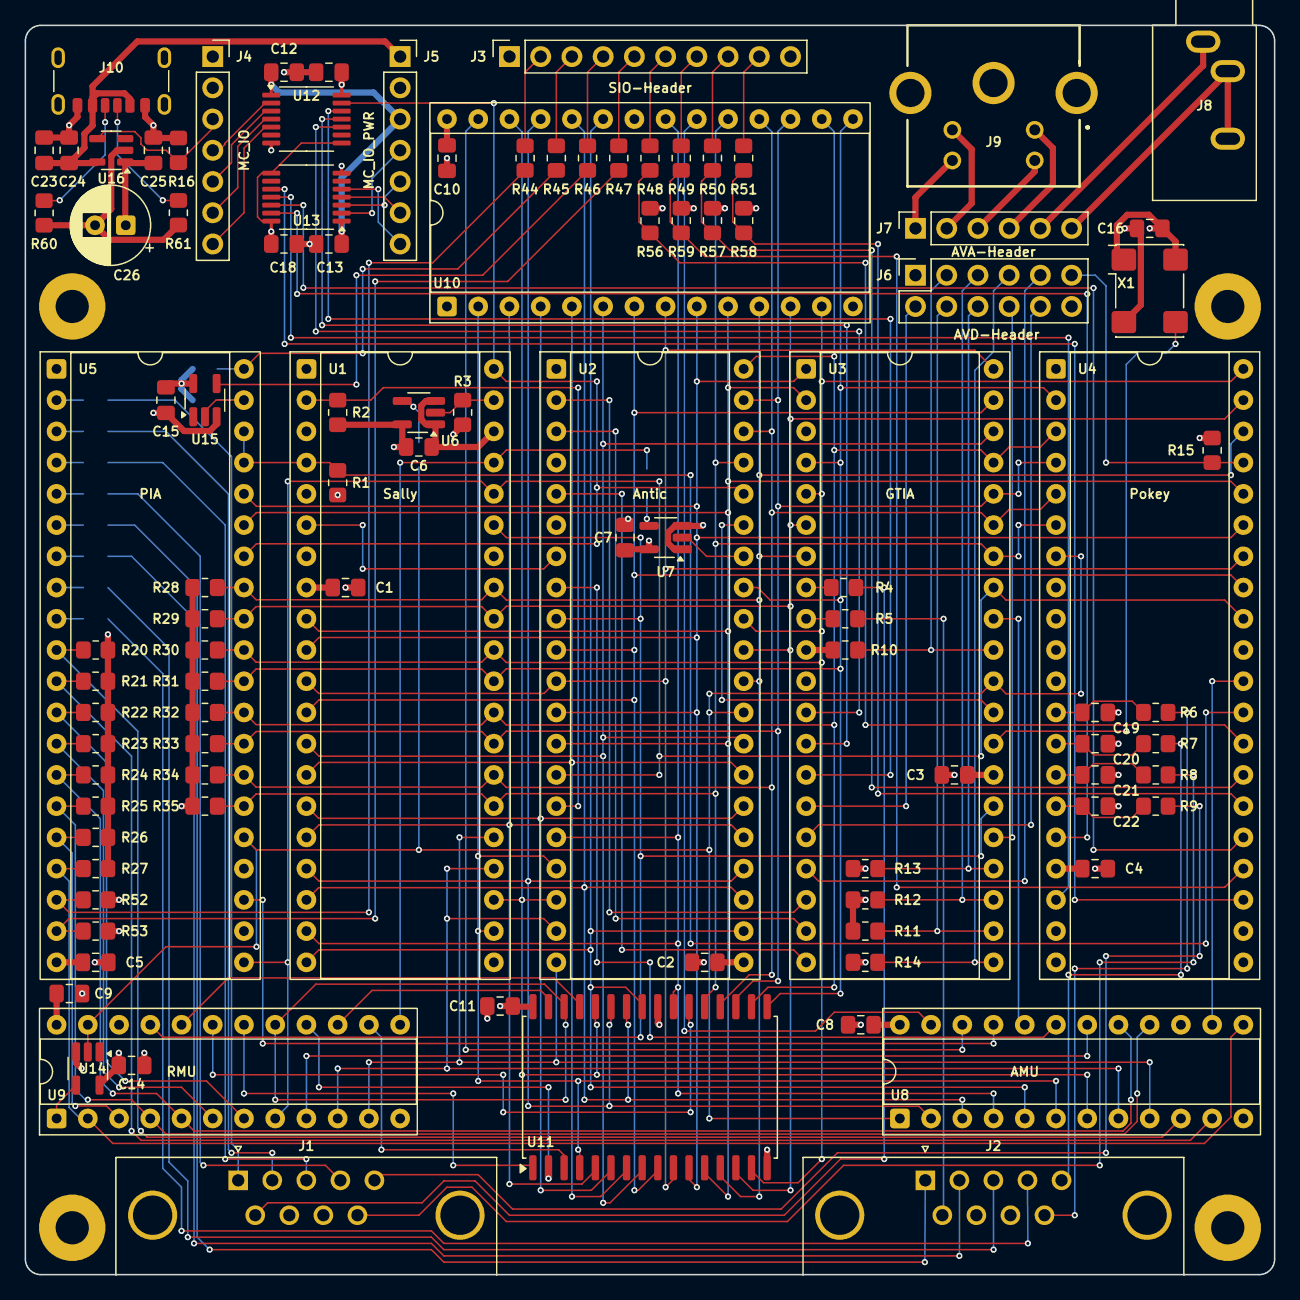
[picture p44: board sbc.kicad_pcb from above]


Board: 4 copper layers, 101.6 x 101.6 mm, 118 parts (13 on the bottom side), 148 nets.

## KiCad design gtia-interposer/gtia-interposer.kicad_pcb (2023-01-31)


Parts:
C1, C2: 0.1uF; C_0805_2012Metric_Pad1.18x1.45mm_HandSolder
J1: GTIA_INTERPOSER; PinHeader_1x05_P2.54mm_Vertical
U1: Atari-GTIA; DIP-40_W15.24mm_Socket
U2: TXU0304; TSSOP-14_4.4x5mm_P0.65mm

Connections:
+3V3: C2.1, J1.1, U2.8 (OE), U2.14 (VCCB)
+5V: C1.1, U1.27 (VCC), U2.1 (VCCA)
GND: C1.2, C2.2, J1.2, U1.3 (VSS), U2.7 (GND)
/SW_OPTION: U1.14 (S2), U2.13 (B1)
/SW_OPTION_3V3: J1.5, U2.2 (A1)
/SW_SELECT: U1.13 (S1), U2.12 (B2)
/SW_SELECT_3V3: J1.4, U2.3 (A2)
/SW_START: U1.12 (S0), U2.11 (B3)
/SW_START_3V3: J1.3, U2.4 (A3)


Board: 4 copper layers, 20.3 x 57.2 mm, 5 parts (0 on the bottom side), 9 nets.

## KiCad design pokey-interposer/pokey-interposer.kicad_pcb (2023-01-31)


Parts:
C1, C2: 0.1uF; C_0805_2012Metric_Pad1.18x1.45mm_HandSolder
J1: POKEY_INTERPOSER; PinHeader_1x06_P2.54mm_Vertical
J2: POWER_OUT_5V; PinHeader_1x02_P2.54mm_Vertical
U1: Atari-Pokey; DIP-40_W15.24mm_Socket
U2: TXU0204; TSSOP-14_4.4x5mm_P0.65mm

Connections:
+3V3: C1.1, J1.1, U2.1 (VCCA)
+5V: C2.1, J2.1, U1.17 (VCC), U2.8 (OE), U2.14 (VCCB)
GND: C1.2, C2.2, J1.2, J2.2, U1.1 (VSS), U2.7 (GND)
/K0: U1.23 (~K0), U2.10 (B4)
/K0_3V3: J1.3, U2.5 (A4)
/K5: U1.18 (~K5), U2.11 (B3)
/K5_3V3: J1.4, U2.4 (A3)
/KR1: U1.25 (~KR1), U2.12 (B2)
/KR1_3V3: J1.5, U2.3 (A2)
/KR2: U1.16 (~KR2), U2.13 (B1)
/KR2_3V3: J1.6, U2.2 (A1)


Board: 4 copper layers, 20.3 x 61.0 mm, 6 parts (0 on the bottom side), 11 nets.

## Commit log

2023-01-31 Pokey and GTIA interposers with SAMD-based USB keyboard controller
    [gtia-interposer.kicad_pcb, gtia-interposer.kicad_sch, keyboard-usb.kicad_pcb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]
2023-01-31 Remove the SAMD-based USB keyboard controller
    Microchip want ~$200 for a SAMD programmer. RP2040 has a cheaper/simpler/better ecosystem.
    [keyboard-usb.kicad_pcb, keyboard-usb.kicad_sch]
2023-01-31 KiCad symbols and footprints to support an 8-bit Atari SBC
2023-04-09 8-bit Atari SBC
    [av.kicad_sch, memory.kicad_sch, peripheral.kicad_sch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]
2023-09-02 SBC v1.1
    PCB fixes/changes:
    - Permanently power voltage translators
    - Conservatively specified a slower SRAM (the previous/faster SRAM does actually work fine)
    - RMU: Speculatively provided unbuffered PHI0 input and OE output (not actually needed)
    - Add pullups to open drain GTIA outputs
    - Plot selected values on silk screen
    - Accommodate KiCad 7 upgrade
    - PLD changes:
    - Fix AMU logic
    - Fix RMU (unbuffered PHI0 and OE output not needed)
    - QTPY firmware:
    - add soft power on/off support (Ctrl-F12)
    - reflects switched power and usb state in the neopixel
    [av.kicad_sch, memory.kicad_sch, peripheral.kicad_sch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]
2023-10-17 SBC v1.2
    SBC fixes/changes:
    - S-Video:
    - Fix S-Video footprint (Y and C swapped, and GNDs swapped) and adapt schematic to match
    - Wire S-Video grounds to AVA header instead of directly to (digital) GND
    - Audio:
    - Wire Audio-Out ground to AVA header
    - Drop SIO audio
    - Pullup open drain pokey audio
    - AMU/RMU:
    - Connect ROM and RAM OE to GND
    - Reserve AMU pin for "IO"
    - Reserve RMU pin for "antic" (registered halt)
    - Support for separate Antic banking (clock RMU with /phi2)
    - Supoprt 130XE and 320XE (compy)
    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
    [av.kicad_sch, memory.kicad_sch, peripheral.kicad_sch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]
2024-11-09 SD card adapter v1.2
    - Move SD card connector closer to the edge of the board
    - Pullup SD detect signal to non-switched 5V
    - Eliminate SD DO pullup
    - Move LDO closer to SD
    [sbc-sd.kicad_pcb, sbc-sd.kicad_sch]
2026-02-07 Refresh firmware images
    - add GPT partition support
    - add xex file loading
    - search for !sbc-filer.xex and !sbc-xex-loader.atr on the SD card and builtin devices
    - case-insensitive file name extension matching in the sio file system device
    - exFat fixes (cluster-chain following and deleted directory entry skipping)
2026-04-14 SBC v1.3
    Motherboard updates:
    - KiCad 9 upgrade
    - USB-C power connector
    - Replace EOL resistor packs with discrete SMD resistors
    - Power/enable voltage translators from switched 5V
    - Fix motor signal pullup
    - Eliminate loop in phi2 traces
    - Thicker clock signal traces
    SD card adapter updates:
    - KiCad 9 upgrade
    - Power/enable voltage translator from switched 5V and the eliminate unnecessary SIO pullups
    Audio/Video adapter updates:
    - KiCad 9 upgrade
    - No functional changes, gerbers not regenerated, cleaned up bom
    [av.kicad_sch, memory.kicad_sch, peripheral.kicad_sch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]

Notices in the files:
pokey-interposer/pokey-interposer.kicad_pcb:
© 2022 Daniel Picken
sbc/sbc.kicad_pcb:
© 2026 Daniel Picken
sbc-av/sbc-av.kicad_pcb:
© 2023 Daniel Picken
